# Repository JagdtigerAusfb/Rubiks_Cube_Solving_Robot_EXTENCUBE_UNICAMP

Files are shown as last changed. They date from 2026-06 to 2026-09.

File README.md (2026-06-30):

# RAIDEN

This repository contains everything related to the Rubik's Cube solving robot, **Raiden** and its second version: **Tupã**. This project was developed as an extension project at the State University of Campinas (UNICAMP).

## Introduction

The goal of this project was to develop a simple Rubik's Cube solving robot using accessible, easy-to-use, and relatively inexpensive components.This was achieved by building our first bot: the RAIDEN, named after the Japanese god of thunder, shown in the picture below. After its completion, the second iteration, the TUPÃ, named after Tupi-Guarani mythology, also shown in the picture below, was built using more expensive components, with the goal of minimizing completion times.

The RAIDEN achieved a record time of 1.82 seconds using a 19-move solution, running at a speed of 750 µs.

The TUPÃ achieved a record time of X.XX seconds using a 19-move solution, running at a speed of XXX µs.

See a video of the completed robot in action below: 

[Insert Video Link Here]

## Documentation & Guides

* Read the **[README]** files contained in each directory for details on each of the bot's parts. 
* Read the **[User's Manual]** for a full description of the parts, the complete bill of materials, and relevant technical documentation.
* Read the **[Build Tutorial]** for a step-by-step guide on how to build and configure this project yourself.

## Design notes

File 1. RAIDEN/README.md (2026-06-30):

# RAIDEN

**[WORK IN PROGRESS]**

Repository with all the material for **Raiden**, a Rubik's Cube solving robot developed as an extension project at UNICAMP. The goal is to solve the cube using 6 stepper motors (one per face), color sensors to read the cube's state, and an Arduino Mega as the central controller.

## Repository structure

```
1. RAIDEN/
├── 3D Files/              # 3D models of the robot's mechanical structure (in preparation)
├── PCB/                   # Circuit boards (KiCad projects)
│   ├── PCB 3 Drivers/
│   ├── PCB Drivers + Sensores/
│   └── PCB TUPAN/
└── Software/              # Arduino firmware and PC control applications
    ├── arduino/
    ├── Cube3D/
    └── CubeApp/
```

### `3D Files/`
Folder intended for the mechanical structure's 3D modeling files (chassis, motor mounts, base, etc.). See **[PCB/README.md](3D/README.md)** for details on the files.

### `PCB/`
KiCad projects for the robot's Printed Circuit Board desgins. See **[PCB/README.md](PCB/README.md)** for board details and pinout.

### `Software/`
All the code that runs the robot: the Arduino firmware and Python files. See **[Software/README.md](Software/README.md)** for details.

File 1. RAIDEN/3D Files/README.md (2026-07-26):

# 3D Files
This directory contains all the 3D files of the bot.

## Final Product
The assembled bot measures XX by XX by XX centimeters. Note that behind each side motor there is space for a rectangular piece that prevents the motor from sliding backwards — we highly recommend using it.
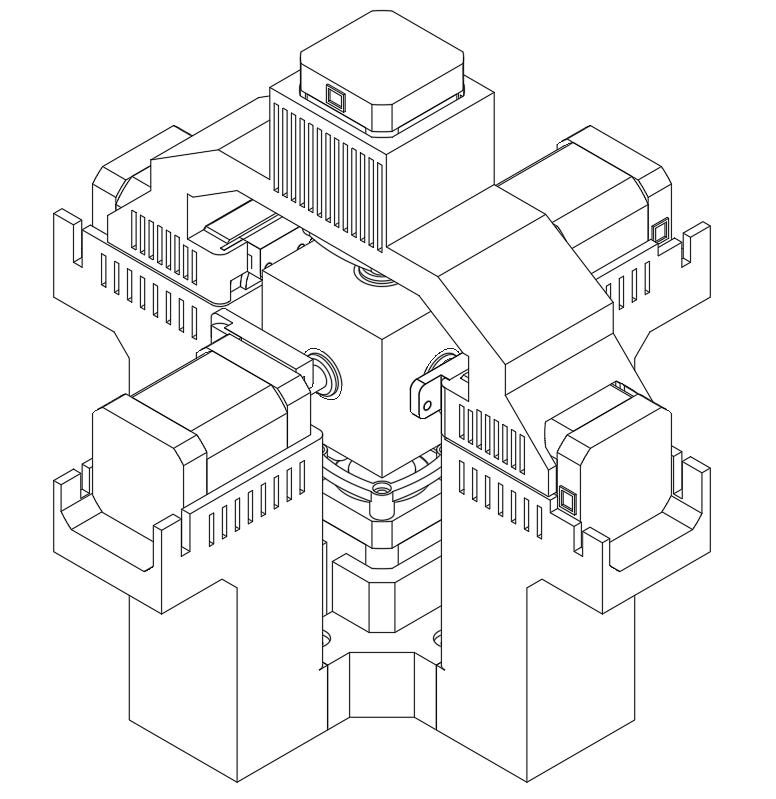
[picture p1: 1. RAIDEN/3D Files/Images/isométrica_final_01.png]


The following are the individual parts:

## The Claw
Our stepper motor has a fully cylindrical shaft, which made it very difficult to secure the claw firmly in place. If your stepper motor has a chamfered shaft — which we highly recommend — you will need to modify the claw design to fit it.
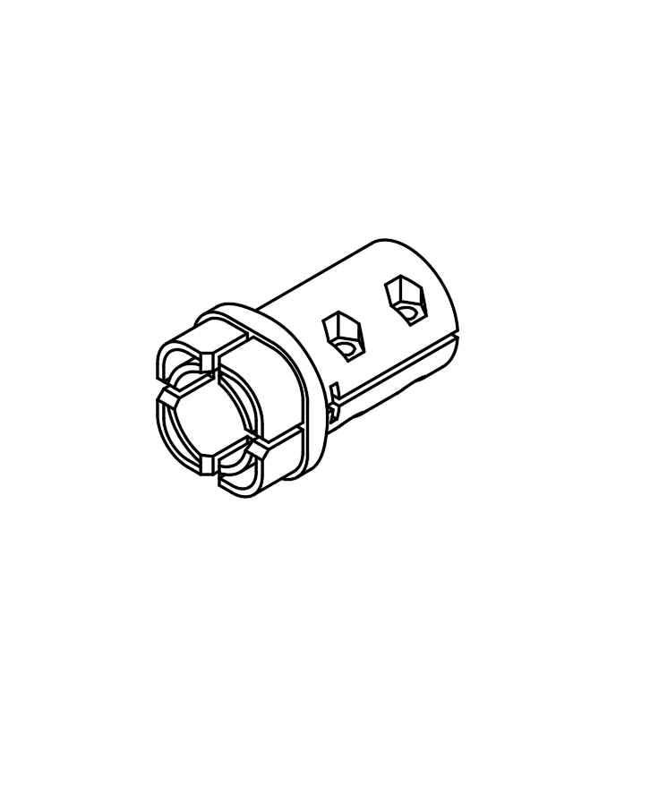
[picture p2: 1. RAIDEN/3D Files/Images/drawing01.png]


## The Tower
Four of these towers support each side motor and are bolted to the main piece using XX bolts.
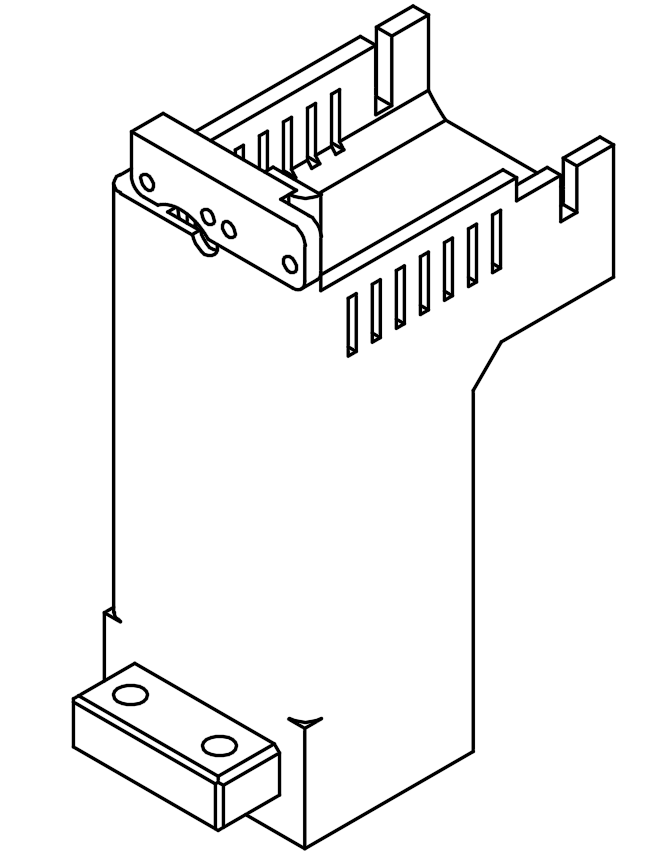
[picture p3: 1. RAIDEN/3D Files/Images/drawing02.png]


## The Base
A motor is placed inside this base facing upward, and the four towers attach to each of its sides.
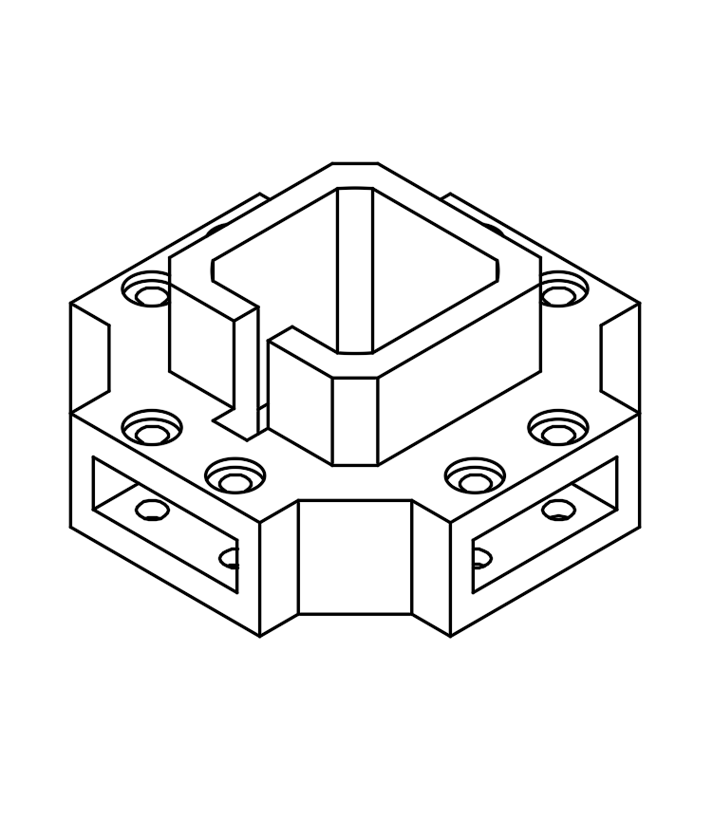
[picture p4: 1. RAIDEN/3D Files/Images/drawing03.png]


## The Top
The top piece sits on top of two opposing motors, with the last motor mounted inside it, facing downward.
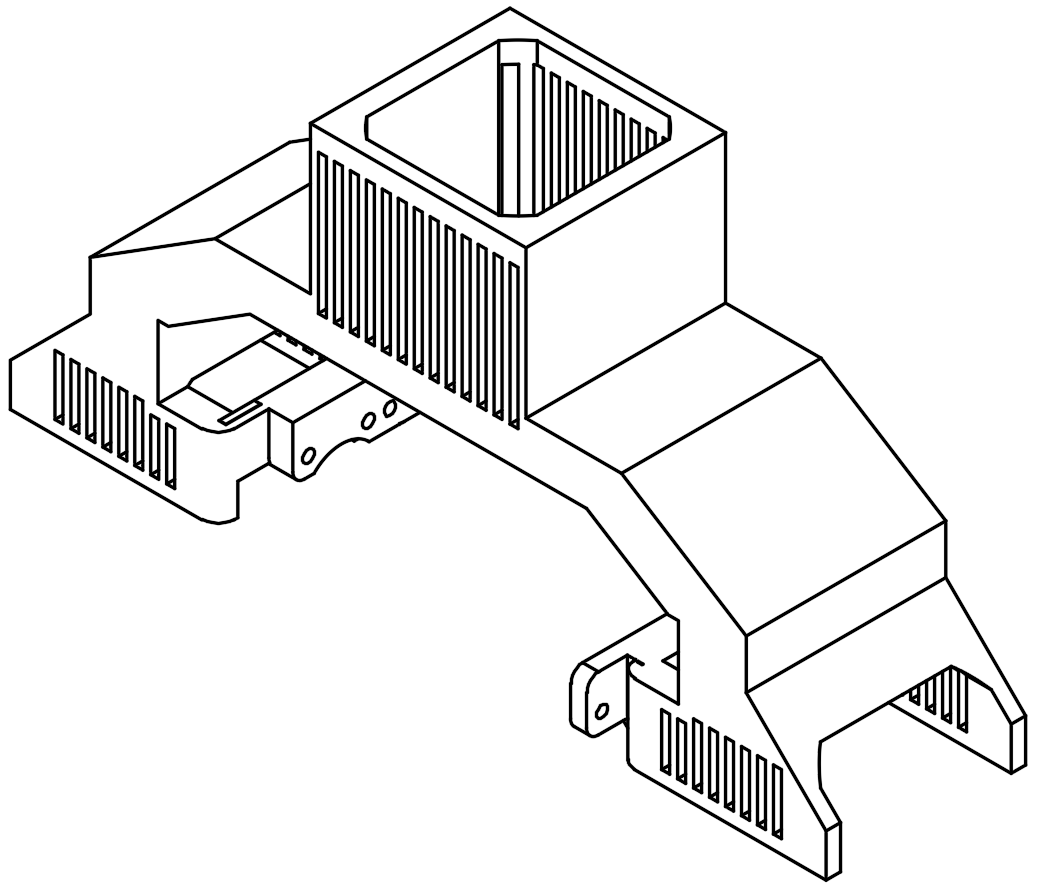
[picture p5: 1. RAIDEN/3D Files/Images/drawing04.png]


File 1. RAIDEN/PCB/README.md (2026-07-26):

# RAIDEN — PCB

KiCad projects for Raiden's electronics.

## Boards

### `PCB Drivers + Sensores/` — Main board
Shield for the **Arduino Mega**, responsible for all the power delivery and sensor reading in the robot:

- **6x A4988 stepper motor drivers** (Pololu modules), one for each face of the cube
- **12x connectors for TCS34725 color sensors**
- **1x CD74HC4067 multiplexer** to manage the 12 I²C sensor inputs
- 2x 12 V DC jack connectors (redundant power supply; using both is recommended to avoid voltage drops and motor stalling)
- Indicator LEDs (per driver and per power rail) and a reset button — both optional
- Decoupling capacitors on the drivers — **strongly recommended**, even though optional

The folder includes the complete KiCad project (schematic, PCB, custom footprints), fabrication files (Gerber, drill, BOM, component positions in `production/`), and the board's 3D model (`.step`).

### `PCB 3 Drivers/`
A simpler board with only **3 A4988 drivers**, made before the definitive board (Drivers + Sensores) to replace breadboards and reduce wiring.

As this board does not have a fixed pin layout, remember to change the respetive pins to the ones you are using in Arduino IDE.

## Reference pinout (Drivers + Sensores board)

**A4988 drivers** (DIR / STEP / ENABLE pins):

| Driver | DIR | STEP | ENABLE |
|---|---|---|---|
| 1 | A0 | A1 | A2 |
| 2 | A3 | A4 | A5 |
| 3 | A6 | A7 | A8 |
| 4 | 53 | 51 | 49 |
| 5 | 43 | 41 | 39 |
| 6 | 29 | 27 | 25 |

Microstepping pins (MS) are left disconnected, and RESET/SLEEP are tied together — this only works because the drivers used have internal pull-up/pull-down resistors.

**TCS34725 sensors** (LED control pin on the Arduino): 13, 12, 11, 10, 9, 8, 14, 15, 16, 17, 18, 19 (sensors 1 through 12, respectively).

**CD74HC4067 multiplexer** (selection): S0=5, S1=4, S2=3, S3=2. Inputs C0–C11 connected to signals SDA_1 through SDA_12.

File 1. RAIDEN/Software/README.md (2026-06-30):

# RAIDEN — Software

This folder contains all the software for our first Rubik's Cube solving robot: the **Raiden**, the Arduino firmware that drives the motors, and two separate Python applications used to control the robot from a PC.

## Repository structure

```
Software/
├── arduino/        # Firmware that runs on the Arduino Mega
├── Cube3D/         # OpenGL 3D viewer + manual/serial control app
└── CubeApp/        # PyQt6 GUI with camera-based cube scanning (main application)
```

### `arduino/arduino.ino`
Firmware for the **Arduino Mega**, controlling the 6 A4988 stepper drivers (one per face: U, R, F, D, L, B). It listens on serial (9600 baud) for a simple text protocol:

- `<START>` — begins a new move sequence
- `<SPEED:n>` — sets the step pulse delay in microseconds
- `<DELAY:n>` — sets the delay between moves in milliseconds
- One line per move, using a single-letter code (`A`–`R`, 3 codes per face: CW, CCW, 180°)
- `<END>` — executes the buffered sequence and replies `DONE <seconds>` when finished

As an optimization, opposite faces (e.g. U/D, F/B, L/R) detected as consecutive moves are driven **simultaneously** (`executarDuplo`) instead of sequentially, reducing total solve time. The `.ino` file must be uploaded manually through the Arduino IDE — it is not flashed automatically by the PC software.

### `Cube3D/`
A OpenGL/Pygame application that renders an interactive 3D Rubik's Cube on screen and can drive the physical robot over serial. This application was made for demonstration purposes and can be used to directly control the motors using a keyboard.

- `main.py` — window/render loop, keyboard controls for manual face rotations
- `cube/rubiks_cube.py` — cube data model and 3D rendering of each cubie
- `cube/solver.py` — wraps the `kociemba` solver and converts its output into the robot's serial move codes
- `robot/controller.py` — serial connection handling (auto-detects COM port) and move dispatch, mirroring the Arduino protocol above
- `ui/hud.py`, `ui/settings.py` — on-screen HUD/overlay and a Tkinter settings window for serial port/speed
- `config.py` — paths, color map, and the Kociemba → robot move-code lookup table
- `data/cube_state.json` — last saved cube state

### `CubeApp/` — main application
A PyQt6 desktop app that scans the physical cube with a webcam, solves it, and sends the solution to the robot. Pages are stacked in a `QStackedWidget` and flow as:

1. **`ui/cover.py`** — home/control panel: choose solver, set robot speed/delay, trigger solve & send
2. **`ui/calibration.py`** — lets the user position a 3×3 ROI (region of interest) grid over the cube face in the camera feed
3. **`ui/color_calib.py`** — captures reference color samples (HSV/Lab/RGB) for each of the 6 face colors, in the order defined by `COLOR_ORDER`
4. **`ui/capture.py`** — scans all 6 faces using the calibrated ROIs/colors and writes the result to `data/cube_state.json`

Supporting modules:

- `vision/camera.py` — OpenCV ↔ Qt frame conversion and ROI grid overlay
- `vision/classifier.py` — extracts mean HSV/Lab/RGB per cell and classifies it against the calibrated reference colors (nearest-neighbor via Euclidean distance)
- `solver/kociemba.py` — standard two-phase Kociemba solve
- `solver/m2op.py` — alternative M2/OP (blind-solving method) solver
- `solver/utils.py` — shared helpers: move counting, move inversion, and conversion to the robot's serial sequence
- `robot/controller.py` — same role as in `Cube3D`, but reads serial parameters (baud rate, timeouts, init delay) from `config.py`
- `config.py` — paths, color↔face mapping (`COLOR_TO_FACE`), Kociemba→robot `MOVE_TABLE`, and UI/serial defaults (e.g. `SERIAL_INIT_DELAY = 3` — required for the Arduino's DTR reset)

## Requirements

- **Arduino IDE** (or equivalent) to upload `arduino/arduino.ino`
- **Python 3.x**
- On Windows, **Microsoft Visual C++ Build Tools 14+** (required by some packages)

Python dependencies (install with pip):

```
pip install PyQt6 opencv-python numpy pyserial kociemba pygame PyOpenGL PyOpenGL-accelerate
```

| Library | Used for |
|---|---|
| `PyQt6` | GUI windows, layouts and widgets (`CubeApp`) |
| `opencv-python` | Camera capture and color-space conversion (BGR/HSV/Lab) |
| `numpy` | Array math and color-distance calculations |
| `pyserial` | Serial communication with the Arduino over USB |
| `kociemba` | Two-phase Rubik's Cube solving algorithm |
| `pygame` | Window/event loop for `Cube3D` |
| `PyOpenGL` / `PyOpenGL-accelerate` | 3D cube rendering in `Cube3D` |

Credit: solving logic built on top of the open-source [muodov/kociemba](https://github.com/muodov/kociemba) Python module.

## Running it

1. Open `arduino/arduino.ino` in the Arduino IDE and upload it to the Arduino Mega.
2. Install the Python dependencies listed above.
3. Run the main application:
   ```
   python CubeApp/main.py
   ```
5. Calibrate the ROI grid and reference colors (first run only), scan the cube, then solve and send the solution to the robot from the cover page.

`Cube3D/main.py` can be run the same way for the 3D-viewer/manual-control tool, but it expects `data/cube_state.json` to already contain a valid cube state (set externally or via the JSON file -- The solved cube state is given by: {"cube_string": **"UUUUUUUUURRRRRRRRRFFFFFFFFFDDDDDDDDDLLLLLLLLLBBBBBBBBB"}** ).

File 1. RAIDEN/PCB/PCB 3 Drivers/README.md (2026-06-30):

3DriversA4988

This board is a simple board to integrate only 3 A4988 drivers. It was made before the definitive board was finished. Use it if you want, or don't, I don't care.

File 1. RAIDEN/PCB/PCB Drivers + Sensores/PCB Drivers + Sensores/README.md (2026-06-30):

## Drivers & Sensors Shield

PCB Drivers + Sensores

This board functions as a custom shield for the **Arduino Mega**. It integrates everything needed to control the mechanics and inputs of the project:
* **6x A4988 Stepper Motor Drivers**
* **12x Color Sensor Connectors**
* **1x Multiplexer** (to handle the sensor inputs)

## Power Supply & Distribution

The system is powered by a 12V power supply with two output ports. **We strongly advise using both ports.** During testing, relying on a single port caused voltage drops, which resulted in some motors stalling. 

To distribute the current load evenly, the board features **two DC Jack connectors**. Each jack supplies 12V to a dedicated group of three motor drivers.

## A4988 Drivers

**Pin configuration:**

| Driver | DIR Pin | STEP Pin | ENABLE Pin |
| :--- | :---: | :---: | :---: |
| **Driver 1** | A0 | A1 | A2 |
| **Driver 2** | A3 | A4 | A5 |
| **Driver 3** | A6 | A7 | A8 |
| **Driver 4** | 53 | 51 | 49 |
| **Driver 5** | 43 | 41 | 39 |
| **Driver 6** | 29 | 27 | 25 |

Note that these are based on what was easiest to route on the board physicaly.

In this project, we only utilize the **DIR**, **STEP**, and **EN** (Enable) pins of the motor drivers. The configuration for the remaining pins is as follows:

* **Microstepping (MS Pins):** These pins are left disconnected.
* **RESET & SLEEP Pins:** These pins are tied together. 

This specific setup is possible because the drivers used in this project include internal **pull-up or pull-down resistors**, which stabilize the signals even when left unconnected. 

> [!CAUTION]
> These pins are not accessible in the current board design. If you decide to use a different or "equivalent" driver, ensure it also features internal pull-up/down resistors. Some simpler or cheaper versions of these drivers lack these resistors; in such cases, the pins **cannot** be left floating (unconnected), or the driver will not function correctly.

## Multiplexer (CD74HC4067) and Sensors (TCS34725)

### Sensors (TCS34725)

**Pin configuration:**

| Sensor | Pino do Arduino (LED Control) |
| :--- | :---: |
| **Sensor 1** | **13** |
| **Sensor 2** | **12** |
| **Sensor 3** | **11** |
| **Sensor 4** | **10** |
| **Sensor 5** | **9** |
| **Sensor 6** | **8** |
| **Sensor 7** | **14** |
| **Sensor 8** | **15** |
| **Sensor 9** | **16** |
| **Sensor 10** | **17** |
| **Sensor 11** | **18** |
| **Sensor 12** | **19** |

In this project, we only utilize the **VIN**, **GND**, **SDA**, **SCL**, and **LED** pins of the TCS34725 color sensors. The configuration for the remaining pins is as follows:

* **Interrupt (INT Pin):** This pin is left disconnected. 
* **3.3V Pin:** This pin is also left disconnected.

> [!NOTE]
> This configuration assumes you are using a standard TCS34725 breakout module (like the ones from Adafruit or similar clones) that includes a built-in voltage regulator and I2C pull-up resistors. If you are using a different, 3.3V-only version of the board, do not connect 5V to the power pins, as it will damage the sensor!

Note that these are based on what was easiest to route on the board physicaly.

## Multiplexer (CD74HC4067)

| Pino do MUX | Pino do Arduino (Mux Control) |
| :--- | :---: |
| **S0 (LSB)** | **5** |
| **S1** | **4** |
| **S2** | **3** |
| **S3 (MSB)** | **2** |

| Sinal SDA (Sensor) | Pino do Header | Entrada do MUX |
| :--- | :---: | :---: |
| **SDA_1** | JP1-1 | **C0** |
| **SDA_2** | JP1-2 | **C1** |
| **SDA_3** | JP1-3 | **C2** |
| **SDA_4** | JP1-4 | **C3** |
| **SDA_5** | JP1-5 | **C4** |
| **SDA_6** | JP1-6 | **C5** |
| **SDA_7** | JP1-7 | **C6** |
| **SDA_8** | JP1-8 | **C7** |
| **SDA_9** | JP1-9 | **C8** |
| **SDA_10** | JP1-10 | **C9** |
| **SDA_11** | JP1-11 | **C10** |
| **SDA_12** | JP1-12 | **C11** |
| *Not Connected* | JP1-13 | **C12** |
| *Not Connected* | JP1-14 | **C13** |
| *Not Connected* | JP1-15 | **C14** |
| *Not Connected* | JP1-16 | **C15** |

## Optional Components

 **Indicator LEDs:** There are LEDs (and their corresponding resistors) to indicate power from the two 12V jacks and the 5V line from the Arduino. Additionally, each A4988 driver has a dedicated LED to show when a step signal is being sent to the motor. You can safely exclude these if you prefer. 
 
 **Reset Button:** The board includes a physical Reset button for the Arduino. This can also be omitted.
 
 **Highly Recommended - Capacitors:** While the board might technically work without them, installing the decoupling capacitors for the motor drivers is **highly recommended**. They are crucial for preventing voltage spikes that can permanently damage the A4988 drivers.

## Comments

 > [!NOTE]
> The Arduino connectors in the PCB project are only female, but in reality they should be male and female connects (they should have the female connector on top and the male pins on the bottom to connect to the Arduino), the 3D model just shows the famele pins. Be carefull not to order the wrong connector!

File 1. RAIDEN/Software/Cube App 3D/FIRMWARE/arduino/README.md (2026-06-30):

# RAIDEN

**[WORK IN PROGRESS]**

Repositório com todo o material de hardware do **Raiden**, um robô solucionador de Cubo Mágico desenvolvido como projeto de extensão na UNICAMP. O objetivo é resolver o cubo usando 6 motores de passo (um por face), sensores de cor para leitura do estado do cubo, e um Arduino Mega como controlador central.

## Estrutura do repositório

```
1. RAIDEN/
├── 3D Files/              # Modelos 3D da estrutura mecânica do robô (em preparação)
└── PCB/                   # Placas de circuito (projetos KiCad)
    ├── PCB 3 Drivers/
    ├── PCB Drivers + Sensores/
    └── PCB TUPAN/
```

### `3D Files/`
Pasta destinada aos arquivos de modelagem 3D da estrutura mecânica (chassi, suportes dos motores, base, etc.). Por enquanto contém apenas o README original do projeto — os modelos ainda não foram adicionados.

### `PCB/PCB Drivers + Sensores/` — **Placa principal**
Shield para o **Arduino Mega**, responsável por toda a parte de potência e leitura de sensores do robô:

- **6x drivers de motor de passo A4988** (módulos Pololu), um para cada face do cubo
- **12x conectores para sensores de cor TCS34725**
- **1x multiplexador CD74HC4067** para gerenciar as 12 entradas I²C dos sensores
- 2x conectores Jack DC de 12 V (alimentação redundante, recomenda-se usar os dois para evitar queda de tensão e travamento de motores)
- LEDs indicadores (de driver e de alimentação) e botão de reset — ambos opcionais
- Capacitores de desacoplamento nos drivers — **fortemente recomendados**, mesmo sendo opcionais

A pasta inclui o projeto completo do KiCad (esquemático, PCB, footprints customizados), arquivos de fabricação (Gerber, drill, BOM, posições de componentes em `production/`) e o modelo 3D da placa (`.step`). O README específico dessa pasta detalha a pinagem completa dos drivers, sensores e multiplexador, além de avisos importantes sobre os conectores do Arduino e sobre versões do TCS34725 que não devem ser ligadas em 5 V.

### `PCB/PCB 3 Drivers/`
Placa mais simples, com apenas **3 drivers A4988**, feita antes da placa definitiva (Drivers + Sensores) estar pronta. É uma alternativa/protótipo intermediário, não obrigatória para o projeto final — segundo o autor, "use se quiser, ou não, eu não me importo".

### `PCB/PCB TUPAN/`
Placa em estágio inicial de desenvolvimento. Contém apenas o arquivo `.kicad_pcb`, ainda vazio (sem esquemático nem componentes posicionados). Aparentemente é a próxima revisão/placa planejada para o projeto, ainda não iniciada de fato.

## Pinagem de referência (placa Drivers + Sensores)

**Drivers A4988** (pinos DIR / STEP / ENABLE):

| Driver | DIR | STEP | ENABLE |
|---|---|---|---|
| 1 | A0 | A1 | A2 |
| 2 | A3 | A4 | A5 |
| 3 | A6 | A7 | A8 |
| 4 | 53 | 51 | 49 |
| 5 | 43 | 41 | 39 |
| 6 | 29 | 27 | 25 |

Pinos de microstepping (MS) ficam desconectados e RESET/SLEEP são amarrados juntos — isso só funciona porque os drivers usados têm resistores de pull-up/pull-down internos.

**Sensores TCS34725** (pino de controle do LED no Arduino): 13, 12, 11, 10, 9, 8, 14, 15, 16, 17, 18, 19 (sensores 1 a 12, respectivamente).

**Multiplexador CD74HC4067** (seleção): S0=5, S1=4, S2=3, S3=2. Entradas C0–C11 ligadas aos sinais SDA_1 a SDA_12.

Detalhes completos, observações de hardware e ressalvas estão nos READMEs de cada subpasta de PCB.

## Status do projeto

- ✅ Placa "Drivers + Sensores" — projeto completo, com arquivos de fabricação prontos
- ✅ Placa "3 Drivers" — protótipo funcional, opcional
- 🚧 Placa "Tupan" — apenas iniciada
- 🚧 Modelos 3D — ainda não adicionados ao repositório
- 🚧 Vídeo de demonstração e manual do usuário/tutorial de montagem — pendentes (ver `3D Files/README.md`)

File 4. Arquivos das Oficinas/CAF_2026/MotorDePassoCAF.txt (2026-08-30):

/**********************************************************************************/
/*********************Oficina - Rôbo Cubo Mágico - Motores*************************/
/***************Pedro Ortolan - Guilherme Ramalho - Paulo Ségio********************/
/******************************2º Semestre 2025************************************/
/************************************1/2*******************************************/
/**********************************************************************************/

/*O objetivo desse código é rodar um motor de passo NEMA17 utilizando um driver A4988*/

/*Usamos a serial do arduino para variar a velocidade do motor, mas isso poderia ser 
feito manualmente alterando o valor do último delay e reescrevendo o programa na placa.
Ou seja, essa parte não é necessária para girar o motor.*/

/*
************Caracteristícas do driver A4988***************************************

(Pinos com / na frente são ativados em nível lógico baixo)

Pinos que operam em baixo por padrão possuem os chamados resistores de pull-down internamente. Esse resistor apenas conecta 
aquele pino a um terra internamente e, assim, o pino permanece em valor baixo por padrão.

Pinos que operam em alto por padrão possuem os chamados resistores de pull-up internamente. Esse resistor apenas conecta 
aquele pino a um +Vcc de 5V internamente e, assim, o pino permanece em valor alto por padrão.

-> Pino de /SLEEP ativado em high por default, pino /RESET floating --> ligar o /SLEEP no /RESET para manter ambos desligados;
-> Pinos de MICROSTEP em baixo por padrão, deixar sem nada resulta em full step;
-> /ENABLE em high por padrão

-> Para acionar o motor, devemos controlar dois pinos do driver A4988: o de STEP e de Direção

-> O pino de STEP faz o motor girar um passo cada vez que seu valor transita de 0 para 1 (sensível a borda de subida)

-> O pino de direção define a direção do motor, com HIGH sendo para um lado, e LOW para o outro. Para saber qual lado
é qual, teste no motor e veja para qual lado ele roda em cada caso.

*/

//Código em si:
/***************************************************************************************************************************/

/*A primeira coisa que fazemos no código é a declaração das variávies usadas*/

/*Essas duas variáveis recebem os valores dos pinos de Direção e STEP usadas fisicamente no arduino.
Note que podemos usar diretamente os valores dos pinos nas funções, mas para alterar todos de uma vez,
caso seja necessário alterar o pino usado, definir uma variável deixa isso mais fácil.*/
int DIR_PIN = 2; 
int STEP_PIN = 3;

//Essas variáveis são usadas na sérial, ignore
int novoValor = 0;
int valorAtual = 1000;

/*Função setup (roda apenas uma vez na inicialização do programa)*/
void setup() {

  /*pinMode define o respectivo pin como entrada (INPUT) ou
  saída (OUTPOT). É importante que isso seja feito para a porta
  operar de fato no modo que queremos.*/
  pinMode(STEP_PIN, OUTPUT);
  pinMode(DIR_PIN, OUTPUT);

  /*O LED_BUILDIN é o led incorporado ao arduino e pode ser controlado
  setando seu pino como output (podemos usar seu nome diretamente no lugar 
  do valor do pino)*/
  pinMode(LED_BUILTIN, OUTPUT);

  /*A função de digitalWrite define um pino de saída como LOW ou HIGH
  No nosso caso, define a direção de rotação do motor alterando o valor
  do pino de direção (troque HIGH/LOW para inverter)*/
  digitalWrite(DIR_PIN, HIGH);     

  /*ignore se não estiver usando a serial*/
  /*Para usar a serial, precisamos primeiro definir a taxa de trasmissão de bits que
  será usada por ambos o transmissor e pelo receptor, tal que estes estejam sincronizados.
  Essa função define então a taxa, conhecida como Baud Rate, para 9600 bits por segundo*/
  Serial.begin(9600);

  Serial.println("Insira um número para definir a velocidade do motor.");
  Serial.println("Por padrão é 1000 milisegundos.");
  Serial.println("Note que o valor só não é atualizado entre os passos, então se um valor muito alto for colocado teremos que esperar esse tempo até ele atualizar. Só reinicie a simulação se isso acontecer.");
  
}

/*A função loop roda, em loop, eternamente enquanto o dispositivo estiver ligado*/
void loop() {

  /*Usando um motor de 1.8º por passo, se queremos que o motor gire 90º graus, fazemos 90/1.8 = 50 passos.
  Assim, fazemos um loop que aciona o pino de STEP 50 vezes*/

  for (int i = 0; i < 50; i++) // gera 50 pulsos de step (1.8 * 50 = 90)
    {
    digitalWrite(STEP_PIN, HIGH);           // Liga o motor ao setar o pin de step como high, cada setamento desse pino faz passar um passo
    digitalWrite(LED_BUILTIN, HIGH);        // Liga o led do arduino para indicar que passou um passo
    delayMicroseconds(1000);                // Espera T ms entre os passos (esse valor depende do torque do motor)
    digitalWrite(STEP_PIN, LOW);            // seta pin como low para mandar o próximo passo ao escrever high de novo no proximo loop
    digitalWrite(LED_BUILTIN, LOW);         // Desliga o led 
    delayMicroseconds(1000);                // Espera mais Tms (na prática espera 2 x Ts entre passos)
    }

    /*Essa parte é da serial, ignore*/
    if (Serial.available() > 0) {
    int novoValor = Serial.parseInt();   // tenta ler inteiro
    if (novoValor != 0) {                // só atualiza se realmente recebeu algo
      valorAtual = novoValor;
      Serial.print("Novo valor recebido: ");
      Serial.println(valorAtual);
    }
  }

/*O valor entre os passos de 90º pode ser aumentado enviando um número
para a serial, default é 1000 e mínimo é 1. Note que o valor só não é atualizado entre
os passos, então se um valor muito alto for colocado teremos que esperar esse tempo
até ele atualizar. */
delay(valorAtual);
}

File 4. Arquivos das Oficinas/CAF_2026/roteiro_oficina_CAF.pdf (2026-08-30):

# CAF 2026

Não se preocupe em entender 100% desse pdf. Chame os monitores sempre que tiver dúvidas.

## Circuitos Elétricos

A figura 1 mostra o circuito elétrico mais simples que pode ser construído. Nele, temos três elementos fundamentais: a fonte de alimentação, marcada em V . Pense nela como a tomada. A corrente elétrica que circula pelo circuito, marcada em I. E finalmente a resistência, marcada em R. Essa resistência pode, por exemplo, uma lâmpada, em poucas palavras, é o objeto que recebe a energia da nossa fonte.

Vale notar que todo circuito elétrico deve ser um loop fechado. Perceba que a corrente elétrica tem que sair da fonte de alimentação pelo + e retornar a ela pelo −.

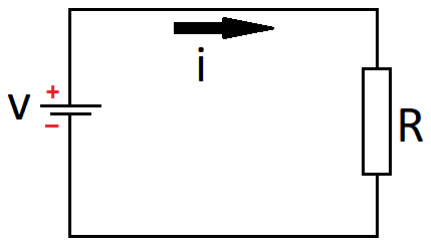
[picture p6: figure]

Figura 1: Circuito Elementar

Vamos descrever então os componentes elétricos que serão usados em nossos circuitos.

### 1 Resistor

O resistor só serve para uma coisa, resistir corrente elétrica. Ele garante que a corrente não vai aumentar a um valor absurdo e destruir o circuito. Ele é portanto bem importante. Note que o valor de resistência do resistor (a medida de o quanto ele resiste a correte) pode ser lido no corpo do resistor através das corres pintadas nele, como mostra a figura 2. Não se preocupe em realmente ler o código, apenas fique atento para colocar o resistor de cor certa no lugar certo durante a montagem. Note que o resistor não tem "lado certo"para montar, pode ser colocado de qualquer orientação.

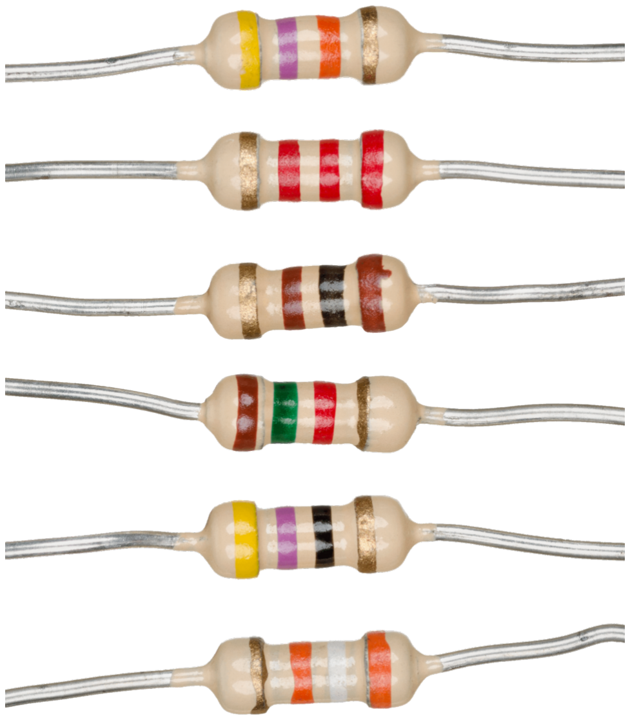
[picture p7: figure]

Figura 2: Resistores de valores diversos

### 2 LDR (light dependent resistor - resistor depende de luz)

O LDR é um resistor cujo valor depende da quantidade de luz absorvida por ele. Quanto mais luz, menor a resistência a corrente elétrica. A figura 3 mostra um LDR. Ele também não possui orientação certa.

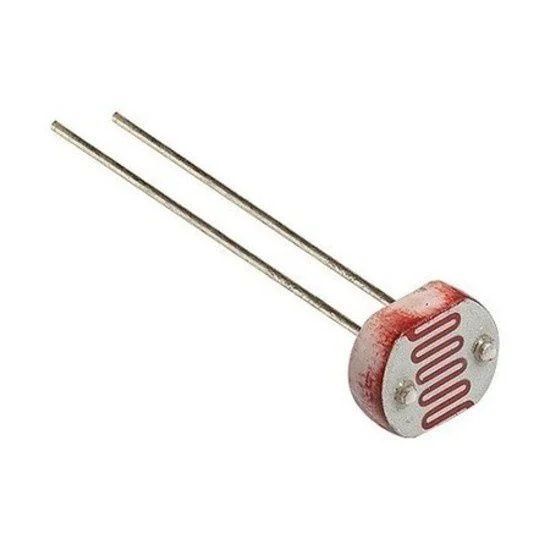
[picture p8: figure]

Figura 3: LDR

### 3 LED RGB

Um LED é como uma lâmpada, quando energia passa por eles, eles brilham. Um LED RGB pode brilhar com três cores: vermelho, verde ou azul, e qualquer combinação dessas três cores. O LED RGB possui 4 "pernas"como visto na figura 4. A perna marcada em vermelho faz o LED brilhar vermelho se energia for aplicada nela. A perna verde e azul possuem comportamento similar. Perceba podemos ligar múltiplas pernas ao mesmo tempo para obter combinações dessas cores. Ligar todas as pernas resulta em branco. Note também a perna marcada (−). Ela serve para fechar o loop do nosso circuito e normalmente é a maior entre as pernas.

Perceba que o LED RGB possui então uma conexão especifica, e, ao contrário dos componentes anteriores, não pode ser conectado de qualquer forma.

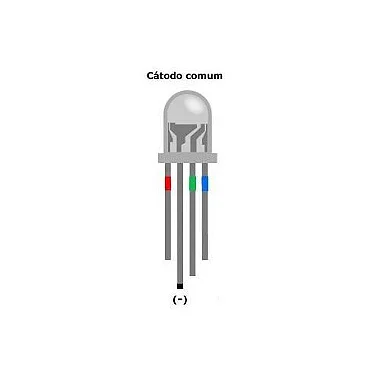
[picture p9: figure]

Figura 4: LED RGB

## O Arduino

O Arduino é que o chamamos de um microcontrolador. Na prática, ele é um minicomputador. Existem diversos modelos de arduinos, o que usaremos é o arduino uno. A figura 5 mostra o layout de um arduino uno. Usaremos ele para comprimir duas funções: primeiro, como fonte de alimentação do nosso circuito, a "tomada". Segundo, como o "cérebro"que executa os códigos que usaremos.

Pela figura 5, primeiro temos em 1 a alimentação do arduino, feita por USB. Essa entrada também serve para salvar nosso código na memoria do arduino, para que ele execute o que queremos.

Em 2, temos o botão de reset, que serve para reiniciar o processador, assim como reiniciar qualquer computador.

Ignore os pinos de 3.

Em 4, temos os pinos de alimentação. Esses pinos servem para que o arduino supra energia para nosso circuito. Assim, como uma tomada supre 110 volts ou 220 volts, a porta 5V supre 5 volts e a porta 3, 3V supre 3,3 volts. As portas de GND (ground) se referem ao terra do nosso circuito. Lembre-se que todo circuito elétrico deve ser um loop fechado, assim, a energia deve sair de um pino 5V e fechar o loop em um pino de GND.

Em 5, temos as entradas e saídas digitais. Essas portas podem ser usadas como entradas ou saídas e são controladas pelo nosso programa. Agindo como saídas (de energia), essas portas podem ser ligadas ou desligadas pelo programa para emitir 5 volts ou emitir nada, respectivamente. Pense em uma tomada que você pode ligar ou desligar. Quando entradas, o arduino vai "ler"essas portas para ver se há energia nelas ou não, e, de acordo com a leitura, o programa realiza ou não o que foi programado.

Em 6, temos as portas de entrada e saída analógicas. Sua diferença para as de 5 está apenas em quando funcionam como entradas. Nessa situação, o arduino não lê apenas se há ou não energia, mas sim quanto de energia há.

Em 7, temos o microprocessador em sí, ou seja, nosso computador.

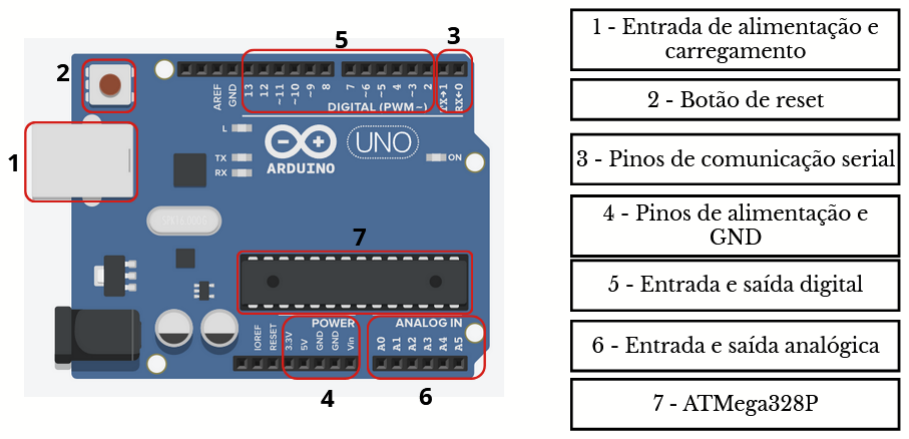
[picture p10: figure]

Figura 5: Layout do Arduino

## A Protoboard

Protoboards são placas de prototipagem de circuitos elétricos amplamente usadas na engenharia elétrica e é onde nos montaremos nossos circuitos. A imagem 6 mostra na direita o esquemático de um circuito genérico e a esquerda sua versão física montada em uma protoboard. Para entender como essa tradução é feita entendendo o layout dos pinos da nossa placa.

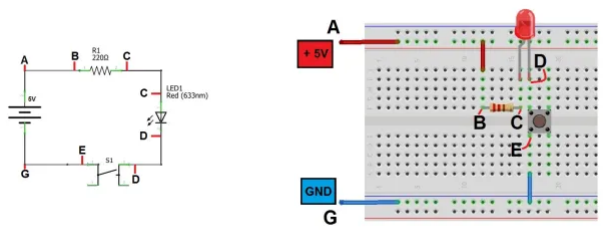
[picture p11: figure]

Figura 6: Esquemático e versão física do circuito

A figura 7 mostra a ligação interna de uma protoboard. As linhas em cima dos pinos indicam que esses pinos estão ligados juntos internamente.

Primeiro, note que as linhas + e − nas bordas da placa estão conectadas todas juntas horizontalmente. Usamos essas trilhas para alimentação do nosso circuito. No nosso caso, essa alimentação vem do nosso Arduíno. Especificamente dos pinos +5V , +3, 3V e GND.

Note agora as trilhas marcadas com a, b, c, d, e e f, g, h, i, j. Essas trilhas são conectadas juntas verticalmente, de acordo com a numeração de 1 a 30, sendo separadas no meio da placa. Na figura 6, veja a conexão entre A e B. Na placa, o A é conectado nas trilhas nas bordas da placa, e então conectada a uma coluna para conectar A em B.

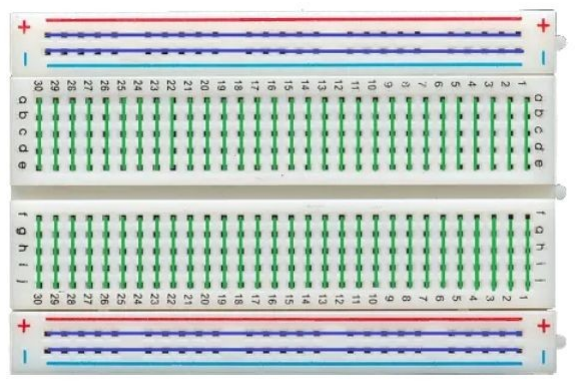
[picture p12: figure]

Figura 7: Layout da Protoboard

## Funcionamento Motor De Passo

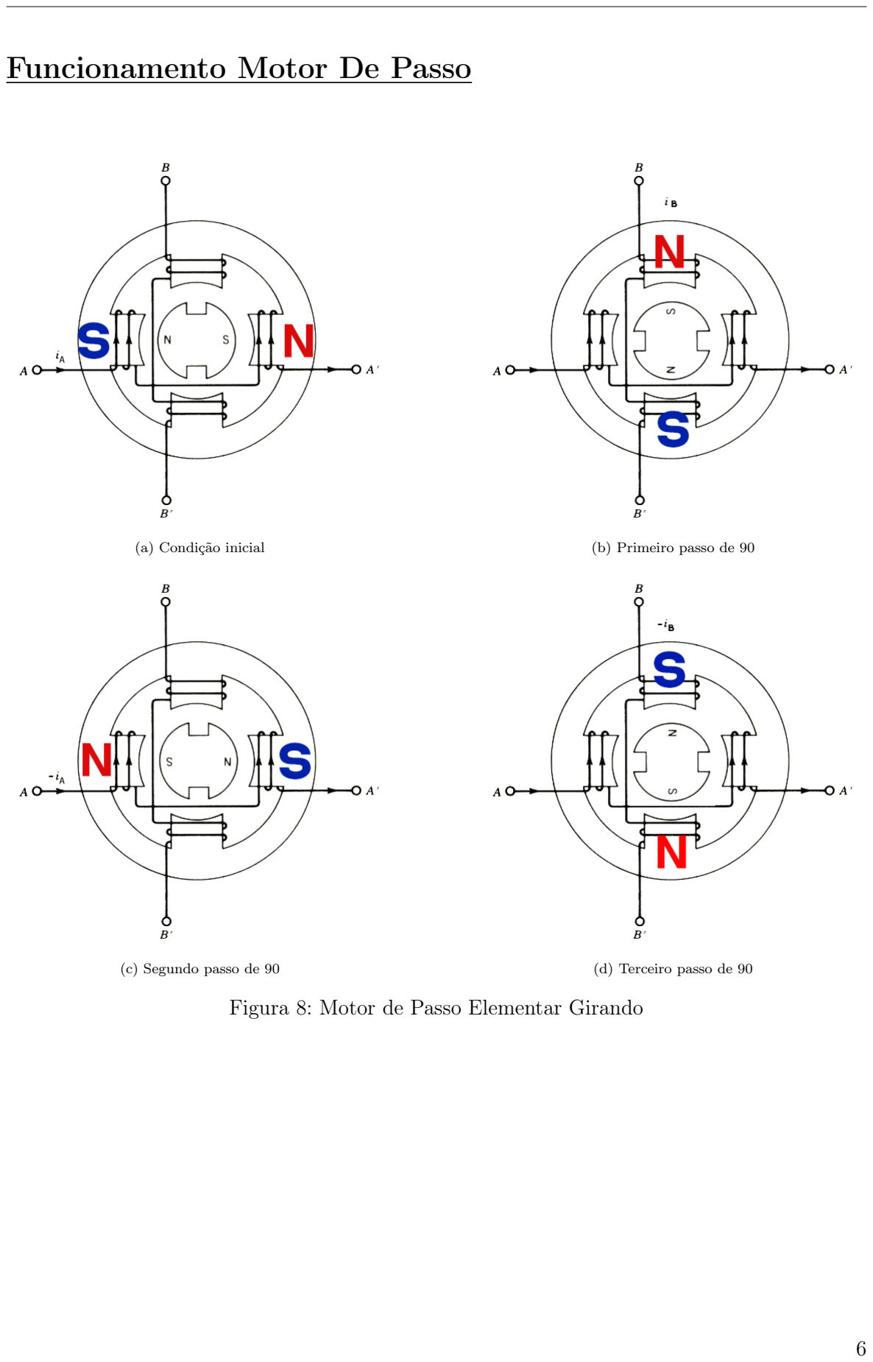
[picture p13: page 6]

(a) Condição inicial | (b) Primeiro passo de 90
(c) Segundo passo de 90 | (d) Terceiro passo de 90

Figura 8: Motor de Passo Elementar Girando

## Partes Práticas

## Carregando um Código no Arduino - Arduino IDE

O arduino IDE é o software que usamos para salvar no arduino o código que programamos. Ao abrir ele, você deve ver algo similar a figura 9.

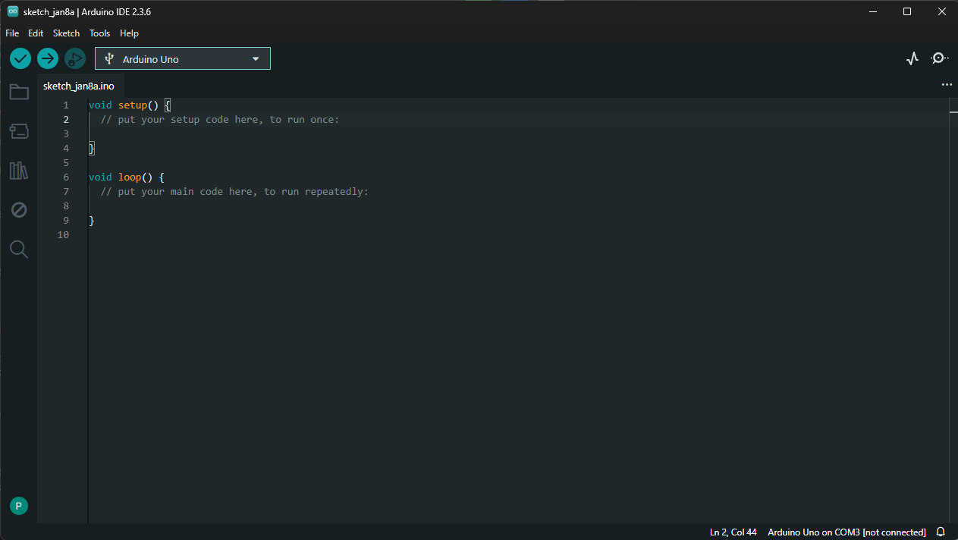
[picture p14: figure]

Figura 9: Arduino IDE

Copie (CTRL+C) e cole (CTRL+V) o respectivo código indicado pelos monitores. Lembre-se de deletar tudo que já vem escrito (void setup e void loop). Use CTRL+A para selecionar tudo e deletar de uma vez. Com o código colado, você pode conectar o arduino ao computador utilizando seu cabo USB. Ao conectar, o Arduino IDE deve detectar automaticamente o arduino, mas não automaticamente selecionar ele. Clique na caixa na parte superior para selecionar o seu arduino. Com o arduino selecionado, como na imagem abaixo, você pode clicar no botão da seta para dar upload. Chame um monitor se tiver dúvida.

Figura 10: Botão de upload e botão de seleção da placa

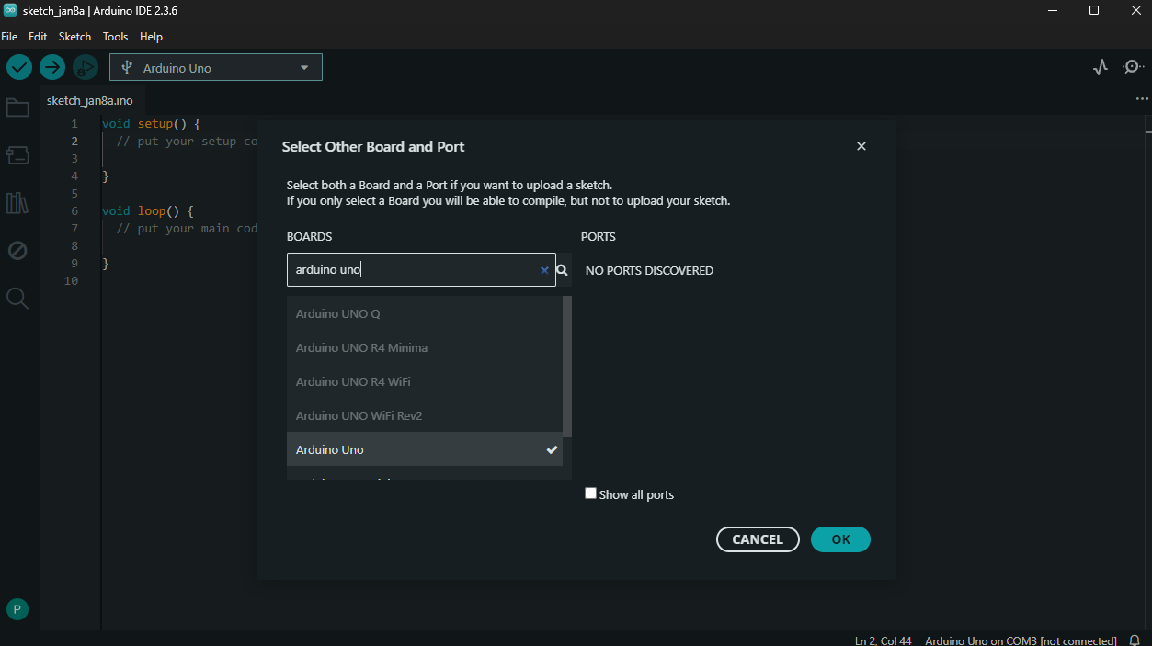
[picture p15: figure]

Figura 11: Selecione a placa Arduino Uno

## Montagem Circuito dos Sensores

Com as orientações dos monitores e referência desse documento, monte o circuito da figura 12. Chame um monitor para verificar quando acabar.

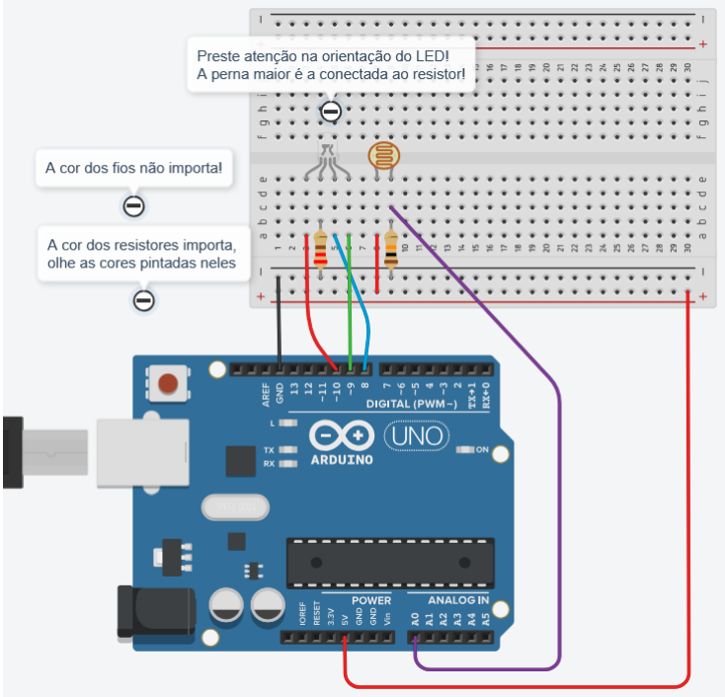
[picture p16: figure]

Figura 12: Circuito dos sensores

## Motores de Passo - Simulador Wokwi

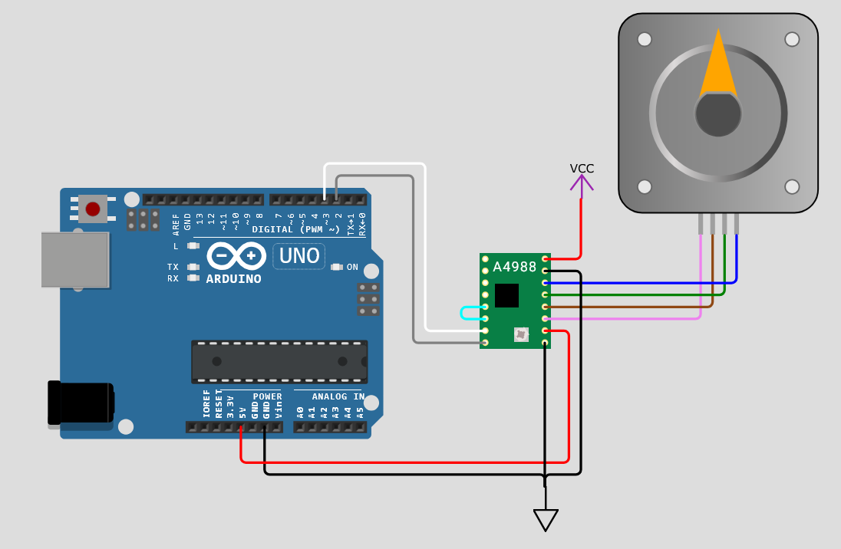
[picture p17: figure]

Figura 13: Simulador Wokwi: Circuito para motor de passo

Use (https://wokwi.com/projects/453257981713926145) para acessar o simulador para a parte dos motores de passo. As orientações estão nos comentários do código.

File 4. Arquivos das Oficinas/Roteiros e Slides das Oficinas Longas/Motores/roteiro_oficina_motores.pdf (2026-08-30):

## Roteiro da Oficina 5: Motores de Passo

## ETAPA 0 - Introdução a Máquina Elétricas

Máquinas elétricas, mais especificamente máquinas elétricas conversoras de energia são máquinas que fazem exatamente isso, convertem energia. Essa conversão é feita através de fenômenos magnéticos. Apesar de nosso foco ser apenas o motor, vale mencionar as outras máquinas.

### 1 Transformador

O transformador não é exatamente uma máquina que converte energia, mas podemos pensar nele como uma. Sua principal função é elevar ou abaixar o nível da tensão, e seu principal parâmetro é a chamada relação de transformação.

Tomemos como exemplo um transformador com uma relação de transformação de 1 para 5 (1:5). Isso significa que, para cada volt na entrada do transformador, em sua saída teremos 5 volts. Assim, se uma fonte de 20V for colocada em suas entrada, teremos 100V na sua saída.

Note que o transformador não possui lados específicos, ou seja, se a fonte de 20V fosse colocada na saída, teríamos na entrada 4V - estaríamos fazendo, ao invés de 1:5, 5:1. Em outras palavras, o transformador não possui uma entrada e saída fixas, podemos usar ambos os lados como entrada e o outro lado fica como nossa saída, com a relação de transformações correspondente.

Mas perceba que estaríamos criando ou destruindo energia do nada se o transformador apenas aumentasse ou abaixasse nossa tensão sem mudar mais nada. Para compensar a variação de tensão, teremos que nossa corrente varia de forma inversamente proporcional. Assim, para uma relação de 1:10, se para um entrada de 10V e 1A, teríamos na saída 100V mas apenas 0, 1A. Note que essa relação mantêm a potência da saída igual a da entrada, como mostra a equação 1.

Pin = V · I =⇒ Pout = 10V ·

I
10
= V · I = Pin | (1)

Por fim, podemos pensar que o transformador apenas converte energia elétrica em energia elétrica. A figura ?? mostra um circuito com um transformador, com seus respectivos valores de tensão e corrente. Vale também notar que o transformador é uma máquina estática, ou seja, não possui partes que se mexem, em contraste às próximas máquinas que veremos.

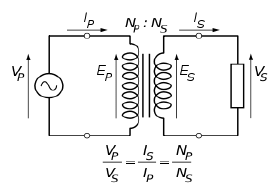
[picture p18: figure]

Figura 1: Transformador

### 2 Motor e Gerador

Se você quiser impressionar alguém com seus conhecimentos de elétrica, explique como o motor e o gerador na verdade são a mesma máquina. De acordo com um professor nosso, ele fez isso com uns executivos importantes. Eles ficaram tão impressionados que deram um emprego para ele em uma empresa enorme e ele se tornou o homem mais rico do mundo. Ai ele acordou.

Como esse fato é importantíssimo, vou coloca-lo dentro de uma caixa de texto bonitinha.

O GERADOR E O MOTOR SÃO A MESMA MÁQUINA!

O motor e o gerador são a mesma máquina fisicamente, o que difere um do outro é o tipo de energia que este vai converter. O motor possui a função de converter energia elétrica em energia mecânica, enquanto o gerador faz o inverso, convertendo energia mecânica em energia elétrica. O que define que função a máquina vai cumprir é o tipo de energia colocada na máquina. O diagrama da figura 2 mostra essa relação.

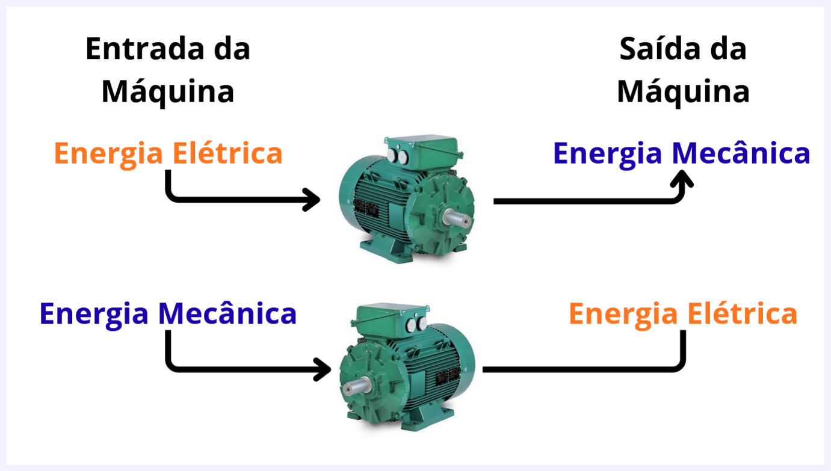
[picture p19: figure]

Figura 2: Motor x Gerador

Existem três tipos principais dessas máquinas: a máquina de corrente contínua (CC), a máquina de Indução e a máquina Síncrona. Ambas as máquinas de indução e síncronas funcionam com corrente alternada, enquanto que a maquina CC funciona com corrente CC. O motor de passo é um tipo especial de máquina CC, como veremos mais a frente.

A figura 3 mostra as máquinas que temos no laboratório de máquinas elétricas na Unicamp. Note que externamente elas são bem parecidas, quase idênticas.

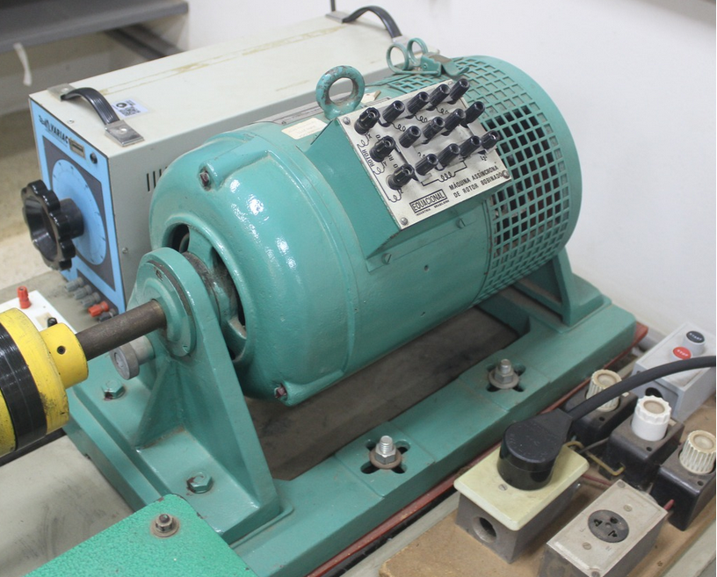
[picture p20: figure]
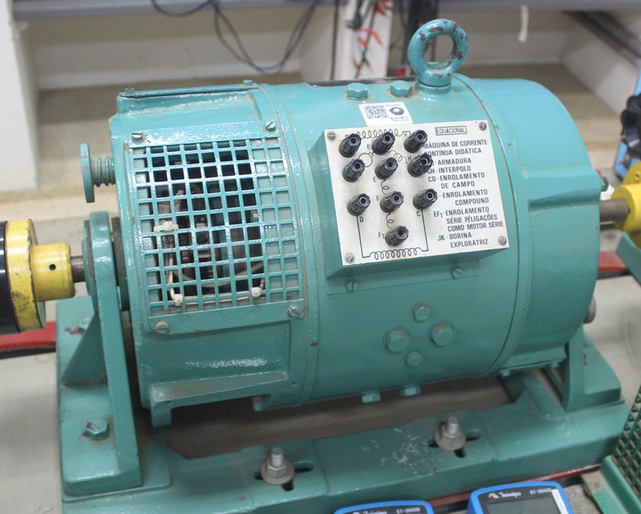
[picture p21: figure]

(a) Máquina CC | (b) Máquina de Indução

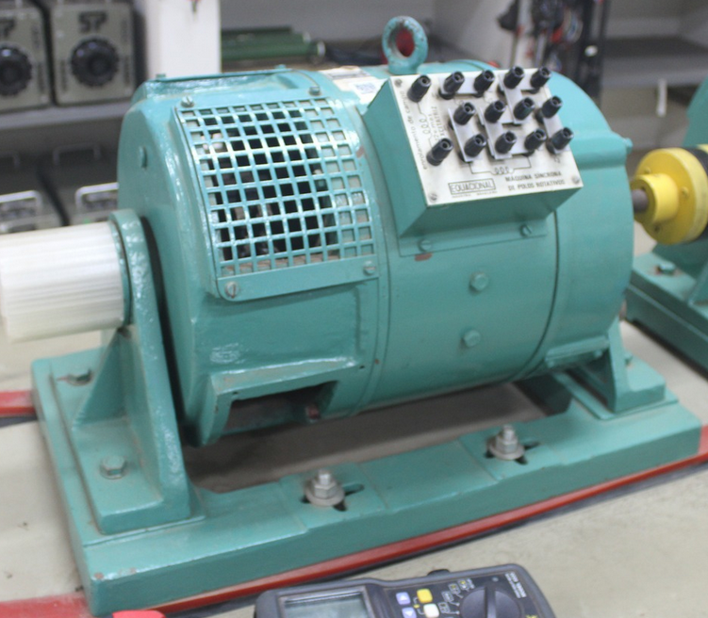
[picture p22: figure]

(c) Máquina Síncrona

Figura 3: Máquina Elétricas

## ETAPA 1 - Introdução aos Motores de Passo

### 3 Função básica

Um motor de passo é um motor. Isso significa que, como todo motor, ele possui a função de converter energia elétrica em energia mecânica. Em outras palavras, quando você ligar ele, ele gira. A principal diferença dele para outros tipos de motores está no jeito que ele gira.

Um motor de passo gira um número específico de graus em resposta a um impulso elétrico. Chamamos esse número de graus de passo do motor, daí o nome. Um motor de passo de 10 graus por exemplo, gira seu eixo, a cada impulso elétrico, 10 graus. Assim, podemos controlar facilmente e precisamente a posição do motor, podendo posiciona-lo em qualquer posição de 10 em 10 graus. Note que isso se da em contraste a motores convencionais, nos quais o controle da posição do motor costuma não ser tão simples. O grande controle dos motores de passo é portanto seu maior diferencial.

Os motores de passo são motores CC, ou seja, funcionam com corrente contínua. Esse fato, junto com seu fácil e preciso controle, tornam o motor de passo muito atraente para projetos de eletrônica que trabalham com Arduíno (como o nosso) e normalmente estão interessados em movimentos específicos e precisos. Uma outra alternativa seriam os chamados servomotores, que também são muito usados pelas mesmas razões, mas possuem um comportamento levemente diferente.

Por fim, veremos que os motores de passo são extremamente diversos em especificações, servindo assim qualquer projeto. Mas antes, vamos entender como esses motores funcionam.

### 4 Funcionamento do Motor de Passo

Existem três tipos de motores de passo: o de relutância variável, o de ímã permanente e o híbrido. O motor que usaremos para descrever o funcionamento será do tipo ímã permanente, mas os outros dois tipos funcionam de maneira bastante similar. Vamos então construir um motor de passo elementar.

A construção básica de qualquer máquina elétrica consiste em duas partes: o estator (a parte que fica parada) e o rotor (a parte que gira), nosso motor de passo não será diferente. Além disso, toda máquina elétrica utiliza de fenômenos magnéticos para obter ou sua rotação (no caso de motores) ou gerar corrente elétrica (no caso de geradores). Nosso motor, novamente, não será diferente.

Nosso rotor irá ser constituído de um ímã permanente que ficará livre para girar, dai o nome motor de passo de ímã permanente. Note que ímãs permanentes são relativamente caros e isso aumenta o custo do nosso motor. Mas como o rotor irá girar? Simples, com a ajuda do estator.

Nosso estator irá consistir em eletroímãs. Lembre-se que eletroímãs nada mais são que bobinas enroladas em volta de um núcleo de material ferromagnético (assim como existem materiais que são bons condutores de corrente elétrica, existem materiais que são melhores condutores de fluxo magnético: os chamados ferromagnéticos). A grande vantagem de eletroímãs sobre ímãs normais é o fato que os eletroímãs só se magnetizam (ou seja, produzem um campo magnético) quando corrente elétrica é aplicada neles. Em outras palavras, eletroímãs são ímãs que podem ser ligados e desligados em função da passagem de corrente elétrica.

Uma outra propriedade importantíssima de eletroímãs é que há duas maneiras de inverter a polaridade do campo magnético gerado por elas. Primeiro, podemos inverter o sentido da corrente que passa pela bobina. Segundo, podemos inverter o sentido no qual a bobina está enrolada. Nosso motor usará de ambas as técnicas em conjunto para manter seu movimento.

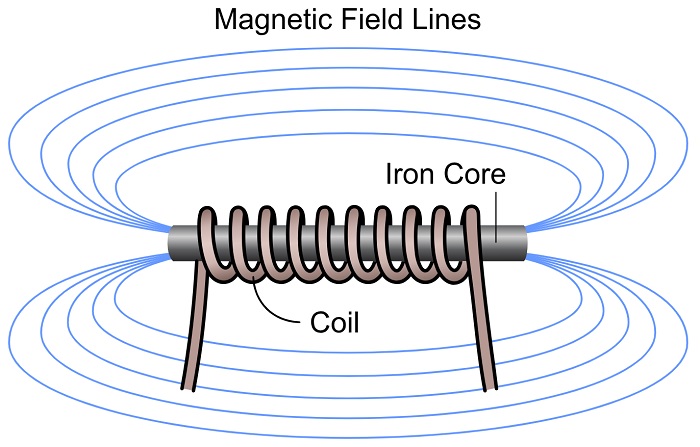
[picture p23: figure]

Figura 4: Bobina enrolada em uma barra ferromagnética, constituindo um eletroímã

Faremos então a seguinte montagem, como mostrado na figura 5a. Nela, temos no centro nosso rotor, com seus polos nortes e sul. Em volta do rotor temos o estator. Note que o estator é construído com 2 bobinas: a A-A’ e a B-B’, ambas enroladas no mesmo núcleo ferromagnético, que por sua vez é construído em formato circular com "dentes"para as bobinas. É essencial notar que as bobinas estão enroladas em sentidos opostos em dentes opostos. Ou seja, a parte A da primeira bobina está enrolada no sentido anti-horário, enquanto que a parte A’ está nos sentido horário. Assim, elas produzem campo magnético de polaridades oposta. Podemos também apenas construir as bobinas no mesmo jeito, e conectar a corrente de forma que ela percorra sentidos opostos, mas isso é mais difícil de visualizar.

Dizemos que um motor desse possui 2 polos, A e B.

Exercício

1. Identifique na figura 5a os seguintes elementos:
(a) O rotor;
(b) O estator;
(c) As duas bobinas.
2. Faça o mesmo para a figura 5b.

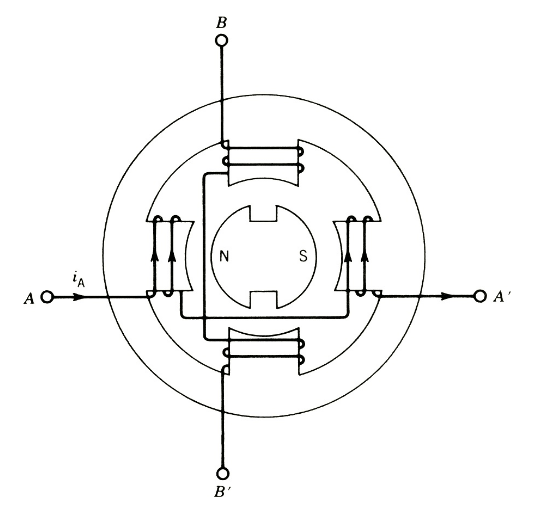
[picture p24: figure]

(a) Motor de Passo Elementar | (b) Esquema do motor de passo
Figura 5: Motor de Passo de Ímã Permanente e Motor de Passo Híbrido

Acompanhe os próximos parágrafos com a figura 6.

Vamos supor que a corrente ia está energizando a bobina AA’. Suponha que a parte da bobina em A gera um polo sul e a bobina em A’ gera um polo norte. Nessa condição, o rotor é atraído e se mantêm na mesma posição que na figura 5a.

Agora, suponha que a bobina AA’ seja desligada, e a bobina BB’ seja ligada. Suponha que a corrente ib gere em B um polo norte e em B’ um polo sul. O que acontece com o rotor nessa condição? O rotor irá se alinhar com o novo campo magnético gerado pela bobina BB’, ou seja, ele vai girar 90° no sentido anti-horário.

Note que agora devemos novamente energizar a bobina AA’ para que a máquina continue rodando, mas, dessa vez, com a polaridade oposta. Para isso, invertemos o sentido da correte que passa pela bobina. Agora, temos que a corrente −ia gera em A um polo norte e em A’ um polo sul, fazendo o motor girar mais 90°.

Fazemos a mesma inversão para a bobina B, e o motor gira mais 90°.

Agora, invertendo novamente a corrente em A, note que voltamos para condição inicial. Assim, concluímos uma rotação de nosso motor que girou em passos de 90°.


(a) Condição inicial | (b) Primeiro passo de 90
(c) Segundo passo de 90 | (d) Terceiro passo de 90

Figura 6: Motor de Passo Elementar Girando

Exercício

Como é possível inverter o sentido de rotação do motor? Como sabemos para que lado ele irá girar sem conhecer a ligação interna das bobinas?

### 5 Circuitos de DRIVE

Note que o acionamento das bobinas deve ser feito de forma ordenada para que se obtenha a rotação correta. Essa lógica é controlada por circuitos digitais, ou seja, circuitos que trabalham com sinais de baixa potência, na ordem de 20mA a 5V ou até 1mA. Assim, esses circuitos não são suficientes para alimentar diretamente nossos motores, que demandam um corrente muito maior, na ordem de 1 − 3A, ou até mais para motores maiores. Portanto, usamos um circuito, chamado de drive, para fazer a ponte entre nosso circuito lógico e nosso circuito de potência. Circuitos DRIVE portanto recebem sinais de baixa potência e tem a função de gerar os sinais em maior potência correspondentes para executar a tarefa desejada, no nosso caso, girar o motor.

Para o nosso motor de ímã permanente ou motores híbridos, devemos usar um driver bipolar, mas saiba que o driver unipolar também existe. É importante que o driver correto seja usado se você pretende girar o motor, o que eu espero que você pretenda.

### 5.1 Construção

A figura 7 mostra o esquema de uma fase do driver bipolar e sua ligação com uma bobina do motor (Phase winding). Note que o circuito não passa de uma ponte H, que tem seus transistores acionados de forma a controlar o sentido da corrente que passa pela bobina. Lembre-se que transistores operam como chaves acionadas eletricamente. Assim, quando desligados, funcionam como uma chave aberta e, quando ligados, como uma chave fechada.


Figura 7: Uma Fase de um Driver Bipolar

Quando os transistores T1 e T2 são ligados e os outros desligados, a corrente flui para uma direção na bobina do motor. Com T3 e T4 ligados e os outros desligados, temos que a corrente flui na direção oposta pela bobina. A figura 8 mostra isso.


(a) Primeira Situação | (b) Segunda Situação

Figura 8: Situações da ponte H do DRIVER

Como nosso motor tem duas fases (A e B), precisamos de dois desses circuitos para controla-lo. O driver que usaremos possui exatamente as duas pontes H que precisaremos. A figura 9 mostra o esquema final.


Figura 9: Esquema da ligação do driver

Resumo

Motores de passo giram uma quantidade de ângulos especifica em função de um pulso elétrico. A cada pulso que um motor de 1.8° recebe, ele gira 1.8°. Esses motores precisam de um circuito de drive para fazer seu acionamento, que faz a ponte entre a parte lógica e a parte de maior potência do circuito.

## ETAPA 2 - Montagem

### 6 Nossos componentes

Para escolher os componentes que usaremos, precisamos saber quais especificações de projeto queremos. As principais especificações de um motor de passo são: primeiro, o passo, segundo, a corrente das bobinas, terceiro, o torque.

Para o projeto, escolhemos o motor NEMA17. O NEMA17 não é um motor específico, mas sim um padrão de construção. Assim, existem inúmeros motores NEMA com diversas especificações, além de outros tipos de motores de passos mais simples. A maioria dos NEMA17 vem com um passo de 1.8° ou 0.9°. Usaremos um de 1.8°. Queremos um motor com um torque relativamente alto, para que se possa girar o cubo sem dificuldade. Assim, escolhemos um motor de 6.5 N.cm. Note que quanto maior o torque, maior o motor. Por consequência da escolha desses dois parâmetros, nosso motor tem corrente de 1.2A. Um motor desse custa por volta de 100 reais.


Figura 10: Vários motores NEMA

O driver escolhido é o A4988. Ele possui alguns confortos que facilitam sua ligação, como os resistores internos. Além disso, costuma ser barato (por volta de 10 reais). É o driver mais comum usado com um motor de nossas especificações.

Na figura 11, temos o nosso driver A4988. Segue a descrição de cada um dos pinos.


Figura 11: A4988

### 6.1 Descrição dos pinos do driver

- Pino DIR - Pino de Direção: Nível alto gira para um lado, nível baixo gira para o outro;
- Pino STEP - Pino de Passo: Cada subida de borda no pino gera um passo no motor;

– Pinos MS1, MS2, MS3 controlam o micro-step (não usados no full-step)

∗ São naturalmente baixos e, se não usados, não precisam ser conectados.

- Pino de SLEEP - Coloca o driver em repouso - ativo em baixo;
- Pino de RESET - Reseta o driver - ativo em baixo;

– Pino de SLEEP é normalmente alto. Pino de RESET é flutuante. Se as funções não são usadas, são conectados juntos, deixando ambos em alto.

- Pino de ENABLE - Ativa o driver - ativo em baixo;

– É naturalmente baixo e não precisa ser conectado.

Um esquema do circuito completo é mostrado na figura 12.


Figura 12: Circuito Completo

Exercício

Monte o circuito (os pinos de microstepping não são usados. Ignore o capacitor. Chame um monitor para conferir).

Exercício

1. Observe os circuitos da figuras 13. Qual deles não funciona? Por que?
2. Nossos motores não vem com conectores prontos, como podemos saber quais dois fios formam uma bobina?
3. Por fim, o A4988 tem um potenciômetro que pode ser usado para limitar a corrente que passa pelas bobinas. Se o limite de corrente estiver muito baixo, a bobina não é totalmente energizada. Sabendo disso, como podemos medir a corrente na bobina?


(a) Montagem 1 | (b) Montagem 2


(c) Montagem 3

Figura 13: Montagens

## ETAPA 3 - Código

Vamos finalmente escrever o código que fará nosso motor girar. De forma anti-climática, o código é bem simples. Sabemos que o motor gira 1.8° por pulso que enviamos a ele. Assim, para atingir uma rotação de 90 graus, precisamos simplesmente enviar 50 pulsos para o pino de STEP do driver.

Exercício

1. Copie o código abaixo. Substitua os valores dos pinos que você usou em sua montagem.
2. Analise o código. Ele funciona? Se não, que modificações devemos fazer para ele funcionar?
3. Faça as modificações necessárias e faça o motor rodar. (Chame um monitor antes de ligar a fonte!)
4. Mude a direção do motor.
1 | int DIR_PIN = 2; | // <-- SUBSTUA PELO SEU
2 | int STEP_PIN = 3; | // <-- SUBSTUA PELO SEU

void setup () {

pinMode ( STEP_PIN , OUTPUT ); pinMode ( DIR_PIN , OUTPUT ) ;

digitalWrite ( DIR_PIN , HIGH );

}

void loop () {

for ( int i = 0; i < 50; i ++) // gera 50 pulsos

{
digitalWrite ( STEP_PIN , HIGH ) ;
digitalWrite ( STEP_PIN , LOW );

}

}

### 7 Explicação dos comandos

1. pinMode(pino, modo): Define se o pino será usado como entrada (INPUT) ou saída (OUTPUT). Exemplo: pinMode(2, OUTPUT); configura o pino 2 como saída.
2. digitalWrite(pino, valor): Liga (HIGH) ou desliga (LOW) o pino configurado como saída. Exemplo: digitalWrite(2, HIGH); emite no pino 2 um sinal alto.
3. delay(Valor): Espera um valor de tempo em milissegundos. Exemplo: delay(1000) espera um segundo.

Considerações Finais

1. Motores CC possuem a característica de perder torque conforme sua velocidade aumenta. Assim, motores de passo também sofrem desse efeito. Aumentar a corrente pode negar isso até certo ponto.
2. O driver A4988 mantêm corrente nas bobinas do motor mesmo quando o motor está parado para manter o eixo preso. Isso leva a um aumento de temperatura do motor (até de 80°) e como estamos usando impressão 3D (material não resistente a altas temperaturas) devemos desligar o driver através do pino de Enable para evitar aquecimento excessivo.
3. Como eu sei se o torque do meu motor é suficiente para minha aplicação? Pergunte a um engenheiro mecânico.
4. Como eu sei se minha impressão 3D é forte o bastante? Pergunte a um engenheiro civil.
5. Caso você não conheça nenhum, superestime tudo.

## Referências

[1] SEN, P. C. Principles of Electric Machines and Power Electronics. 3rd ed. Hoboken, NJ: John Wiley & Sons, 2013.
[2] https://howtomechatronics.com/tutorials/arduino/stepper-motors-and-arduino-theultimate-guide/

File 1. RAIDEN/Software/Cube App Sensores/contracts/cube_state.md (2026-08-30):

# Contrato: Estado do Cubo (6×8 = 48) — entrada do solver

Pacote padronizado do estado do cubo. É o handoff sensoriamento -> solver
e o formato consumido pelo grupo `solver/` para a busca da solução.

## Dimensão

54 adesivos no cubo, 6 centros fixos -> 48 adesivos móveis -> matriz 6×8.

## Cor já classificada no FIRMWARE

O firmware executa RGB -> HSV -> distância mínima (Algoritmo 1) e devolve a
cor JÁ classificada. O pacote carrega 48 chars de cor, não RGB cru.

Alfabeto de cor (Tab. C.2):

|Char|Cor|
|-|-|
|W|Branca|
|G|Verde|
|R|Vermelha|
|O|Laranja|
|Y|Amarela|
|B|Azul|

## Ordem das faces (linhas 0..5)

&#x20;   U(branca)  R  F(verde)  D  L  B      ==  U R F D L B

Convenção física do robô: face branca sempre para cima, face verde sempre
à frente (motor designado como frente).

## Ordem de leitura dentro de cada face

Sentido horário, começando pela peça superior esquerda, 8 posições
(pula o centro).

## Indexação

&#x20;   índice do adesivo = face \* 8 + posição      (0..47)
    face ∈ {0..5} na ordem URFDLB acima
    posição ∈ {0..7} na ordem horária acima

## Centros

Implícitos/fixos por convenção (não são sensoriados). O adapter do
`solver/` reconstrói os 54 facelets inserindo os 6 centros conhecidos e
reordenando cada face para o formato exigido pela biblioteca de solução.

`firmware/src/protocol/cube\_state.h` espelha este schema.

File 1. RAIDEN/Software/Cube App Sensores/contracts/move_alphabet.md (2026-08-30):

# Contrato: Alfabeto de Movimentos (A–R)

Fonte única de verdade da notação de movimentos (Tabela 1 do artigo).
O byte enviado na serial é o caractere ASCII 'A'..'R' — 1 byte por
movimento, para máxima velocidade de comunicação.

## Onde a tradução acontece (toda no HOST)
    solver resolve -> notação de cubo (U, U', U2, ...)
      -> host/solver/base.py traduz para o char 'A'..'R' (to_robot_sequence)
      -> firmware recebe SÓ o char e o mapeia na LUT (índice 0..17)

MOVE_TABLE em host/solver/base.py é o espelho desta tabela no host.
(embedded.py NÃO traduz — apenas valida que os chars estão em A..R.)

O firmware nunca vê a notação de cubo mágico, apenas a letra.
`firmware/src/protocol/protocol.h` espelha esta tabela.

## Tabela canônica

|Notação|Descrição|Ângulo|Char|Índice LUT|
|-|-|-|-|-|
|U|Superior Horário|90°|A|0|
|U'|Superior Anti-horário|-90°|B|1|
|U2|Superior Duplo|180°|C|2|
|D|Inferior Horário|90°|D|3|
|D'|Inferior Anti-horário|-90°|E|4|
|D2|Inferior Duplo|180°|F|5|
|L|Esquerda Horário|90°|G|6|
|L'|Esquerda Anti-horário|-90°|H|7|
|L2|Esquerda Duplo|180°|I|8|
|R|Direita Horário|90°|J|9|
|R'|Direita Anti-horário|-90°|K|10|
|R2|Direita Duplo|180°|L|11|
|F|Frontal Horário|90°|M|12|
|F'|Frontal Anti-horário|-90°|N|13|
|F2|Frontal Duplo|180°|O|14|
|B|Traseira Horário|90°|P|15|
|B'|Traseira Anti-horário|-90°|Q|16|
|B2|Traseira Duplo|180°|R|17|

Índice LUT = (char - 'A'), de 0 a 17.

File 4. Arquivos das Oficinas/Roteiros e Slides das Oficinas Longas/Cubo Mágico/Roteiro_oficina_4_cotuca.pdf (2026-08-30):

## Roteiro da Oficina 4: Algoritmos para Resolução do Cubo Mágico

## Etapa 1 - Leitura do cubo mágico

### 1. Estrutura do Cubo

O cubo mágico é um quebra-cabeça composto por 27 peças e 54 adesivos. Podemos classificar essas peças em três tipos, são elas:

- centros (centers)
- meios (edges)
- quinas (corners)

Na Figura 1 podemos observar melhor a localização de cada uma delas.


Figura 1: Tipos de Peças do Cubo

Observando o cubo, podemos ver que ele tem 6 centros, 12 meios e 8 quinas, além de uma peça interna a qual chamamos de núcleo. Sabendo disso, podemos começar a pensar como é possível através dos sensores, estudados na oficina anterior, realizar um mapeamento de todos os adesivos do cubo.

Exercício

Se temos um sensor que lê uma cor, qual é a solução de engenharia mais inteligente e barata para escanear todo o cubo mágico?

### 2. Sensoriamento

Após descobrir qual será a disposição dos sensores, inicia-se para o processo de sensoriamento. Esse processo irá funcionar como se fosse o olho do robô e irá nos gerar uma matriz das cores de cada um dos adesivos e suas respectivas posições. Primeiramente, é definida uma letra para representar cada uma das cores lidas pelo sensor conforme mostra a Figura 2. E uma ordem de leitura que será realizada pelos nossos sensores, como é visto na Figura 3


Figura 2: Letras associadas a cada cor


Figura 3: Ordem do sensoriamento

O sensoriamento realizado seguindo a ordem da figura acima, irá gerar 6 matrizes, uma para cada face, com 8 letras representando as cores contidas em cada um dos adesivos contidos naquela face.

EX: Na camada de cima (branca) teremos a matriz (string) [B,O,R,W,W,O,Y,G]

Note: Uma boa estratégia para verificar se a coleta das cores ocorreu corretamente, é verificar se cada uma das cores apareceu 8 vezes.

Exercício

Embaralhe o cubo aleatoriamente. Utilizando a notação de cores (W, R, G, Y, O, B) e o protocolo de ordem que definimos, escreva a string completa que representa o estado atual de todas as 48 peças .

### 3. Comunicação Serial

Tendo em mãos a string completa do estado do cubo, o arduíno precisa então enviar a leitura obtida para o computador. Como é possível enviar apenas valores lógicos de 0 (baixo) ou 1 (alto), temos que encontrar um jeito de codificar nossa string em uma sequência enviável. Para isso, temos o padrão ASCII. O padrão relaciona um carácter a um número. Assim, quando o computador lê o número, ele faz a conversão para o respectivo carácter. Por exemplo, temos para a letra W o valor 87. Convertendo 87 para binário, temos 0101 0111. Que é uma sequência enviável e pode ser transferida do arduino para o computador. A figura 4 mostra a codificação do ASCII e a figura 5 mostra as sequências relevantes para a codificação do cubo.


Figura 4: Tabela de representação ASCII


Figura 5: Letras traduzidas seguindo a tabela ASCII

Mas agora temos outro problema, como enviar a sequência? Uma maneira de realizar isso, é a chamada comunicação serial. Como o nome diz, ela envolve enviar serialmente, ou seja, um por um, uma sequência de bits para o computador. Cada bit é recebido individualmente, salvo, e então próximo é recebido. Isso pode ser observado com mais clareza na Figura 6. Nela temos que a sequência 1100110 é enviada bit por bit a cada subida do sinal de clock.


Figura 6: Comunicação serial

Exercício

Converta o início da string de 48 caracteres que representa o estado do cubo para a sua representação binária (em bytes), conforme o protocolo de codificação serial (ASCII/UTF-8). Mostre a sequência de 0s e 1s que o Python leria.

### 4. Resumo da Etapa

A etapa de leitura pode ser bem resumida através da parte do arduíno da Figura 7. Nela podemos ver o a sequência de processos realizados para coletarmos toda a informação necessária para enfim adentrar na parte da solução do cubo mágico, que será proposta na linguagem Python.


Figura 7: Resumo do processo de obtenção das cores e transmissão dos dados para manipulação em Python

## Etapa 2: Métodos de Solução do Cubo Mágico

O cubo mágico (ou cubo de Rubik) foi inventado pelo professor de arquitetura húngaro Ernõ Rubik. Ele o construiu para utiliza-lo como uma ferramenta interessante e diferente de ensino para auxiliar seus alunos a compreenderem relações espaciais e movimentos tridimensionais. A seguir iremos dissertar um pouco sobre alguns dos diversos métodos existentes para se resolver o rubik’s cube.

### 1. Método de Camadas

No primeiro contato com a resolução do cubo mágico, é comum optar pelo método de camadas devido à sua simplicidade e abordagem intuitiva. Na Figura 8, estão ilustrados os principais passos dessa técnica. A estratégia consiste em resolver o cubo camada por camada, iniciando pela inferior e avançando progressivamente até a superior.


Figura 8: Método de camadas

### 2. Método Kociemba

O método de Kociemba, associado ao conceito do “Número de Deus”, é altamente otimizado para minimizar a quantidade de movimentos necessários para resolver o cubo mágico. Trata-se do método mais complexo abordado neste roteiro, e por isso não será explorado em profundidade.

Seu algoritmo inicia com uma série de movimentos que têm como objetivo transformar o estado inicial do cubo em uma configuração intermediária simplificada. A partir dessa configuração, a resolução é concluída utilizando um conjunto restrito de movimentos.

Esse método é capaz de gerar soluções com, no máximo, 20 movimentos, valor que representa o Número de Deus. Apesar de oferecer extrema eficiência na resolução, o algoritmo de Kociemba é tecnicamente sofisticado e de difícil compreensão, o que torna sua implementação e estudo mais desafiadores

### 3. Método Vendado M2/OP

Este é o método usado para resolver “vendado”, e é o método que vamos usar no robô. A grande vantagem é que não precisamos atualizar o estado do cubo durante a solução: lê-se o cubo uma vez e pronto.

O nome vem das duas partes: M2 resolve os meios, e OP resolve as quinas. A ideia geral é simples: definimos um buffer e um target. Fazemos um setup para levar a peça alvo até o target, aplicamos o algoritmo (M2 ou OP), e desfazemos o setup. Repetindo isso, vamos colocando cada peça no seu lugar.

Essa lógica de troca de peças será melhor explicado em comutadores.

### 4. Notação oficial dos Cubos Mágicos

Para facilitar a comunicação e compreensão dos cubistas, foi desenvolvida uma notação muito intuitiva dos movimentos possíveis em um cubo mágico. Vamos listar um a um os movimentos possiveis:

F (frente), R (direita), L (esquerda), B (trás), U (cima), D (baixo) e M (meio vertical).

Sem apóstrofo é horário. Com apóstrofo (ex: R’) é anti-horário. Com “2” (ex: U2) é o mesmo movimento duas vezes. A Figura 9 ilustra esses movimentos.


Figura 9: Possíveis movimentos no cubo

Exercício

Com o cubo mágico resolvido tente executar a seguinte sequencia de movimentos: R U R’ F’ R U R’ U’ R’ F R2 U’ R’ U’

### 5. Lógica de comutadores

Comutadores são a base do método vendado. Eles permitem trocar peças específicas sem bagunçar o resto do cubo. No M2/OP usamos semi-comutadores o tempo todo.

Matematicamente, um comutador é escrito como [A B A’ B’], onde A e B são sequências de movimentos, e A’ e B’ são seus inversos.

Exemplo:

A = U

′

B = R

′D

′R

A

′ = U

B

′ = R

′DR

Logo, o comutador completo é: [U’ R’ D’ R U R’ D R].

Exercício

Embaralhe o cubo com a seguinte sequência:
(F2 D’ L2 D’ L2 D2 F2 U’ R2 U2 L’ U R2 U’ L U’) Tente achar um comutador que resolva esse caso. Dica: Use o exemplo anterior.

Resolvemos o cubo com uma sequência de comutadores, como pode ser visto na Figura 10.


Figura 10: Lógica de comutadores

### 6. História

Com toda essa informação sobre o cubo, podemos começar a trabalhar com a história para resolver o cubo. A história, no método vendado, é nada mais nada menos do que uma sequência de letras que nos permite formar palavras e gerar uma história para facilitar uma memorização da sequência de movimentos que deverá ser seguida. Para isso mapeamos todos os meios e quinas do cubo com diferentes letras, para indicar qual peça deverá ser comutada na sequência. Na Figura 11 temos uma organização padrão entre os cubistas e um exemplo.


Figura 11: Mapeamento do cubo em letras

Utilizaremos a história em nosso algoritmo desenvolvido em Python para guiar a resolução do cubo nele, seguindo exatamente a mesma lógica seguida pelos cubistas do método vendado. Dessa forma, o código irá ir comutando sequencialmente as peças até chegar em uma sequência de movimentos que irá resolver o cubo.

## Etapa 3: Comunicação com os motores

Após a obtenção dos movimentos necessários para solução do cubo, temos a missão de transferir a mensagem para os motores. Essa etapa funcionará como um cérebro se comunicando com os braços de uma pessoa para realizar uma ação.

Assim como na comunicação dos sensores, iremos utilizar a tabela ASCII vista na 4. Esse processo final pode ser identificado na Figura 12.


Figura 12: Transmissão da solução em Python para os motores

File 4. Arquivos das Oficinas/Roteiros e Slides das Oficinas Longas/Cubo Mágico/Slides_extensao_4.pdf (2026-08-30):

# Projeto de Extensão

Aula 4: O Cérebro do Robô - Do Caos à Solução

# Cronograma

Todas as aulas serão das 13:30h às 17:30h Aula 1: Apresentação e Introdução a Sensores

27/09 (sábado) e 01/10 (quarta)

Aula 2: Programação na linguagem C/C++ 11/10 (sábado) e 22/10 (quarta)

Aula 3: Montagem de um sensor de baixo custo 25/10 (sábado) e 29/10 (quarta)

Aula 4: Algoritmos,
comutadores e lógica do código 08/11 (sábado) e 19/11 (quarta)

Aula 5: Motores e drivers
29/11 (sábado)

Aula 6: Visita a Feec
06/12 (sábado) e 03/12 (quarta)

# Resumo da Aula


Introdução ao Cubo Mágico;
Engenharia dos Sensores
Protocolo de Input (Olhos → Cérebro);
Métodos de Solução do Cubo Mágico;
Lógica de Comutadores
Teste do código do algoritmo em Python ;
Protocolo de Output (Cérebro → Braços)

# Rubik’

# s Cube (Magic Cube)


Professor de arquitetura húngaro, criou o cubo mágico em 1974.

# Ernõ Rubik

# Arquitetura do cubo


CORE
Ao todo temos 6 faces com 9 adesivos cada, totalizando 54 adesivos Temos 6 centros, 8 pontas e 12 meios

# Engenharia do Sensor


Na Aula 3, construímos o sensor de cor (os "olhos"). Se temos um sensor que lê uma cor, qual é a solução de engenharia mais inteligente e barata para escanear todo o cubo mágico?

# Exercício

# Solução

# Solução


# Solução


# O Protocolo de Input (Olhos → Cérebro)


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

### WRGYOB

## Up: [B,W,R,Y,W,G,R,R]


1 2 3
4
7 6 5

8

11 12 13
14
9 16 15

10

17 18 19
20
23 22 21

24

25 26 27
28
31 30 29

32

45 46 47
48
43 42 41

44

39 40 33
34
37 36 35

38

## Right: [G,B,Y,Y,G,R,Y,W ] Front: [W,W,O,O,G,W,O,G ] Down: [B,R,O,B,Y,G,G,Y ]

## Left: [O,G,B,O,W,R,R,O] Back: [B,B,Y,B,W,Y,R,O]

# Exercício

Embaralhe o cubo aleatoriamente.
Utilizando a notação de cores (W, R, G, Y, O, B) e o protocolo de ordem que definimos, escreva a string completa que representa o estado atual de todas as 48 peças .

# Comunicação Serial


# ASCII/UTF-8 Comunicação por Bytes

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
# Exercício

Converta o início da string de 48 caracteres que representa o estado do cubo para a sua representação binária (em bytes), conforme o protocolo de codificação serial (ASCII/UTF-8). Mostre a sequência de 0s e 1s que o Python leria.

# Resumo

Arduíno; Python; Calcula a Solução; Baud Rate Start Bit Stop Bit Clock; Serial

# Métodos de Solução do Cubo Mágico

Camadas | CFOP | Roux
ZZ | Petrus
3-Style | Heise | OP/OP
M2/OP | ZBLL
Keyhole | DR | Orozco

# Eka

# Método Básico de Camadas


# Método Vendado M2/OP


# Método Kociemba "Número de Deus"


{U, D, R2, L2, F2, B}

Domino’s Reduction

Fase 1 (Max. 12 movimentos): Levar o cubo para um subconjunto de estados mais simples (o "Domino's Reduction")

Fase 2 (Max. 18 movimentos): Resolver o cubo a partir desse estado simplificado.

O máximo de movimentos garantidos por este método para resolver qualquer estado é 30 movimentos.

Herbert Kociemba, matemático alemão, desenvolveu seu método nos anos 1990.

O método de Kociemba permitiu uma generalização: precisaram resolver apenas um subconjunto específico e representativo de todos os embaralhamentos.

Em 2010, usando o poder de processamento da Google (milhares de horas de CPU), eles testaram por exaustão todos os casos necessários.

Conclusão Final: O número máximo de movimentos mínimos necessários para resolver qualquer estado do Cubo Mágico é 20.

O Cubo Mágico tem aproximadamente 43 quintilhões de embaralhamentos o que torna impossível testar todas as soluçõs.

O nosso robô irá utilizar o princípio dos Comutadores (método vendado) para resolver o Cubo Mágico. Porque?

# Qual método nosso robô irá usar?

# Notação Oficial dos movimentos do Cubo Mágico


# Exercício

Com o cubo mágico resolvido tente executar a seguinte sequencia de movimentos:

R U R’ F’ R U R’ U’ R’ F R2 U’ R’ U’

# Lógica de Comutadores

# Ideia Matemática

## [A B A’ B’]

Com A e B uma sequencia de movimentos, onde A’ é o inverso de A e B’ é o inverso de B

# Exemplo

Estado Inicial

Sala 1; Sala 2

Objetivo:

Comutar as cadeiras Vermelho, Verde, Branco sem mudar as cadeiras Azul e Amarelo

# Exemplo

A: rotaciona as cadeiras da sala 1 no sentido horário

# Exemplo

B: troca a cadeira da sala 2 com a cadeira do canto da sala 1

# Exemplo

A’: rotaciona as cadeiras da sala 1 no sentido anti-horário

# Exemplo

B’: destroca a cadeira da sala 2 com a cadeira do canto da sala 1

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
# o Inicial Estado Final

# Comutadores na prática

A: U’
B: R' D' R
A’: U
B’: R' D R
Comutador: [U’ R’ D’ R U R’ D R]

# Exercício (Desafio)

Embaralhe o cubo com a seguinte sequencia de movimentos:

Tente achar um comutador que resolva esse caso

F2 D’ L2 D’ L2 D2 F2 U’ R2 U2 L’ U R2 U’ L U’


Estado inicial | 1º Comutador

2º Comutador

Sequência de solução: Vermelho; Azul; Amarelo; Verde

Buffer | Buffer

Buffer

# Como conseguir essa sequência?


[T, E, H, Q, B, L, J, B, G, S, G, O, V]

História dos Meios:

[W, P, X, G, B, F, I]

História das Pontas:

# Código em Python

Podemos testar se a nossa solução realmente funciona atraves do site:

# Vamos testar nosso código?


# Protocolo de Saída (Cérebro → Braços)


# ASCII/UTF-8 Comunicação por Bytes

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
# Resumo

Arduíno; Python; Calcula a Solução; Baud Rate Start Bit Stop Bit Clock; Serial

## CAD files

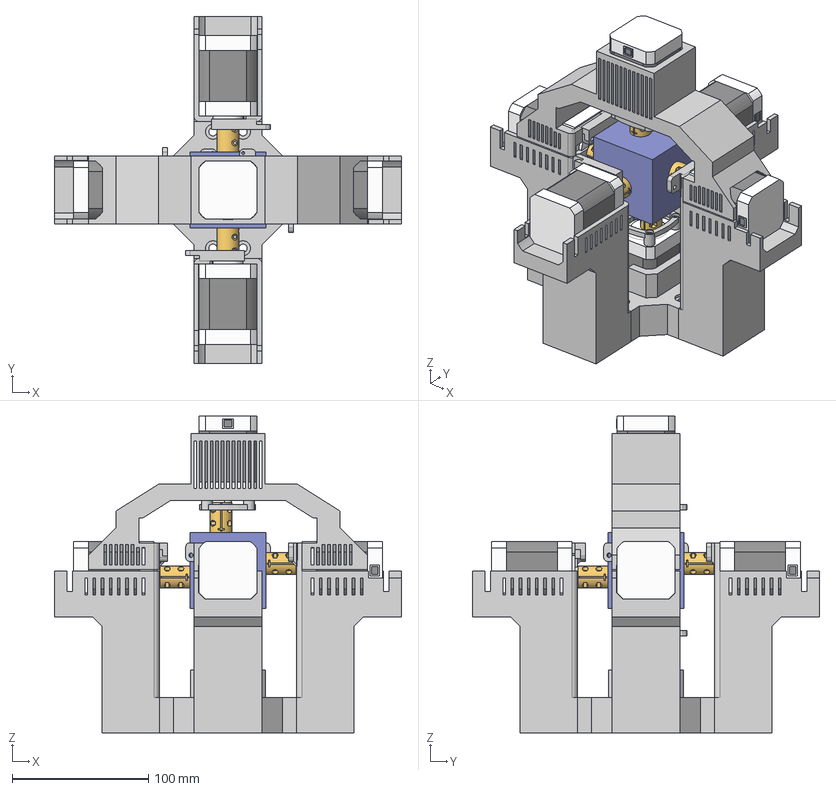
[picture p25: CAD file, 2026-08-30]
1. RAIDEN/3D Files/Esquema_Final.step
254.4 x 254.4 x 232.2 mm

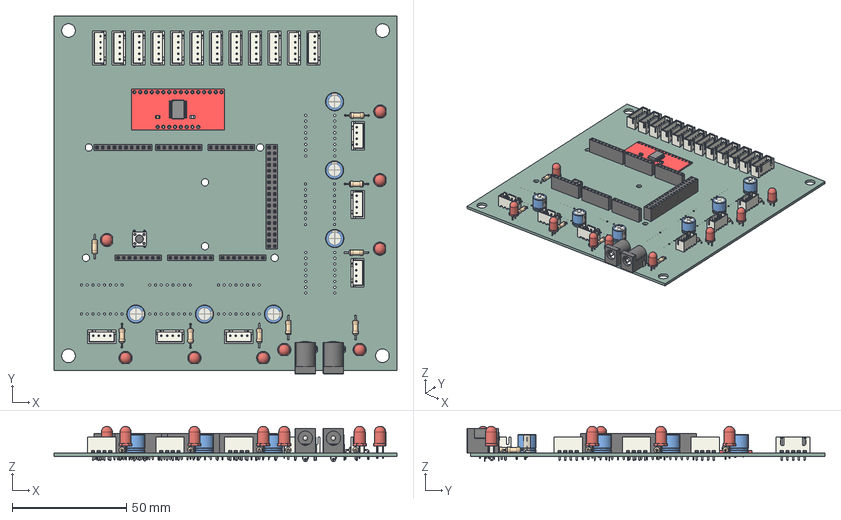
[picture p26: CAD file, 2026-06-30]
1. RAIDEN/PCB/PCB Drivers + Sensores/PCB Drivers + Sensores/PCB Drivers + Sensores.step
150.0 x 156.6 x 15.5 mm
PinSocket_2x18_P2.54mm_Vertical
PinSocket_1x08_P2.54mm_Vertical x 5
PinSocket_1x10_P2.54mm_Vertical
JST_XH_B5B-XH-A_1x05_P2.50mm_Vertical x 12
R_Axial_DIN0207_L6.3mm_D2.5mm_P10.16mm_Horizontal x 9
JST_XH_B4B-XH-A_1x04_P2.50mm_Vertical x 6
CP_Radial_D8.0mm_P3.50mm x 6
BOB-09056
BarrelJack_Horizontal x 2
LED_D5.0mm x 9
SW_PUSH_6mm
PCB Drivers + Sensores_PCB

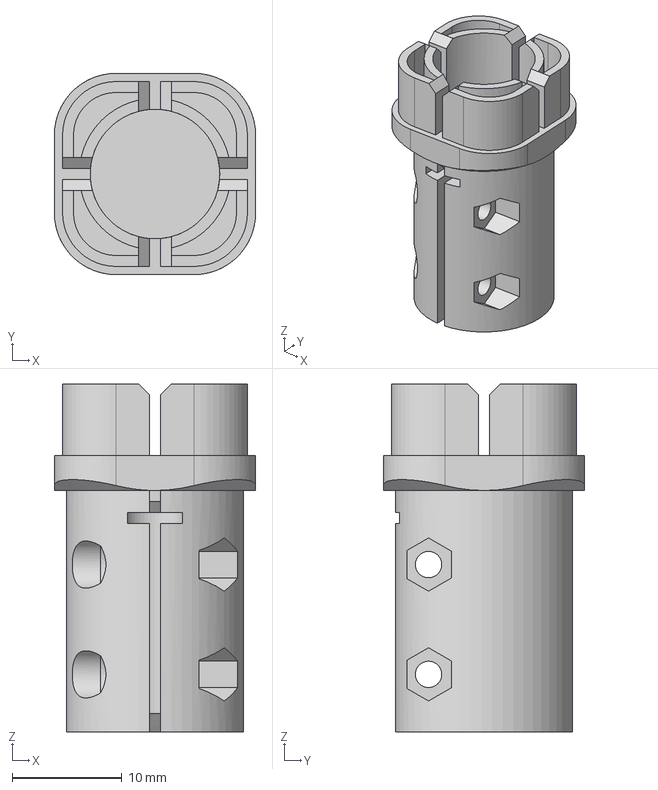
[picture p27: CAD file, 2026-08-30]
1. RAIDEN/3D Files/Cap_garra_v3.step
18.3 x 18.3 x 31.7 mm

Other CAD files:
1. RAIDEN/3D Files/Cap_garra_v3.f3d
1. RAIDEN/3D Files/Cap_garra_v3.stl
1. RAIDEN/3D Files/Gabarito_Final.f3d

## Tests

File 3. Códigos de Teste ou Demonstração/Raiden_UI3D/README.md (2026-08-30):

# Raiden — Robô Solucionador de Cubo Mágico

Projeto de extensão (FEEC/UNICAMP) que integra sensoriamento, cálculo da
solução e movimentação num robô solucionador de cubo mágico.

## Organização
- `software/`  — todo o código (host em Python + firmware em C++).
- `hardware/`  — datasheets e material de eletrônica (motores, sensores).
- `structure/` — modelos 3D (CAD) da estrutura do robô.
- `classroom/` — material das oficinas de extensão.
- `dependencies/` — bibliotecas, executáveis e repositórios externos.

## software/
Duas linguagens, duas fronteiras claras, ligadas por 3 contratos versionados:
- `contracts/` — fonte única de verdade (alfabeto de movimentos, protocolo
  serial, schema do estado do cubo).
- `host/`      — Python: orquestra, configura, seleciona e **calcula a solução**.
- `firmware/`  — C++: um único binário do Arduino que **processa** (sensores
  e motores).

## Interface gráfica (host)

O host tem duas peles sobre o MESMO sistema (mesma classe `Raiden`, mesmos
flows de `sensor/`, `solver/` e `execution/`):

```
cd software/host
python raiden.py                 # GUI 3D (padrão)
python raiden.py --mode demo     # GUI sem hardware (serial simulada)
python raiden.py --port COM5     # força a porta
python raiden.py --terminal      # menu de terminal (o de sempre)
```

A GUI mostra o cubo 3D sendo **sensoriado** (os 48 adesivos acendem face a
face, na ordem de contrato) e depois sendo **resolvido** (replay dos giros
enquanto o robô executa), com contador de movimentos, cronômetro e mapa dos
12 sensores. A aba lateral repete os MESMOS números do menu de terminal.

O cronômetro (TEMPO) mede o ciclo do cubo: começa no `r0*` (sensoriamento)
e para quando a worker terminou E o cubo 3D acabou de mostrar o resultado —
o que durar mais. Conectar, escanear, calibrar ou mudar velocidade não
entram na conta. A linha menor (`motores`) é o `d_<seg>*` puro do firmware,
para separar mecânica de leitura/cálculo.

| Tecla | Ação |
|-|-|
|1|Preparar (scan + calibração)|
|2|Resolver + Executar (sense › solve › exec)|
|3 4 5 6|Scan · Calibrar · Sensoriar · Resolver|
|7|Executar sequência (chars A–R; vem preenchida com a última solução)|
|8|Alterna o método do solver|
|9 (ou S)|Painel de configuração: modo, porta, método, velocidade, pausa|
|R L U D F B|Gira a face no cubo virtual e envia o movimento ao robô|
|Shift + giro|Anti-horário · **Ctrl + giro**: 180°|
|C|Reposiciona o cubo virtual (resolvido) — só visual|
|0 ou ESC|Sair|

No painel de configuração: `↑↓` troca de campo, `←→` alterna as opções,
dígitos/letras editam. **Método, velocidade e pausa são aplicados sozinhos**
ao sair do campo ou fechar o painel — `ENTER` só antecipa. Modo e porta
reabrem o link, então exigem `ENTER` explícito e voltam ao valor real no `ESC`.

Velocidade (`v_<us>*`) é o `delayMicroseconds` de cada nível do pulso STEP:
o período de um passo é 2×esse valor. Pausa (`g_<ms>*`) é o `delay` após
cada movimento (ou após cada par de faces opostas acionado junto). Ao
conectar, a GUI envia os dois valores do painel para a placa, que reseta ao
abrir a porta e voltaria aos próprios defaults.

### Dependências do host
`pip install -r software/host/requirements.txt`
(pyserial, kociemba para o solver, e pygame + PyOpenGL para a GUI 3D).

### Nota de contrato (2026)
`host/solver/base.py` estava mapeando os movimentos na ordem URFDLB
(`R`→`D`, `F`→`G`, `D`→`J`, `L`→`M`), divergindo de
`contracts/move_alphabet.md` e da LUT de `firmware/src/motion/motion.cpp`,
que usam a ordem U,D,L,R,F,B. Na prática o host pedia "R" e o robô girava
"D". `MOVE_TABLE` foi alinhada ao contrato (fonte única) — `U` e `B` já
estavam certos; `R`↔`D` e `F`↔`L` foram desfeitos.

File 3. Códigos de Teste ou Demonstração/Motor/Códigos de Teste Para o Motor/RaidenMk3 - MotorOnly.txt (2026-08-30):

#ifndef MOTOR_H
#define MOTOR_H

// ================================
//        DEFINIÇÃO DOS PINOS
// ================================

// Pinos de Direção e Passo
#define DIR_PIN_1 31
#define STEP_PIN_1 30
#define DIR_PIN_2 35
#define STEP_PIN_2 34
#define DIR_PIN_3 A12
#define STEP_PIN_3 A13
#define DIR_PIN_4 A6
#define STEP_PIN_4 A7
#define DIR_PIN_5 A0
#define STEP_PIN_5 A1
#define DIR_PIN_6 43
#define STEP_PIN_6 42

// Pinos de Enable Individuais
#define ENABLE_PIN_1 14
#define ENABLE_PIN_2 16
#define ENABLE_PIN_3 49
#define ENABLE_PIN_4 48
#define ENABLE_PIN_5 A3
#define ENABLE_PIN_6 19

// ================================
//       VARIÁVEIS GLOBAIS
// ================================

// Sequência de movimentos (String única)
/*String sequencia = 
"GPHALEMCQIKBNFRDJHOAREJGNCPDLIMBQFKHOGRALDNCPEKIMBQFJHOAPELGMCRDKHNBQFJIOGPAKENCRDLIMBOFJHQAPD"
"LGNCREKIMBQFJHOARELGNCPDKIMBQFJHOARDLGNCPEKIMBQFJHOGPALDNCREKIMBQFJHOAPELGMCRDKINBQFJHOGRALENC"
"PDKIMBQFJHOARDLGNCPEKIMBQFJHOAPELGNCRDKIMBQFJHOGPALENCRDKIMBQFJHOARELGNCPDKIMBQHJFOGRALDNCPEKI"
"MGPHALEMCQIKBNFRDJHOAREJGNCPDLIMBQFKHOGRALDNCPEKIMBQFJHOAPELGMCRDKHNBQFJIOGPAKENCRDLIMBOFJHQAP"
"DLGNCREKIMBQFJHOARELGNCPDKIMBQHJFOGPALENCRDKIMBQFJHOARDLGNCPEKIMBQFJHOGPALDNCREKIMBQFJHOAPELGM"
"CRDKINBQFJHOGRALENCPDKIMBQFJHOARDLGNCPEKIMBQFJHOAPELGNCRDKIMBQFJHOGPALENCRDKIMBQFJHOARELGNCPDK"
"IMBQHJFOGRALDNCPEKIMGPHALEMCQIKBNFRDJHOAREJGNCPDLIMBQFKHOGRALDNCPEKIMBQFJHOAPELGMCRDKHNBQFJIOG"
"PAKENCRDLIMBOFJHQAPDLGNCREKIMBQFJHOARELGNCPDKIMBQHJFOGPALENCRDKIMBQFJHOARDLGNCPEKIMBQFJHOGPALD"
"NCREKIMBQFJHOAPELGMCRDKINBQFJHOGRALENCPDKIMBQFJHOARDLGNCPEKIMBQFJHOAPELGNCRDKIMBQFJHOGPALENCRD"
"KIMBQFJHOARELGNCPDKIMBQHJFOGRALDNCPEKIMGPHALEMCQIKBNFRDJHOAREJGNCPDLIMBQFKHOGRALDNCPEKIMBQFJHO"
"APELGMCRDKHNBQFJIOGPAKENCRDLIMBOFJHQAPDLGNCREKIMBQFJHOARELGNCPDKIMBQHJFOGPALENCRDKIMBQFJHOARDL"
"GNCPEKIMBQFJHOGPALDNCREKIMBQFJHOAPELGMCRDKINBQFJHOGRALENCPDKIMBQFJHOARDLGNCPEKIMBQFJHOAPELGNCR"
"DKIMBQFJHOGPALENCRDKIMBQFJHOARELGNCPDKIMBQHJFOGRALDNCPEKIM"
;
*/

String sequencia = "LIADJOPAMBIRKOCIFCI";

int indice = 0;
bool start = false;
unsigned long tempoInicio = 0;
unsigned long tempoTotalPausado = 0;

// Configuração de velocidade
const int DELAY_STEP = 850; // Microsegundos entre passos

// ================================
//     HELPER: CONFIGURA MOTOR
// ================================
// Esta função preenche as variáveis por referência para evitar repetição de código
bool configurarMotor(char motor, int &dirPin, int &stepPin, int &enablePin, int &dir, int &passos) {
    
    // --- MOTOR 1 (A, B, C) - UP ---
    if (motor == 'A')      { dirPin = DIR_PIN_1; stepPin = STEP_PIN_1; enablePin = ENABLE_PIN_1; dir = LOW;  passos = 50; }
    else if (motor == 'B') { dirPin = DIR_PIN_1; stepPin = STEP_PIN_1; enablePin = ENABLE_PIN_1; dir = HIGH; passos = 50; }
    else if (motor == 'C') { dirPin = DIR_PIN_1; stepPin = STEP_PIN_1; enablePin = ENABLE_PIN_1; dir = LOW;  passos = 100; }
    
    // --- MOTOR 2 (D, E, F) - RIGHT ---
    else if (motor == 'D') { dirPin = DIR_PIN_2; stepPin = STEP_PIN_2; enablePin = ENABLE_PIN_2; dir = LOW;  passos = 50; }
    else if (motor == 'E') { dirPin = DIR_PIN_2; stepPin = STEP_PIN_2; enablePin = ENABLE_PIN_2; dir = HIGH; passos = 50; }
    else if (motor == 'F') { dirPin = DIR_PIN_2; stepPin = STEP_PIN_2; enablePin = ENABLE_PIN_2; dir = LOW;  passos = 100; }
    
    // --- MOTOR 3 (G, H, I) - FRONT ---
    else if (motor == 'G') { dirPin = DIR_PIN_3; stepPin = STEP_PIN_3; enablePin = ENABLE_PIN_3; dir = LOW;  passos = 50; }
    else if (motor == 'H') { dirPin = DIR_PIN_3; stepPin = STEP_PIN_3; enablePin = ENABLE_PIN_3; dir = HIGH; passos = 50; }
    else if (motor == 'I') { dirPin = DIR_PIN_3; stepPin = STEP_PIN_3; enablePin = ENABLE_PIN_3; dir = LOW;  passos = 100; }
    
    // --- MOTOR 4 (J, K, L) - DOWN ---
    else if (motor == 'J') { dirPin = DIR_PIN_4; stepPin = STEP_PIN_4; enablePin = ENABLE_PIN_4; dir = LOW;  passos = 50; }
    else if (motor == 'K') { dirPin = DIR_PIN_4; stepPin = STEP_PIN_4; enablePin = ENABLE_PIN_4; dir = HIGH; passos = 50; }
    else if (motor == 'L') { dirPin = DIR_PIN_4; stepPin = STEP_PIN_4; enablePin = ENABLE_PIN_4; dir = LOW;  passos = 100; }
    
    // --- MOTOR 5 (M, N, O) - LEFT ---
    else if (motor == 'M') { dirPin = DIR_PIN_5; stepPin = STEP_PIN_5; enablePin = ENABLE_PIN_5; dir = LOW;  passos = 50; }
    else if (motor == 'N') { dirPin = DIR_PIN_5; stepPin = STEP_PIN_5; enablePin = ENABLE_PIN_5; dir = HIGH; passos = 50; }
    else if (motor == 'O') { dirPin = DIR_PIN_5; stepPin = STEP_PIN_5; enablePin = ENABLE_PIN_5; dir = LOW;  passos = 100; }
    
    // --- MOTOR 6 (P, Q, R) - BACK ---
    else if (motor == 'P') { dirPin = DIR_PIN_6; stepPin = STEP_PIN_6; enablePin = ENABLE_PIN_6; dir = LOW;  passos = 50; }
    else if (motor == 'Q') { dirPin = DIR_PIN_6; stepPin = STEP_PIN_6; enablePin = ENABLE_PIN_6; dir = HIGH; passos = 50; }
    else if (motor == 'R') { dirPin = DIR_PIN_6; stepPin = STEP_PIN_6; enablePin = ENABLE_PIN_6; dir = LOW;  passos = 100; }
    
    else { return false; } // Comando inválido

    return true;
}

// ================================
//      VERIFICAR OPOSTOS
// ================================
bool saoOpostos(char face1, char face2) {
    // Define os grupos de faces
    bool f1_is_U = (face1 == 'A' || face1 == 'B' || face1 == 'C');
    bool f1_is_D = (face1 == 'J' || face1 == 'K' || face1 == 'L');
    
    bool f1_is_F = (face1 == 'G' || face1 == 'H' || face1 == 'I');
    bool f1_is_B = (face1 == 'P' || face1 == 'Q' || face1 == 'R');
    
    bool f1_is_R = (face1 == 'D' || face1 == 'E' || face1 == 'F');
    bool f1_is_L = (face1 == 'M' || face1 == 'N' || face1 == 'O');
    
    bool f2_is_U = (face2 == 'A' || face2 == 'B' || face2 == 'C');
    bool f2_is_D = (face2 == 'J' || face2 == 'K' || face2 == 'L');
    
    bool f2_is_F = (face2 == 'G' || face2 == 'H' || face2 == 'I');
    bool f2_is_B = (face2 == 'P' || face2 == 'Q' || face2 == 'R');
    
    bool f2_is_R = (face2 == 'D' || face2 == 'E' || face2 == 'F');
    bool f2_is_L = (face2 == 'M' || face2 == 'N' || face2 == 'O');

    // Checa os pares opostos
    if ((f1_is_U && f2_is_D) || (f1_is_D && f2_is_U)) { return true; }
    if ((f1_is_F && f2_is_B) || (f1_is_B && f2_is_F)) { return true; } 
    if ((f1_is_R && f2_is_L) || (f1_is_L && f2_is_R)) { return true; }
    
    return false;
}

// ================================
//      EXECUÇÃO SINGLE
// ================================
void RaidenExecutarSimples(char motor){
    int dirPin, stepPin, enablePin, dir, passos;
    
    if (configurarMotor(motor, dirPin, stepPin, enablePin, dir, passos)) {
        digitalWrite(enablePin, LOW); // Ativa driver
        digitalWrite(dirPin, dir);

        for (int i = 0; i < passos; i++) {
            digitalWrite(stepPin, HIGH);
            digitalWrite(LED_BUILTIN, HIGH);
            delayMicroseconds(DELAY_STEP);
            digitalWrite(stepPin, LOW);
            digitalWrite(LED_BUILTIN, LOW);
            delayMicroseconds(DELAY_STEP);
        }
        digitalWrite(enablePin, HIGH); // Desativa driver
    }
}

// ================================
//      EXECUÇÃO DUPLA (OTIMIZADA)
// ================================
void RaidenExecutarDuplo(char motor1, char motor2) {
    int dirPin1, stepPin1, enablePin1, dir1, passos1;
    int dirPin2, stepPin2, enablePin2, dir2, passos2;

    bool m1Ok = configurarMotor(motor1, dirPin1, stepPin1, enablePin1, dir1, passos1);
    bool m2Ok = configurarMotor(motor2, dirPin2, stepPin2, enablePin2, dir2, passos2);

    if (m1Ok && m2Ok) {
        // Ativa ambos os drivers
        digitalWrite(enablePin1, LOW);
        digitalWrite(enablePin2, LOW);

        // Define direções
        digitalWrite(dirPin1, dir1);
        digitalWrite(dirPin2, dir2);

        int maxPassos = max(passos1, passos2);

        for (int i = 0; i < maxPassos; i++) {
            // Pulsa motor 1 se necessário
            if (i < passos1) digitalWrite(stepPin1, HIGH);
            // Pulsa motor 2 se necessário
            if (i < passos2) digitalWrite(stepPin2, HIGH);
            
            digitalWrite(LED_BUILTIN, HIGH);
            delayMicroseconds(DELAY_STEP);

            // Desliga pulso motor 1
            if (i < passos1) digitalWrite(stepPin1, LOW);
            // Desliga pulso motor 2
            if (i < passos2) digitalWrite(stepPin2, LOW);

            digitalWrite(LED_BUILTIN, LOW);
            delayMicroseconds(DELAY_STEP);
        }

        // Desativa ambos os drivers
        digitalWrite(enablePin1, HIGH);
        digitalWrite(enablePin2, HIGH);
    }
}

// ================================
//             SETUP
// ================================
void setup(){
    Serial.begin(9600);

    // Configura os Pinos de Enable
    pinMode(ENABLE_PIN_1, OUTPUT); digitalWrite(ENABLE_PIN_1, HIGH);
    pinMode(ENABLE_PIN_2, OUTPUT); digitalWrite(ENABLE_PIN_2, HIGH);
    pinMode(ENABLE_PIN_3, OUTPUT); digitalWrite(ENABLE_PIN_3, HIGH);
    pinMode(ENABLE_PIN_4, OUTPUT); digitalWrite(ENABLE_PIN_4, HIGH);
    pinMode(ENABLE_PIN_5, OUTPUT); digitalWrite(ENABLE_PIN_5, HIGH);
    pinMode(ENABLE_PIN_6, OUTPUT); digitalWrite(ENABLE_PIN_6, HIGH);

    // Configura Pinos de Passo e Direção
    pinMode(DIR_PIN_1, OUTPUT); pinMode(STEP_PIN_1, OUTPUT);
    pinMode(DIR_PIN_2, OUTPUT); pinMode(STEP_PIN_2, OUTPUT);
    pinMode(DIR_PIN_3, OUTPUT); pinMode(STEP_PIN_3, OUTPUT);
    pinMode(DIR_PIN_4, OUTPUT); pinMode(STEP_PIN_4, OUTPUT);
    pinMode(DIR_PIN_5, OUTPUT); pinMode(STEP_PIN_5, OUTPUT);
    pinMode(DIR_PIN_6, OUTPUT); pinMode(STEP_PIN_6, OUTPUT);

    pinMode(LED_BUILTIN, OUTPUT);

    Serial.println(">>> SISTEMA OTIMIZADO (DUAL MOVE) PRONTO <<<");
    Serial.println("Envie qualquer coisa para INICIAR.");
}

// ================================
//             LOOP
// ================================
void loop() {

    // 1. ESTADO DE ESPERA (START)
    if (!start) {
        if (Serial.available() > 0) {
            while(Serial.available() > 0) Serial.read(); // Limpa buffer
            
            Serial.println("--- INICIANDO SEQUENCIA ---");
            Serial.println("(Envie 'P' a qualquer momento para PAUSAR)");
            
            start = true;
            tempoInicio = millis();
            tempoTotalPausado = 0;
            indice = 0;
            delay(500);
        } else {
            return;
        }
    }

    // 2. VERIFICAÇÃO DE PAUSA
    if (Serial.available() > 0) {
        char comando = Serial.read();
        if (comando == 'P' || comando == 'p') {
            Serial.println("\n!!! SISTEMA PAUSADO !!!");
            Serial.println("Envie qualquer caractere para CONTINUAR...");
            unsigned long inicioPausa = millis();
            while (Serial.available() == 0) { delay(100); }
            while(Serial.available() > 0) Serial.read();
            tempoTotalPausado += (millis() - inicioPausa);
            Serial.println("... RETOMANDO EXECUCAO ...\n");
        }
    }

    // 3. EXECUÇÃO DA SEQUÊNCIA
    if (indice < sequencia.length()) {
        
        // Calcula tempo
        unsigned long tempoAtualMs = millis() - tempoInicio - tempoTotalPausado;
        float segundos = tempoAtualMs / 1000.0;

        char movAtual = sequencia[indice];
        char movProximo = ' '; // Vazio por padrão
        
        bool executouDuplo = false;

        // Verifica se existe um próximo movimento e se é otimizável
        if (indice < sequencia.length() - 1) {
            movProximo = sequencia[indice + 1];
            
            // LÓGICA DE OTIMIZAÇÃO: Verifica se são opostos
            if (saoOpostos(movAtual, movProximo)) {
                
                // MANTÉM O NÚMERO DOS MOVIMENTOS
                Serial.print("[Tempo: "); Serial.print(segundos); Serial.print("s] ");
                Serial.print("Mov "); Serial.print(indice + 1); Serial.print(" & "); Serial.print(indice + 2);
                Serial.print(" ("); Serial.print(movAtual); Serial.print(" & "); Serial.print(movProximo); Serial.println(")");
                
                RaidenExecutarDuplo(movAtual, movProximo);
                indice += 2; // Pula 2 índices
                executouDuplo = true;
            }
        }

        // Se não foi possível fazer o movimento duplo, faz o simples
        if (!executouDuplo) {
            // MANTÉM O NÚMERO DO MOVIMENTO
            Serial.print("[Tempo: "); Serial.print(segundos); Serial.print("s] ");
            Serial.print("Mov "); Serial.print(indice + 1);
            Serial.print(" ("); Serial.print(movAtual); Serial.println(")");
            
            RaidenExecutarSimples(movAtual);
            indice++; // Pula 1 índice
        }

        delay(0); 
    }

    // 4. FINALIZAÇÃO
    else {
        unsigned long tempoFinalReal = millis() - tempoInicio - tempoTotalPausado;
        Serial.println("\n===== SEQUENCIA CONCLUIDA =====");
        Serial.print("Tempo Total: ");
        Serial.print(tempoFinalReal / 1000.0);
        Serial.println(" segundos.");
        
        start = false;
        Serial.println("Envie 'R' para rodar novamente.");

        while (true) {
            if (Serial.available() > 0) {
                char c = Serial.read();
                if (c == 'R' || c == 'r') {
                    while(Serial.available() > 0) Serial.read();
                    Serial.println("Reiniciando...");
                    start = true;
                    tempoInicio = millis();
                    tempoTotalPausado = 0;
                    indice = 0;
                    break;
                }
            }
        }
    }
}
#endif

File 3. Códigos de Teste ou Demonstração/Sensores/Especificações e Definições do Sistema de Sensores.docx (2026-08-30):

Especificações e Definições do Sistema de Sensores

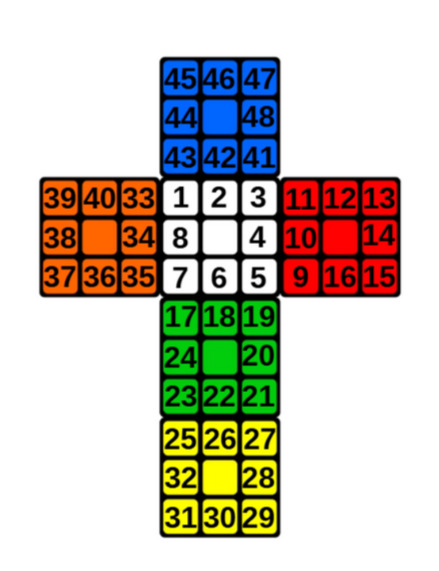
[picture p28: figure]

A figura padrão acima define a ordem de cores e células e este é uma referência que manteremos para todas as estruturas de dados do sistema.

Face | Valor
Up | 0
Right | 1
Front | 2
Down | 3
Left | 4
Back | 5

Up : face = 0

Right : face = 1

Front : face = 2

Down : face = 3

Left : face = 4

Back : face = 5

O sistema consiste de 12 sensores, 2 por face, posicionados nos menores números de cada face, para facilitar o desenvolvimento nomearemos os sensores com duas letras seguindo a regra:

- Primeira letra = primeira letra do nome da face em inglês (Up, Right, Front, Down, Left, Back).
- Segunda letra = primeira letra da posição do sensor em inglês, canto (edge, posição=0) ou centro (center, posição=1).

Exemplo. o sensor Ue pertence a face superior e é o do canto, logo inicialmente sensoria a célula 1 (veja figura padrão).

Como o sensoriamento será realizado um sensor por vez implementarmos multiplexação, logo precisamos associar cada sensor a um número, chamaremos esse valor de NS (Número do Sensor) como relaciona a tabela abaixo (a conexão do mux deve garantir isso):

Quina | NS | Centro | NS
Ue | 0 | Uc | 1
Re | 2 | Rc | 3
Fe | 4 | Fc | 5
De | 6 | Dc | 7
Le | 8 | Lc | 9
Be | 10 | Bc | 11

Ue: 0 | Uc: 1

Re: 2 | Rc: 3

Fe: 4 | Fc: 5

De: 6 | Dc: 7

Le: 8 | Lc: 9

Be: 10 | Bc: 11

NS = 2*face + posição; face=[0,5]; posição=[0,1]

Obs. sensoriamento de uma face segue a ordem sensor da quina primeiro, então centro.

O sensor escolhido para implementar o sistema de sensoriamento foi o módulo TCS34725.

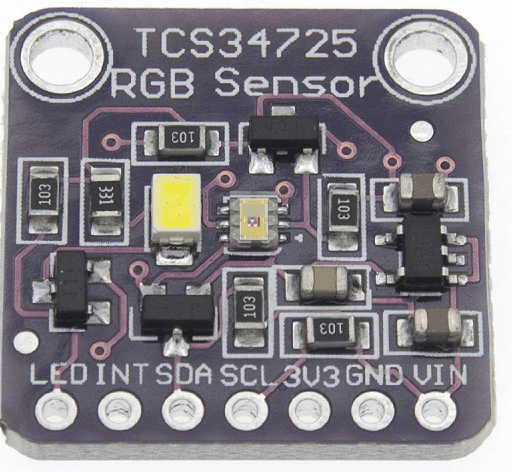
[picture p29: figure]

O TCS34725 é um sensor RGB com comunicação I2C e para operá-lo utilizaremos 5 de seus pinos com relação de cor dos cabos seguindo tabela e imagem abaixo:

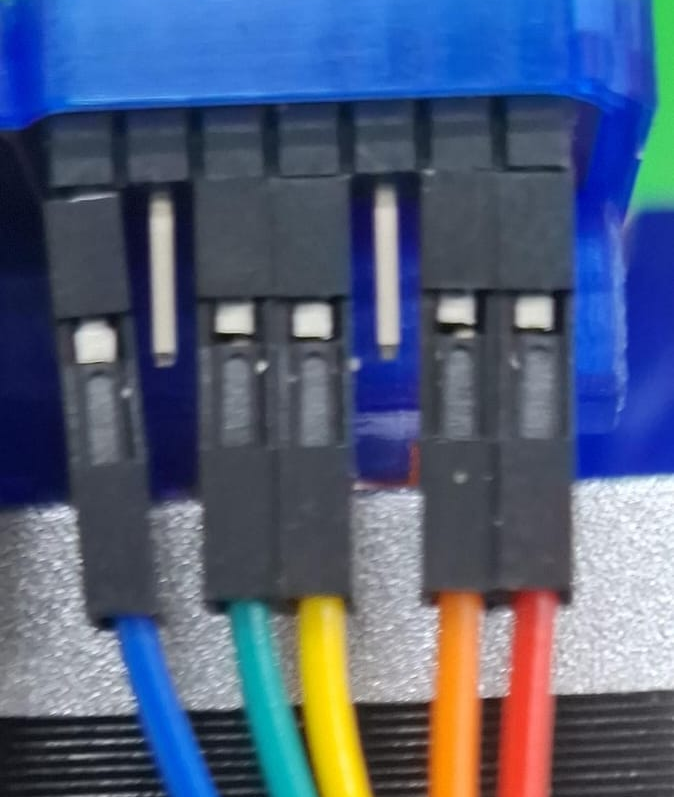
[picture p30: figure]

Pinout | Cor do jumper
LED (Retentivo) | Azul
SDA | Verde
SCL | Amarelo
GND | Laranja
VIN (5V) | Vermelho

Os pinos VIN, GND e SCL de todos os sensores são conectados a um barramento compartilhado. Já os pinos SDA e LED de cada sensor são conectados ao multiplexador (sendo o LED opcional), visto que esses sinais são o que determina a seleção de qual sensor está sendo operado.

O multiplexador escolhido para implementar a multiplexação do sinal SDA dos sensores foi o módulo 74HC4067.

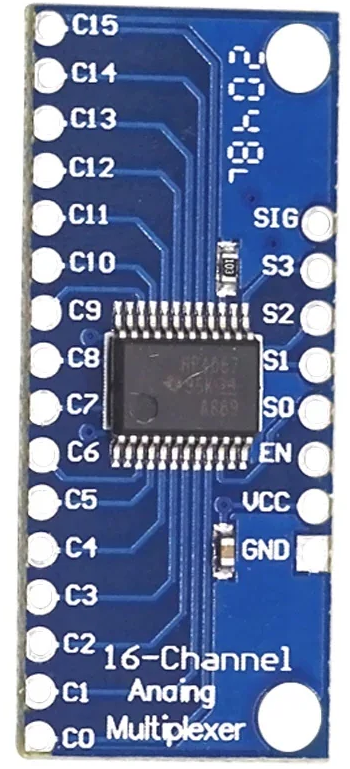
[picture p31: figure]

Sendo o 74HC4067 um multiplexador de 1x12, usaremos:

- Pinos de entrada SIG (SDA de entrada), S[3..0] (endereçamento), EN (pino de habilitação), VCC e GND (Alimentação 5V).
- Pinos de saída C[11..0] para SDA de cada sensor seguindo o número associado ao sensor.

Observação: O sinal LED não é um sinal de alimentação e sim de acionamento e o estado do LED é retentivo.

Estrutura Lógica do Sistema de Sensores

O objetivo final do sistema de sensores é obter uma matriz 6x8 de embaralhamento com valores de cores seguindo os índices indicados na figura acima.

O Sistema de sensoriamento é dividido em dois blocos: Calibração e Leitura Embaralhamento, e para implementá-los é necessário certas funções:

- Controle dos motores. Motor(‘string’)=atuação do motor (já tem).
- Sensoriamento de cor de um sensor em específico, com conversão RGB para HSV. Sensoria(número do sensor)=valor HSV medido (tem parcialmente, falta mux).
- Armazenamento matriz de calibração, recebe um valor HSV e armazena na posição certa. ArmazenarCal(ValorHSV, número do sensor, número da calibração atual)=armazena na matriz de calibração (desenvolvimento inicial).
- Classificação de Cores, utiliza da matriz de calibração e compara valor lido com os HSV referências do respectivo sensor. Classific(número do sensor, valor medido, matriz calibração) = armazena string cor na matriz de embaralhamento (tem apenas classificação de uma cor com referência aleatória, falta mux e incorpora matriz calibração).

Comando motores:

Face | Horário | Inverso | Duplo
Up | A | B | C
Right | D | E | F
Front | G | H | I
Down | J | K | L
Left | M | N | O
Back | P | Q | R

1| ' | 2 - Face

A B C - U

D E F - R

G H I - F

J K L - D

M N O - L

P Q R - B

Exemplo. Motor(‘A’) move o motor superior no sentido horário.

Lógica Bloco Calibração

O objetivo da Calibração é obter uma matriz 12x6 com valores de HSV de cada sensor para cada uma das 6 cores. A organização dos valores dessa matriz é a seguinte:

- Linhas associadas a cada sensor seguindo a ordem definida anteriormente.
- Colunas segue sequência de cores da figura referência (W,R,G,Y,O,B).

Comparativamente, a maior parte da complexidade do Sistema dos Sensores é destinado ao Bloco de Calibração.

Para facilitar o entendimento da lógica deste bloco vamos considerar que no referencial de cada par de sensores as cores são divididas em 2 tipos.

As cores do tipo 1 são as 4 cores que já estão no plano do sensoriamento do sensor, logo para apresentá-las basta movimento simples de rotação.

Já as cores do tipo 2 são as 2 cores que estão na face acima e abaixo no referencial do sensor, para apresentar cada cor do tipo 2 é necessário 2 movimentos.

Exemplo. Para os sensores Ue e Uc as cores do tipo 1 são W, R, Y, O e do tipo 2 B, G.

Par de Sensores | Cores Tipo 1 | Cores Tipo 2 | Ordem
Ue e Uc | W, R, Y, O | B, G | 0, 1, 3, 4, 5, 2
Re e Rc | R, B, O, G | W, Y | 1, 5, 4, 2, 0, 3
Fe e Fc | G, R, B, O | W, Y | 2, 1, 5, 4, 0, 3
De e Dc | Y, R, W, O | G, B | 3, 1, 0, 4, 2, 5
Le e Lc | O, G, R, B | Y, W | 4, 2, 1, 5, 3, 0
Be e Bc | B, O, G, R | Y, W | 5, 4, 2, 1, 3, 0

Obs. As cores estão organizadas por ordem de calibração. Considerando que as combinações destacadas permitem calibração simultânea, pois compartilham plano de movimento no caso de Sensores Alinhados para tipo 1 e Sensores Opostos para tipo 2.

A sequência da Calibração é a seguinte:

- Calibração Cores Tipo 1 das Faces 0 e 3 (Up e Down, +16/72);
- Calibração Cores Tipo 1 Faces dos Sensores Alinhados (1,2,4,5. +32/72);
- Calibração Cores Tipo 2 Faces dos Sensores Opostos 0 e 3 (Up e Down, +8/72);
- Calibração Cores Tipo 2 Faces dos Sensores Opostos 1 e 4 (Right e Left, +8/72);
- Calibração Cores Tipo 2 Faces dos Sensores Opostos 2 e 5 (Front e Back, +8/72);

Uma consequência da Sequência de Calibração definida acima é que precisamos definir a sequência de sensoriamento por face, logo definimos Vetor Sequência Faces.

Vetor Sequencia Faces Calibração =

{0,3,0,3,0,3,0,3,2,1,5,4,2,1,5,4,2,1,5,4,2,1,5,4,0,3,0,3,2,5,2,5,1,4,1,4}

// Tipo 1: 4x UD, 4x FRBL;

// Tipo 2: 2x UD, 2x FB, 2x RL

Outra consequência é que precisamos operar os motores em momentos específicos, logo definimos o:

Vetor Indicador Movimento =

{0,0,1,0,1,0,1,0,1,0,0,0,1,0,0,0,1,0,0,0,1,0,0,0,1,0,1,0,1,0,1,0,1,0,1,0,1}

// 0 é sem movimento, 1 faz string de movimento

// Tipo 1 UD: (0,0,1,0,1,0,1,0)

// Tipo 1 FRBL: 4x(1,0,0,0)

// Tipo 2 UD: (1,0,1,0)

// Tipo 2 FB: (1,0,1,0)

// Tipo 2 RL: (1,0,1,0)

// Volta para montado: 1

// Total de 14 strings de movimento são necessárias

Vetor Sequência de Movimentos = {PG, PG, PG, PG, A, A, A, A E BK, JA F BK, JA F HP, GQ F HP, GQE Q EM, DN R EM,

DN Q}

// Tipo 1 UD: 3x PG

// Tipo 1 FRBL: PG + 3x A

// Tipo 2 UD: A E BK(mostra Azul pro Up e Verde pro Down) + JA F BK (mostra Verde pro Up e Azul pro Down)

// Tipo 2 FB: JA F HP (Mostra Branco pro Front e Amarelo pro Back) + GQ F HP (Mostra Amarelo pro Front e Branco pro Back)

// Tipo 2 RL: GQE Q EM (Mostra Branco pro Right e Amarelo pro Left) + DN R EM (Mostra Amarelo pro Right e Amarelo pro Left).

// Retorna pro original. DN Q

Como o sensoriamento da calibração descrita acima não segue a ordem padrão, precisamos de uma matriz auxiliar para saber como armazenar de forma correta os valores na matriz calibração. Chamamos essa matriz de Matriz Ordem.

Considerando a sequência de calibração, sabemos que a calibração de cada sensor segue a ordem temporal mostrada na tabela anterior.

Logo durante a calibração sempre que for obtido um valor de HSV deve ser referido a matriz de ordem abaixo para saber a posição na matriz de calibração que o valor deve ser armazenado.

int Matriz_ordem_cal[6][6] = {

// matriz de ordem para orientar a matriz de calibração de acordo com o padrão

{0, 1, 3, 4, 5, 2}

{1, 5, 4, 2, 0, 3}

{2, 1, 5, 4, 0, 3}

{3, 1, 0, 4, 2, 5}

{4, 2, 1, 5, 3, 0}

{5, 4, 2, 1, 3, 0}

};

Cada linha da matriz ordem representa uma face do cubo, já a coluna o progresso da calibração dos sensores daquela face e o valor é a posição de armazenamento do valor obtido na matriz Calibração.

Para utilizar a Matriz Ordem precisamos de um vetor variável de 6 valores para indicar a progressão da calibração de cada face (quantas cores já foram calibradas para aquele par de sensores), chamamos este de Vetor Progressão inicializado em {0,0,0,0,0,0}.

Obs. Fim da Calibração, Vetor Progressão = {6,6,6,6,6,6}.

Além disso os vetores de sequência de Face, Movimentos e Indicador de Movimento só podem ser utilizados se soubermos qual a calibração atual (variável de progressão/etapas), usaremos a variável Estado para se referir a etapa atual, inicializada em 0 e incrementada a cada nova calibração de um sensor, tendo máximo de 72 quando encerra o sistema de calibração.

Exemplo. Se o valor de Vetor Indicador de Movimento para posição (Estado/2 - 1) for 1, então um movimento deve ser executado.

Fluxograma da Calibração

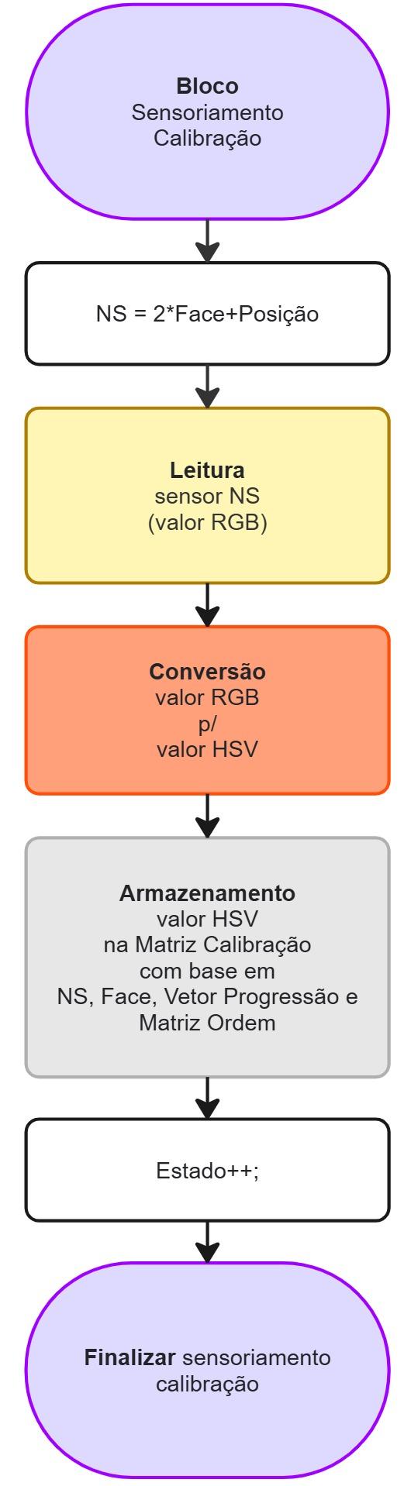
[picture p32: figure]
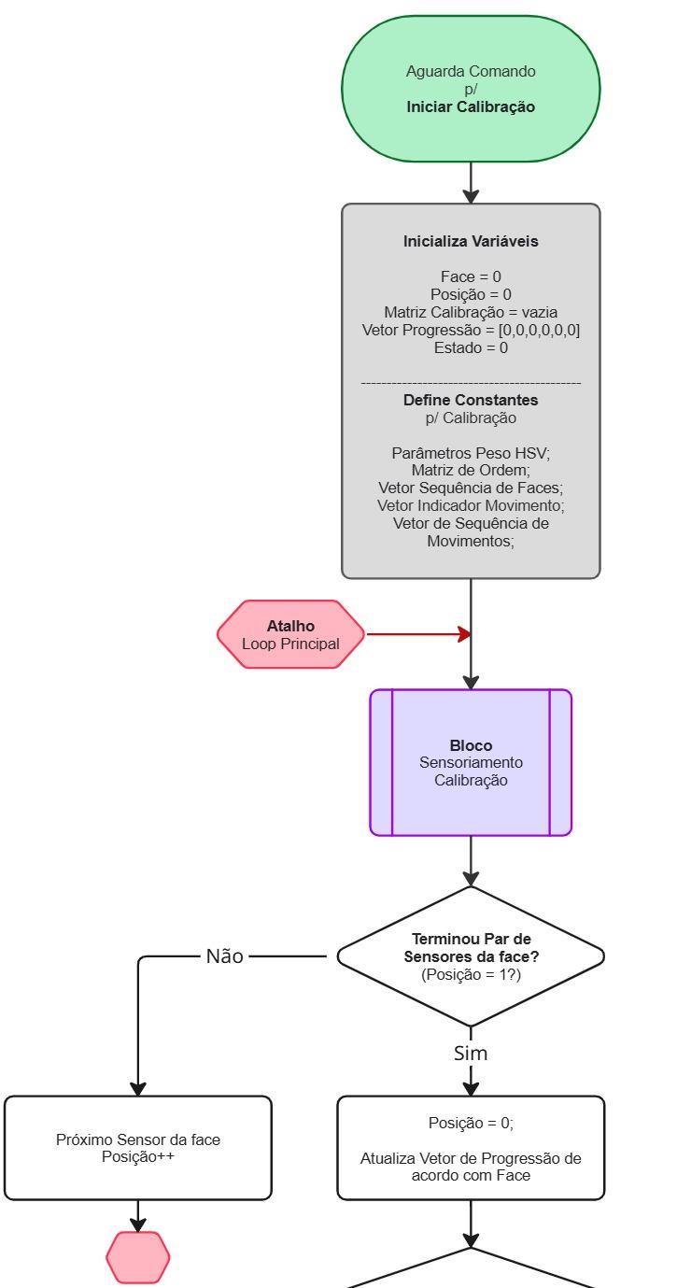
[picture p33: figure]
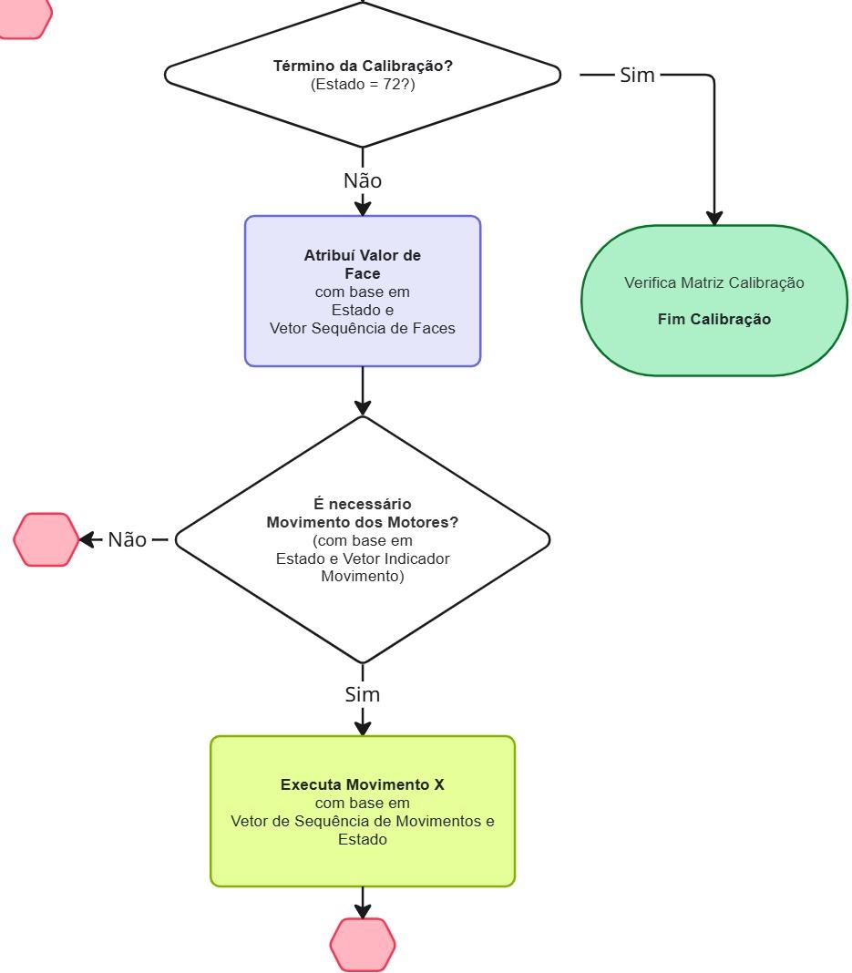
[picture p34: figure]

Transcrição Fluxograma da Calibração

—-------------------------------------------------------------------------------------------------------------

Realiza Calibração Cores Tipo 1 das Faces Up e Down

Repete 4 vezes:

Calibra(Ue,Uc,De,Dc:mux-0,1,6,7) // +16/72

Motores(Back e Front: ‘PG’)

—-------------------------------------------------------------------------------------------------------------

Realiza Calibração Cores Tipo 1 das Faces de Sensores Alinhadas

Front, Right, Back, Left

Calibra(Fe,Fc,Re,Rc,Be,Bc,Le,Lc:mux-4,5,2,3,10,11,8,9) // +8/72

Repete 3 vezes:

Motores(Up:’A’)

Calibra(Fe,Fc,Re,Rc,Be,Bc,Le,Lc:mux-4,5,2,3,10,11,8,9) // +24/72

—-------------------------------------------------------------------------------------------------------------

Realiza Calibração Cores Tipo 2 das Faces Up e Down

Motores(‘AEBK’) // mostra Azul pro Up e Verde pro Down)

Calibra(Ue,Uc,De,Dc:mux-0,1,6,7) // +4/72

Motores(‘JAFBK’) // mostra Verde pro Up e Azul pro Down)

Calibra(Ue,Uc,De,Dc:mux-0,1,6,7) // +4/72

—-------------------------------------------------------------------------------------------------------------

Realiza Calibração Cores Tipo 2 das Faces Front e Back

Motores(‘JAFHP’) // mostra Branco pro Front e Amarelo pro Back

Calibra(Fe,Fc,Be,Bc:mux-4,5,10,11) // +4/72

Motores(‘GQFHP’) // mostra Amarelo pro Front e Branco pro Back

Calibra(Fe,Fc,Be,Bc:mux-4,5,10,11) // +4/72

—-------------------------------------------------------------------------------------------------------------

Realiza Calibração Cores Tipo 2 das Faces Right e Left

Motores(‘GQEQEM’) // mostra Branco pro Right e Amarelo pro Left

Calibra(Re,Rc,Be,Bc,Le,Lc:mux-2,3,8,9) // +4/72

Motores(‘DNREM’) // mostra Amarelo pro Right e Amarelo pro Left

Calibra(Re,Rc,Be,Bc,Le,Lc:mux-2,3,8,9) // +4/72

—-------------------------------------------------------------------------------------------------------------

Motores(‘DNQ’) // retorna cubo para estado original

—-------------------------------------------------------------------------------------------------------------

// Matriz de calibração 12x6 obtida.

Lógica Leitura Embaralhamento

O objetivo da Leitura Embaralhamento é obter uma matriz 6x8 com valores sendo caracteres que indicam cores da configuração do cubo embaralhado. A ordem segue o padrão estabelecido pela figura referência.

Vamos aproveitar de conceitos e definições feitas na lógica de calibração, logo definimos que para leitura de calibração:

- Vetor Progressão termina em {8,8,8,8,8,8};
- Estado encerra leitura quando igual a 48;
- 12 Sequências de Movimentos são necessários.
- Podemos fazer a leitura de faces opostas sem mover.

Logo definimos os vetores de operação abaixo.

Vetor Sequência Faces Embaralhamento =

{0,3,0,3,0,3,0,3,2,5,2,5,,2,5,2,5,1,4,1,4,1,4,1,4}

// 4x UD, 4x FB, 4x RL

Vetor Sequência Movimentos =

{BK,BK,BK,BK,HQ,HQ,HQ,HQ,EN,EN,EN,EN}

Vetor Índices Movimento =

{0,0,1,0,1,0,1,0,1,0,1,0,1,0,1,0,1,0,1,0,1,0,1,0,1,0}

Fluxograma Leitura Embaralhamento

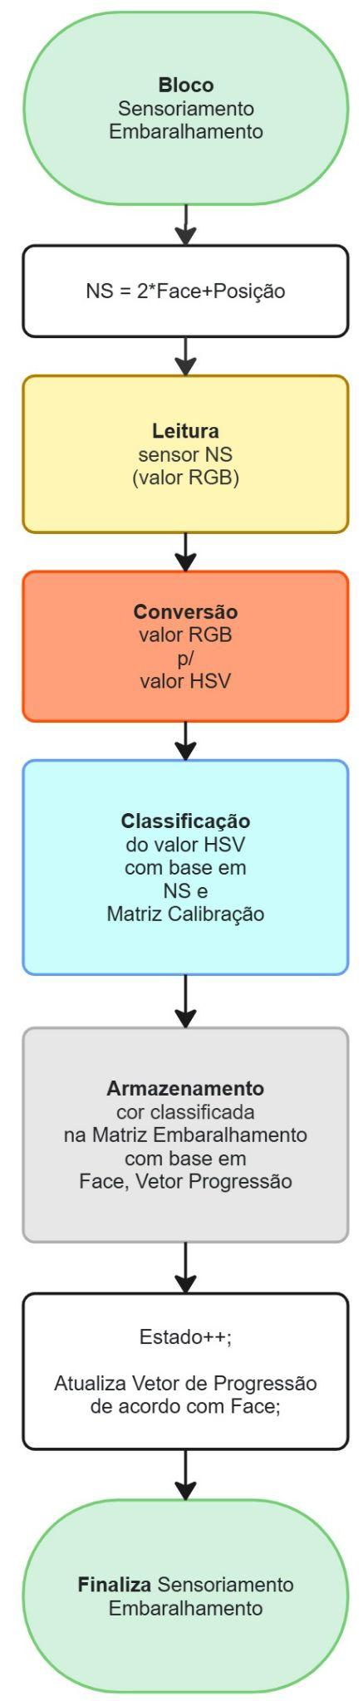
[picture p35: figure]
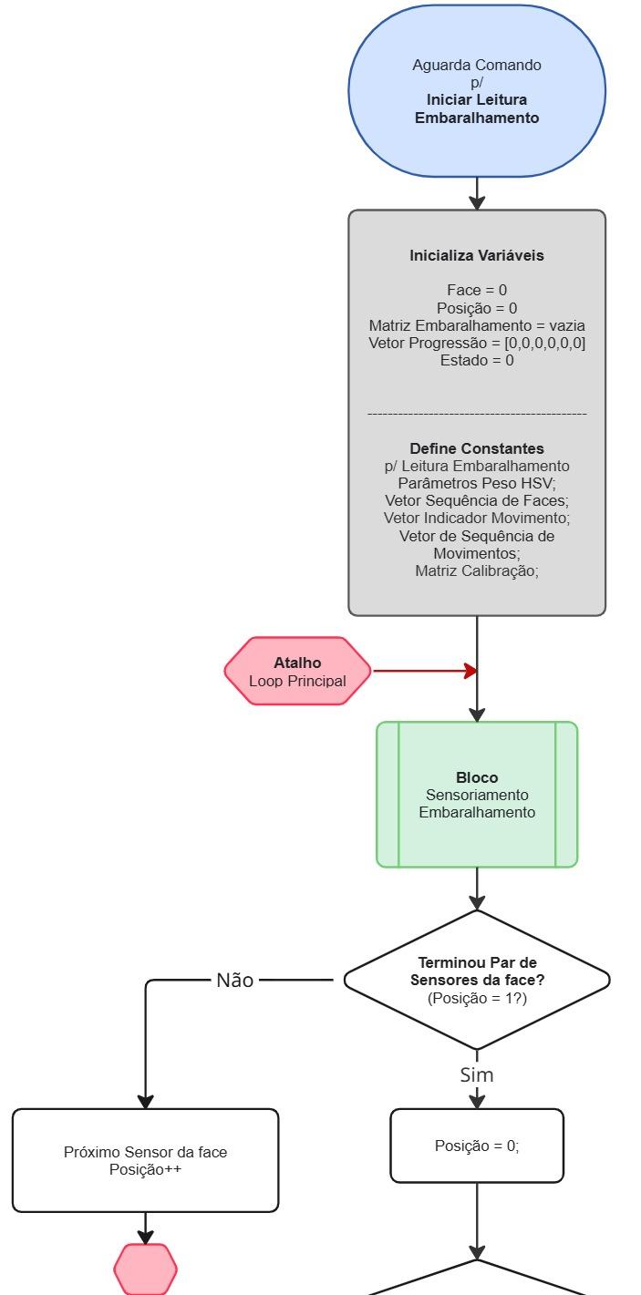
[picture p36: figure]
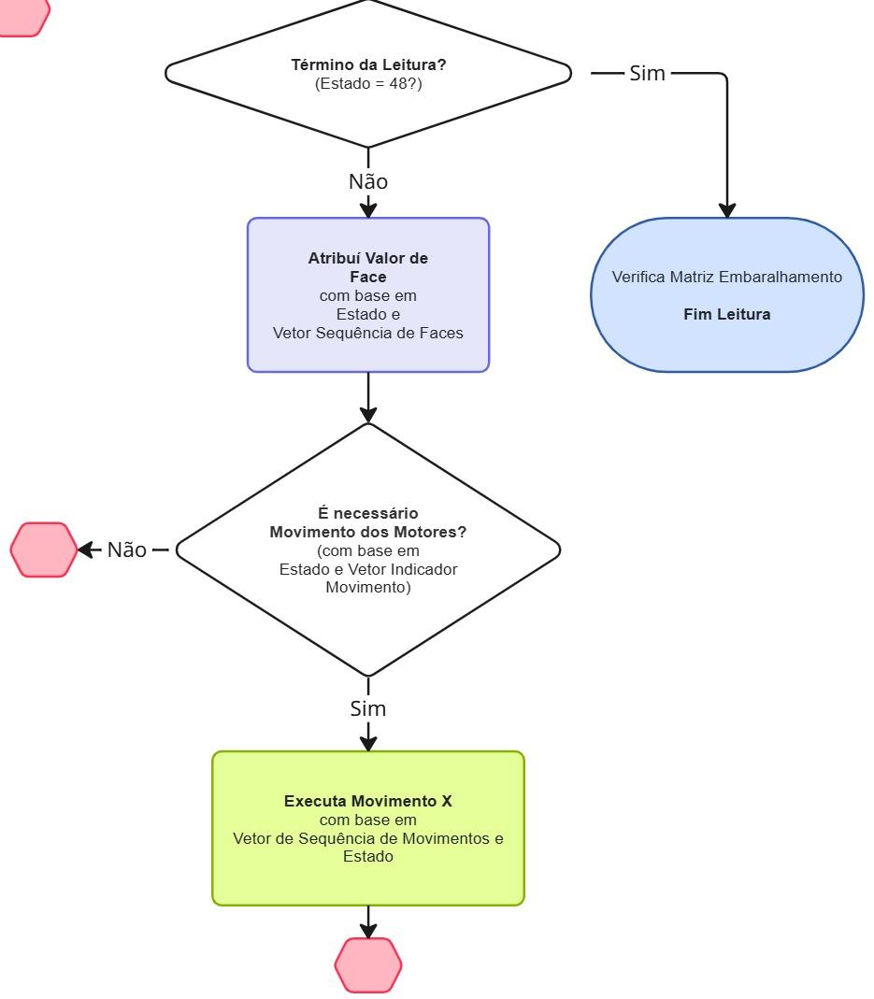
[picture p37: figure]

Transcrição Fluxograma Leitura Embaralhamento

—-------------------------------------------------------------------------------------------------------------

Realiza Leitura das Faces Up e Down

Repete 4 vezes:

Leitura(Ue,Uc,De,Dc:mux-0,1,6,7) // +16/48

Motores(Up e Down: ‘BK’)

—-------------------------------------------------------------------------------------------------------------

Realiza Leitura das Faces Front e Back

Repete 4 vezes:

Leitura(Fe,Fc,Be,Bc:mux-4,5,10,11) // +16/48

Motores(Front e Back: ‘HQ’)

—-------------------------------------------------------------------------------------------------------------

Realiza Leitura das Faces Right e Left

Repete 4 vezes:

Leitura(Re,Rc,Be,Bc,Le,Lc:mux-2,3,8,9) // +16/48

Motores(Right e Left: ‘EN’)

—-------------------------------------------------------------------------------------------------------------

Matriz de embaralhamento 6x8 obtida.

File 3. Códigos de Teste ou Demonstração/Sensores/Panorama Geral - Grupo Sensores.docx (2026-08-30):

1. Situação Atual do Sistema de Sensores

Atualmente existem duas abordagens para o sensoriamento das cores do cubo:

1.1 Método usando espectro RGB

- Baseado na ideia inicial de leitura do espectro RGB.
- Status:
  - Já testado fora da estrutura.
  - DESCARTADO (DECLINED).

1.2 Método usando espectro HSV

- Baseado no espaço de cores HSV (Hue, Saturation, Value).
- Status:
  - Em andamento (ON GOING).
  - Já testado fora da estrutura.

Observações sobre o método HSV:

- É mais promissor que o RGB.
- É mais sensível à luminosidade, pois a iluminação influencia um dos parâmetros.
- Apesar disso, apresenta maior estabilidade nas combinações de cores principais, como:
  - Branco × Amarelo
  - Vermelho × Laranja
  - Verde × Azul

Expectativa dentro da estrutura:

- As sombras internas não devem causar problemas.
- Na teoria:
  - Quanto maior a penumbra, melhor.
- Isso torna o sistema menos dependente da reflexão dos espectros RGB.

Referência para o modelo de cores:

- HSV (Hue, Saturation, Value)

2. Objetivo do Desenvolvimento

Desenvolver um programa generalizado capaz de operar com 12 sensores de cor e determinar automaticamente as cores do cubo.

3. Tarefas Técnicas Necessárias

3.1 Integração dos sensores na estrutura

É necessário:

- Acoplar fisicamente os sensores na estrutura do sistema.

3.2 Utilizar programas base existentes

Existem dois programas base que já foram testados.

Os alunos devem:

1. Estudar os programas
2. Testá-los novamente
3. Analisar limitações

3.3 Expandir o código para 12 sensores

O programa atual deve ser generalizado.

Isso envolve:

- Modularizar funções para:
  - cálculo de parâmetros
  - determinação de cores
  - coleta de dados dos sensores

Depois disso:

- Criar um fluxo que percorra os 12 sensores
- Montar um vetor com as cores preditas

4. Testes Necessários

Os programas devem ser testados considerando:

4.1 Limitações do sistema

Verificar:

- Distância ideal entre sensor e superfície
- Condições de iluminação

4.2 Teste que ainda não foi realizado

Realizar um experimento com:

- Baixa luminosidade externa
- Apenas a iluminação do LED do sensor

Objetivo:

- Verificar desempenho do sensor sem interferência de luz ambiente.

5. Arquitetura de Comunicação dos Sensores

Os sensores utilizam:

- Protocolo I2C

Problema existente:

- Todos os sensores possuem o mesmo endereço I2C.

Isso impede que vários sensores sejam conectados diretamente no mesmo barramento.

6. Solução para o Problema de Endereço I2C

A solução proposta é:

Multiplexação do sinal SDA

Utilizar um multiplexador (MUX) para controlar qual sensor está ativo.

Características:

- O MUX possui 4 entradas de controle
- Cada configuração habilita um sensor por vez

7. Funcionamento do Sistema com Multiplexador

O sistema deverá seguir o seguinte fluxo:

Etapa 1

Selecionar um sensor no multiplexador.

Etapa 2

Ativar o sensor selecionado.

Etapa 3

Realizar a leitura da cor.

Etapa 4

Executar o algoritmo de predição da cor.

Etapa 5

Registrar o resultado.

Etapa 6

Armazenar a cor detectada em um vetor de estado do cubo.

Etapa 7

Repetir o processo para os 12 sensores.

8. Concepção Atual do Sistema de Sensoriamento

O sistema final deverá conter:

- 12 sensores de cor
- Comunicação via I2C
- Multiplexação de sensores
- Algoritmo de classificação de cores (HSV)
- Vetor representando o estado das cores do cubo

9. Documentação Solicitada

Também é solicitado que seja feita uma documentação simples do projeto.

Essa documentação deve conter:

9.1 Descrição da proposta

Explicação da solução geral adotada.

9.2 Arquitetura de software

Descrever:

- Organização do código
- Estrutura das funções
- Fluxo de leitura dos sensores
- Algoritmo de detecção de cores

9.3 Arquitetura de hardware

Descrever:

- Conexões dos sensores
- Uso do multiplexador
- Comunicação I2C
- Integração com o Arduino Mega

9.4 Objetivo da documentação

Facilitar futuramente:

- O desenvolvimento de uma PCB dedicada para os sensores

✅ Resumo final do objetivo do projeto

Desenvolver um sistema capaz de:

1. Ler 12 sensores de cor
2. Utilizar multiplexação para contornar conflito de endereço I2C
3. Classificar cores usando HSV
4. Armazenar os resultados em um vetor representando o estado do cubo
5. Documentar a arquitetura hardware + software para possível criação de PCB.

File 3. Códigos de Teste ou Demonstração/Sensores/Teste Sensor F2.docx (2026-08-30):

Teste HSV Sensor Front Central (fc)

Notação dos sensores, existe 12 sensores no robô, sendo 2 por face, podemos identificar os sensores por duas letras. A primeira letra é associada a face (F=Front=Verde, R=Right=Vermelho, B=Back=Azul, L=Left=Laranja, U=Up=Branco, D=Down=Amarelo). A segunda letra é associada a posição na face (C=Central, Q=Quina).

| Verde | Vermelho | Azul | Laranja | Branco | Amarelo
Situação 1 (Sem Parte Superior) | 132.39 | 0.00 | 200.53 | 8.52 | 138.35 | 75.67
Situação 2 Com Luz Externa | 117.99 | 2.34 | 200.59 | 5.19 | 96.59 | 52.93
Situação 3 (Com Caixa) | 117.53 | 1.55 | 195.75 | 4.43 | 81.99 | 46.72

Todas as medições foram feitas para condição da fileira superior de mesma cor, para face front de centro verde.

Descrição das situações:

- Situação 1, luz do laboratório acesa, sem o suporte do motor superior.
- Situação 2, luz do laboratório acesa, com o suporte do motor superior
- Situação 3, caixa bloqueando luz externa, com o suporte do motor superior.

Conclusões dos Testes:

- Para esse esse sensor observamos que a luz externa afetou bastante a classificação do Verde e do Branco nas Situações 1 e 2, já que notamos valores HSV muito próximos. Uma justificativa plausível é que a luz do laboratório sendo Branca interferiu com a medida do sensor aumentando os valores. Na situação 3 a classificação melhorou e o melhor ganho foi para o Branco (o que mais mudou) fortalecendo a hipótese anterior.
- Observamos anomalia para cor vermelha quando comparamos a situação 1 com a 2, para todas as outras cores houve ou diminuição ou permanência do valor da situação 1 na 2. Uma justificativa é que a luz do laboratório refletiu no suporte superior laranja e afetou a medida na situação 2. Essa observação não é crítica, pois o Vermelho continua diferenciável o suficiente do Laranja (sua cor mais próxima).

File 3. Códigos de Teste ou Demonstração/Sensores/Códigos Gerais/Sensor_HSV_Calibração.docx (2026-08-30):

/*

Código de Calibração de uma unidade de sensor

Este programa implementa a calibração do parâmetro de classificação de uma cor para um sensor.

O procedimento de calibração consiste em sensoriar uma face com cor conhecida e executando este código

obter HUE_Médio para determinada cor que servirá de parametro de classificação nos sensoriamentos futuros.

Cada um dos 12 sensores deve ter 6 valores de HUE_Médio, um para cada cor.

Logo o programa de calibração completa (a ser implementado) deve obter uma matriz 12x6 com 96 valores.

*/

#include <Wire.h>

#include "TCS34725.h"

TCS34725 tcs;

#define LED_PIN 7

#define AMOSTRAS 20

// ======================= RGB -> HSV

void rgbToHsv(float r, float g, float b, float &h, float &s, float &v) {

float maxc = max(r, max(g, b));

float minc = min(r, min(g, b));

float delta = maxc - minc;

v = maxc;

if (maxc == 0) { s = 0; h = 0; return; }

s = delta / maxc;

if (delta == 0) h = 0;

else if (maxc == r) h = 60.0 * fmod(((g - b) / delta), 6);

else if (maxc == g) h = 60.0 * (((b - r) / delta) + 2);

else h = 60.0 * (((r - g) / delta) + 4);

if (h < 0) h += 360.0;

}

void setup() {

Serial.begin(115200);

Wire.begin();

pinMode(LED_PIN, OUTPUT);

digitalWrite(LED_PIN, HIGH);

if (!tcs.attach(Wire)) {

Serial.println("Sensor nao encontrado!");

while (1);

}

tcs.integrationTime(33);

tcs.gain(TCS34725::Gain::X01);

Serial.println("=== CALIBRACAO DE COR ===");

Serial.println("Coloque APENAS UMA COR na frente do sensor");

delay(4000);

}

void loop() {

float somaHue = 0;

int validas = 0;

for (int i = 0; i < AMOSTRAS; i++) {

while (!tcs.available());

auto c = tcs.color();

float r = c.r, g = c.g, b = c.b;

float soma = r + g + b;

if (soma < 5) continue;

r /= soma;

g /= soma;

b /= soma;

float h, s, v;

rgbToHsv(r, g, b, h, s, v);

somaHue += h;

validas++;

delay(50);

}

if (validas > 0) {

float hueMedio = somaHue / validas;

Serial.print("HUE MEDIO = ");

Serial.println(hueMedio, 2);

} else {

Serial.println("Leitura invalida");

}

while (1); // Para aqui até você reiniciar

}

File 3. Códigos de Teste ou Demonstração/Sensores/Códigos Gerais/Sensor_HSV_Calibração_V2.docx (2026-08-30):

/*

Código de Calibração de uma unidade de sensor

Este programa implementa a calibração do parâmetro de classificação de uma cor para um sensor.

O procedimento de calibração consiste em sensoriar uma face com cor conhecida e executando este código

obter HUE_Médio para determinada cor que servirá de parametro de classificação nos sensoriamentos futuros.

Cada um dos 12 sensores deve ter 6 valores de HUE_Médio, um para cada cor.

Logo o programa de calibração completa (a ser implementado) deve obter uma matriz 12x6 com 96 valores.

*/

#include <Wire.h>

#include "TCS34725.h"

#include <string.h>

TCS34725 tcs;

#define LED_0 2

#define LED_1 3

#define LED_2 4

#define LED_3 5

#define LED_4 6

#define LED_5 7

#define LED_6 8

#define LED_7 9

#define LED_8 10

#define LED_9 11

#define LED_10 12

#define LED_11 13

#define EN_MUX 23

#define MUX_0 22

#define MUX_1 18

#define MUX_2 17

#define MUX_3 15

#define AMOSTRAS 20

struct RGBsum {

float red;

float green;

float blue;

float sum;

};

struct HSV {

float hue;

float sat;

float val;

};

void setup() {

Serial.begin(115200);

Wire.begin();

tcs.integrationTime(33);

tcs.gain(TCS34725::Gain::X01);

pinMode(LED_0, OUTPUT);

pinMode(LED_1, OUTPUT);

pinMode(LED_2, OUTPUT);

pinMode(LED_3, OUTPUT);

pinMode(LED_4, OUTPUT);

pinMode(LED_5, OUTPUT);
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

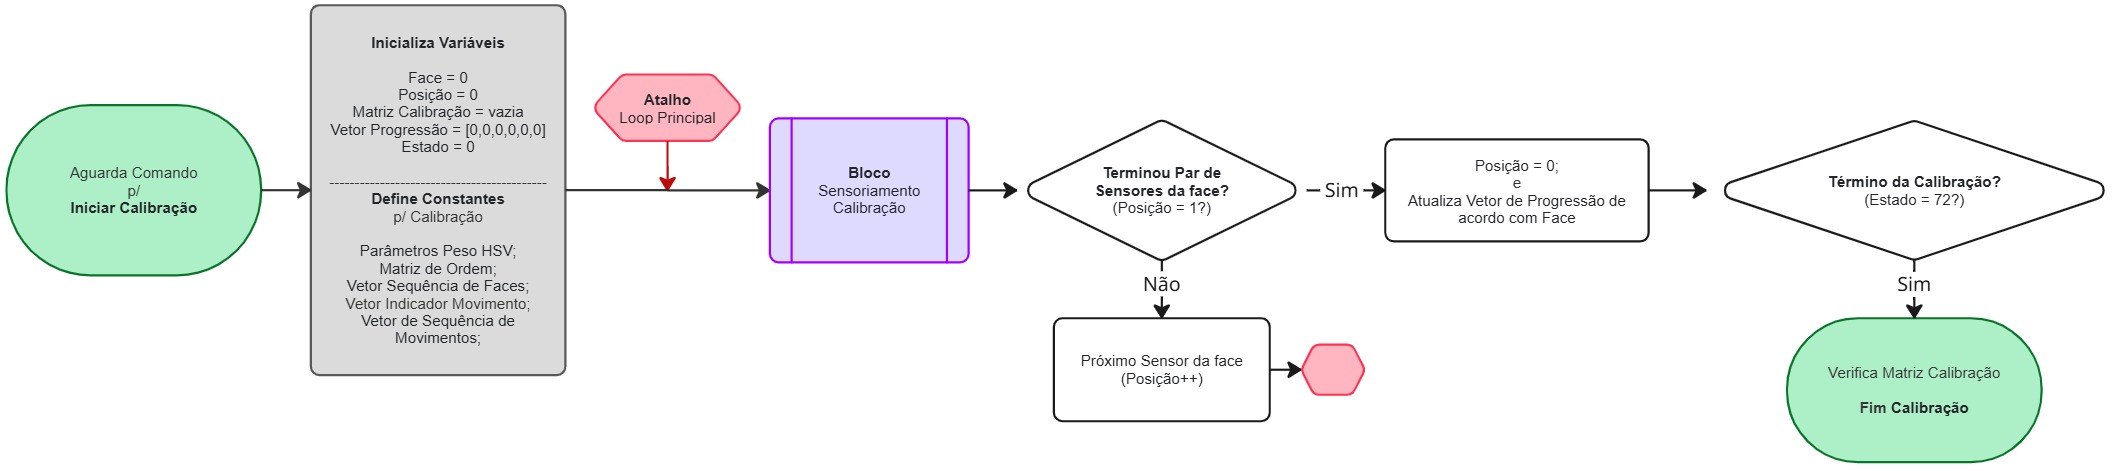
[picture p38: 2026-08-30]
3. Códigos de Teste ou Demonstração/Sensores/Fluxogramas/Fluxograma Calibração - Raiden/Fluxograma na Horizontal/Fluxograma Calibração - Parte1.jpg

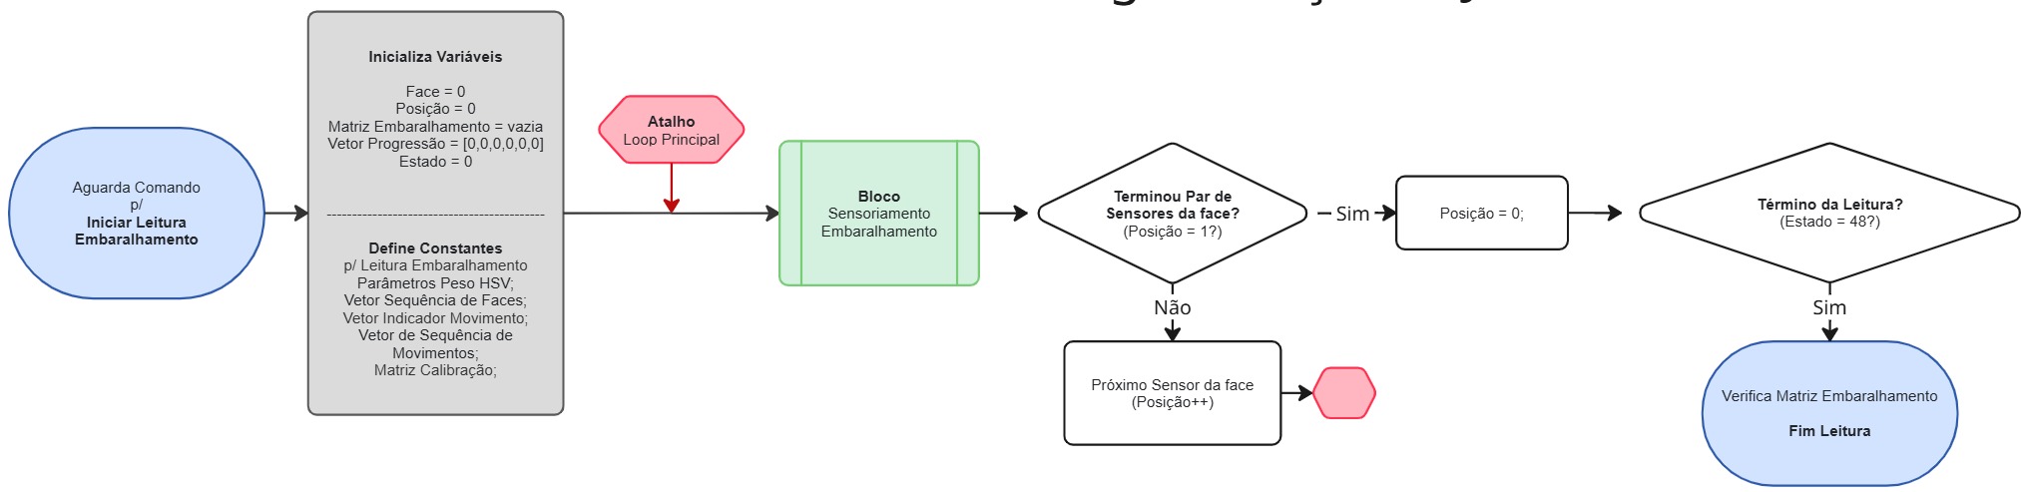
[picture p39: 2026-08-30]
3. Códigos de Teste ou Demonstração/Sensores/Fluxogramas/Fluxograma Leitura Embaralhamento - Raiden/Fluxograma na Horizontal/Fluxograma Leitura Embaralhamento - Parte1.jpg

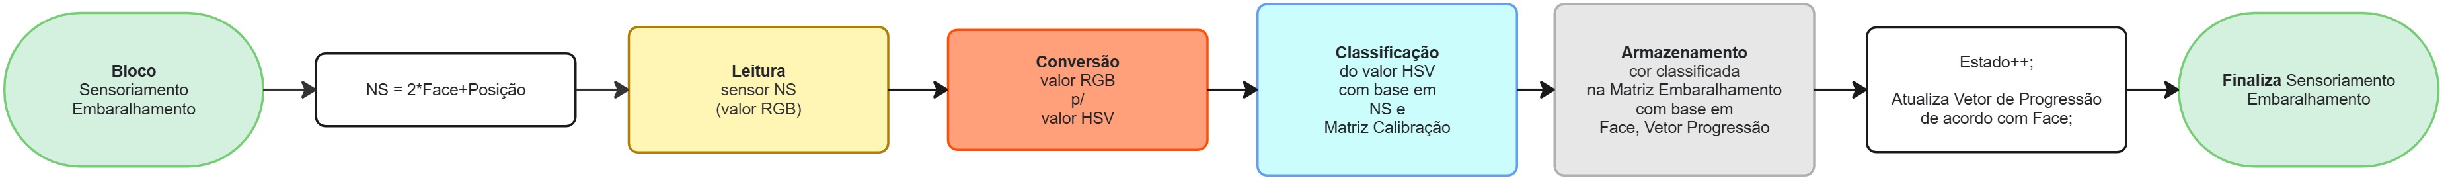
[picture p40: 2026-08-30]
3. Códigos de Teste ou Demonstração/Sensores/Fluxogramas/Fluxograma Leitura Embaralhamento - Raiden/Fluxograma na Horizontal/Fluxograma Sistema dos Sensores - Bloco Sensoriamento Embaralhamento.jpg

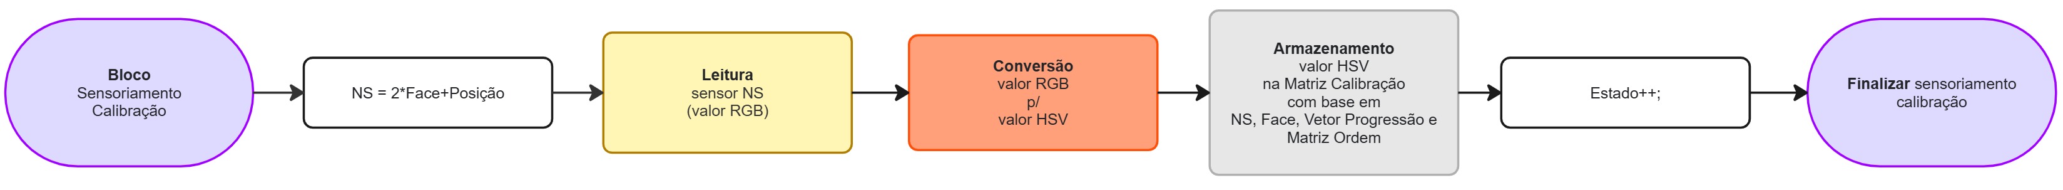
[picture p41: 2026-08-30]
3. Códigos de Teste ou Demonstração/Sensores/Fluxogramas/Fluxograma Calibração - Raiden/Fluxograma na Horizontal/Fluxograma Sistema dos Sensores - Bloco Sensoriamento Calibração.jpg

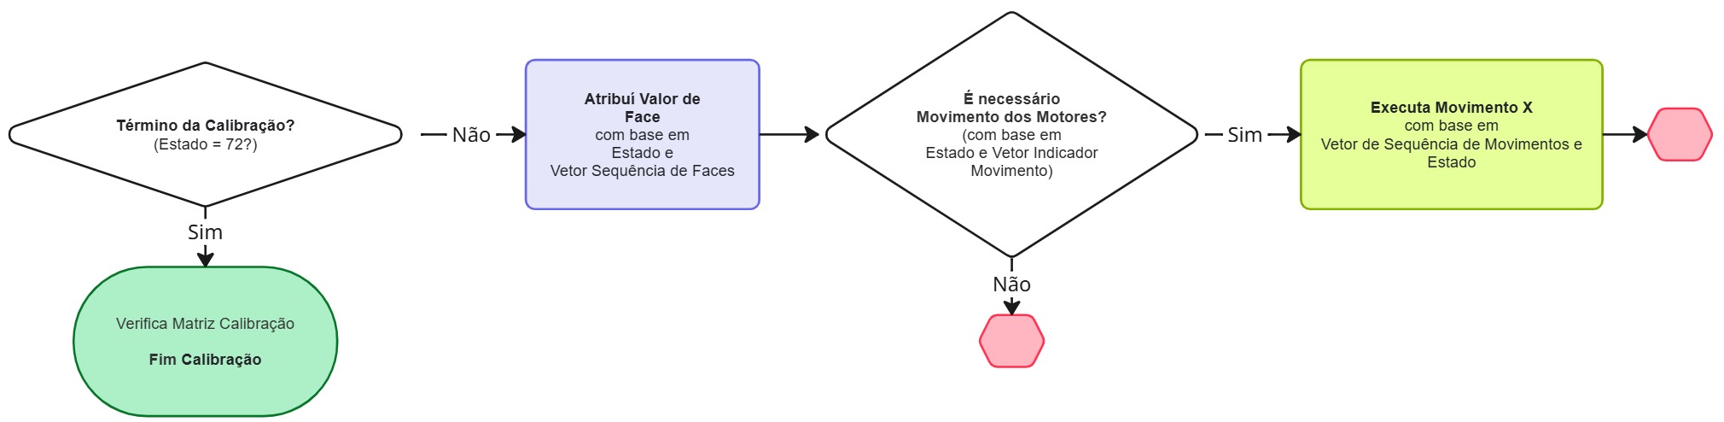
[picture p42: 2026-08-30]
3. Códigos de Teste ou Demonstração/Sensores/Fluxogramas/Fluxograma Calibração - Raiden/Fluxograma na Horizontal/Fluxograma Calibração - Parte2.jpg

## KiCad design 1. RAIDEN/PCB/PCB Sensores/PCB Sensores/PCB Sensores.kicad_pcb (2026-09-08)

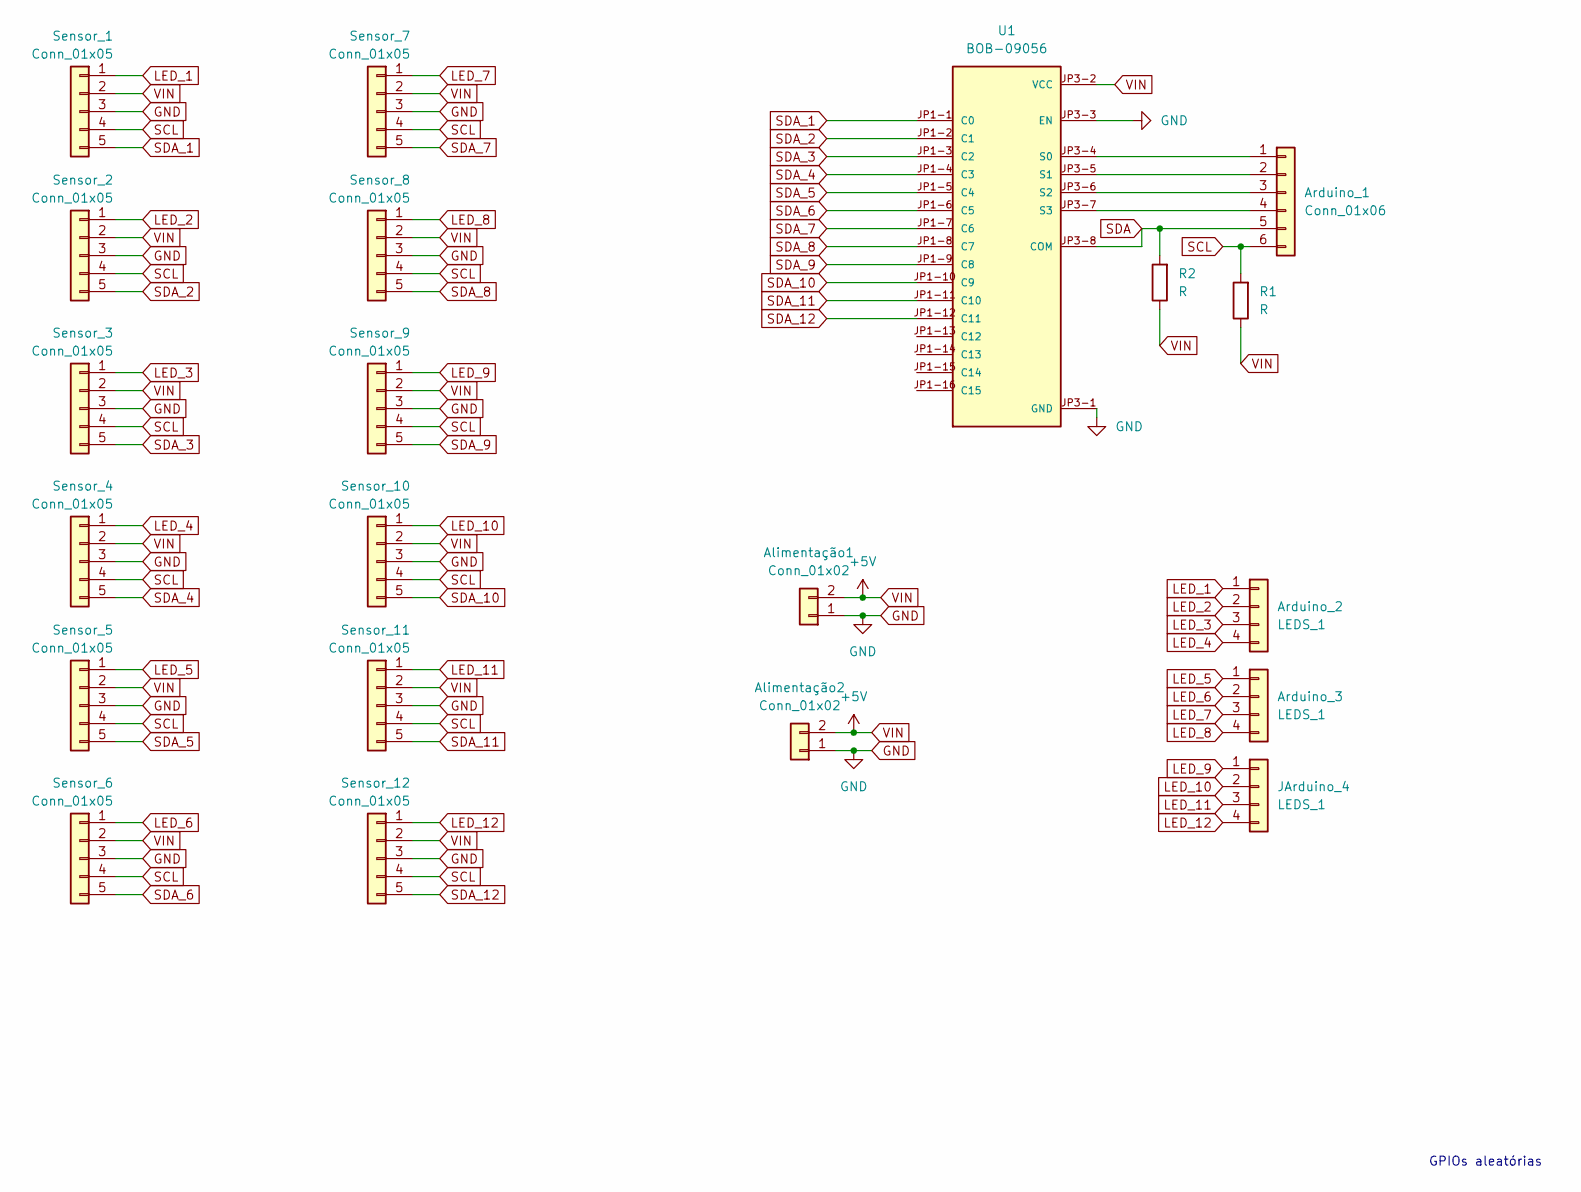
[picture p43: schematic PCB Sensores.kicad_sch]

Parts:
Alimentação1, Alimentação2: Conn_01x02; PinSocket_1x02_P2.54mm_Vertical
Arduino_1: Conn_01x06; PinHeader_1x06_P2.54mm_Vertical
Arduino_2, Arduino_3: LEDS_1; PinSocket_1x04_P2.54mm_Vertical
JArduino_4: LEDS_1; PinSocket_1x04_P2.54mm_Vertical
R1, R2: R; R_Axial_DIN0207_L6.3mm_D2.5mm_P7.62mm_Horizontal
Sensor_1, Sensor_2, Sensor_3, Sensor_4, Sensor_5, Sensor_6, Sensor_7, Sensor_8, Sensor_9, Sensor_10, Sensor_11, Sensor_12: Conn_01x05; PinSocket_1x05_P2.54mm_Vertical
U1: BOB-09056; MODULE_BOB-09056; PARTREV v11

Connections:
GND: Alimentação1.1, Alimentação2.1, Sensor_1.3, Sensor_2.3, Sensor_3.3, Sensor_4.3, Sensor_5.3, Sensor_6.3, Sensor_7.3, Sensor_8.3, Sensor_9.3, Sensor_10.3, Sensor_11.3, Sensor_12.3, U1.JP3-1 (GND), U1.JP3-3 (EN)
LED_1: Arduino_2.1, Sensor_1.1
LED_2: Arduino_2.2, Sensor_2.1
LED_3: Arduino_2.3, Sensor_3.1
LED_4: Arduino_2.4, Sensor_4.1
LED_5: Arduino_3.1, Sensor_5.1
LED_6: Arduino_3.2, Sensor_6.1
LED_7: Arduino_3.3, Sensor_7.1
LED_8: Arduino_3.4, Sensor_8.1
LED_9: JArduino_4.1, Sensor_9.1
LED_10: JArduino_4.2, Sensor_10.1
LED_11: JArduino_4.3, Sensor_11.1
LED_12: JArduino_4.4, Sensor_12.1
unnamed: Arduino_1.1, U1.JP3-4 (S0)
unnamed: Arduino_1.2, U1.JP3-5 (S1)
unnamed: Arduino_1.3, U1.JP3-6 (S2)
unnamed: Arduino_1.4, U1.JP3-7 (S3)
SCL: Arduino_1.6, R1.2, Sensor_1.4, Sensor_2.4, Sensor_3.4, Sensor_4.4, Sensor_5.4, Sensor_6.4, Sensor_7.4, Sensor_8.4, Sensor_9.4, Sensor_10.4, Sensor_11.4, Sensor_12.4
SDA: Arduino_1.5, R2.2, U1.JP3-8 (COM)
SDA_1: Sensor_1.5, U1.JP1-1 (C0)
SDA_2: Sensor_2.5, U1.JP1-2 (C1)
SDA_3: Sensor_3.5, U1.JP1-3 (C2)
SDA_4: Sensor_4.5, U1.JP1-4 (C3)
SDA_5: Sensor_5.5, U1.JP1-5 (C4)
SDA_6: Sensor_6.5, U1.JP1-6 (C5)
SDA_7: Sensor_7.5, U1.JP1-7 (C6)
SDA_8: Sensor_8.5, U1.JP1-8 (C7)
SDA_9: Sensor_9.5, U1.JP1-9 (C8)
SDA_10: Sensor_10.5, U1.JP1-10 (C9)
SDA_11: Sensor_11.5, U1.JP1-11 (C10)
SDA_12: Sensor_12.5, U1.JP1-12 (C11)
VIN: Alimentação1.2, Alimentação2.2, R1.1, R2.1, Sensor_1.2, Sensor_2.2, Sensor_3.2, Sensor_4.2, Sensor_5.2, Sensor_6.2, Sensor_7.2, Sensor_8.2, Sensor_9.2, Sensor_10.2, Sensor_11.2, Sensor_12.2, U1.JP3-2 (VCC)

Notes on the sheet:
GPIOs aleatórias

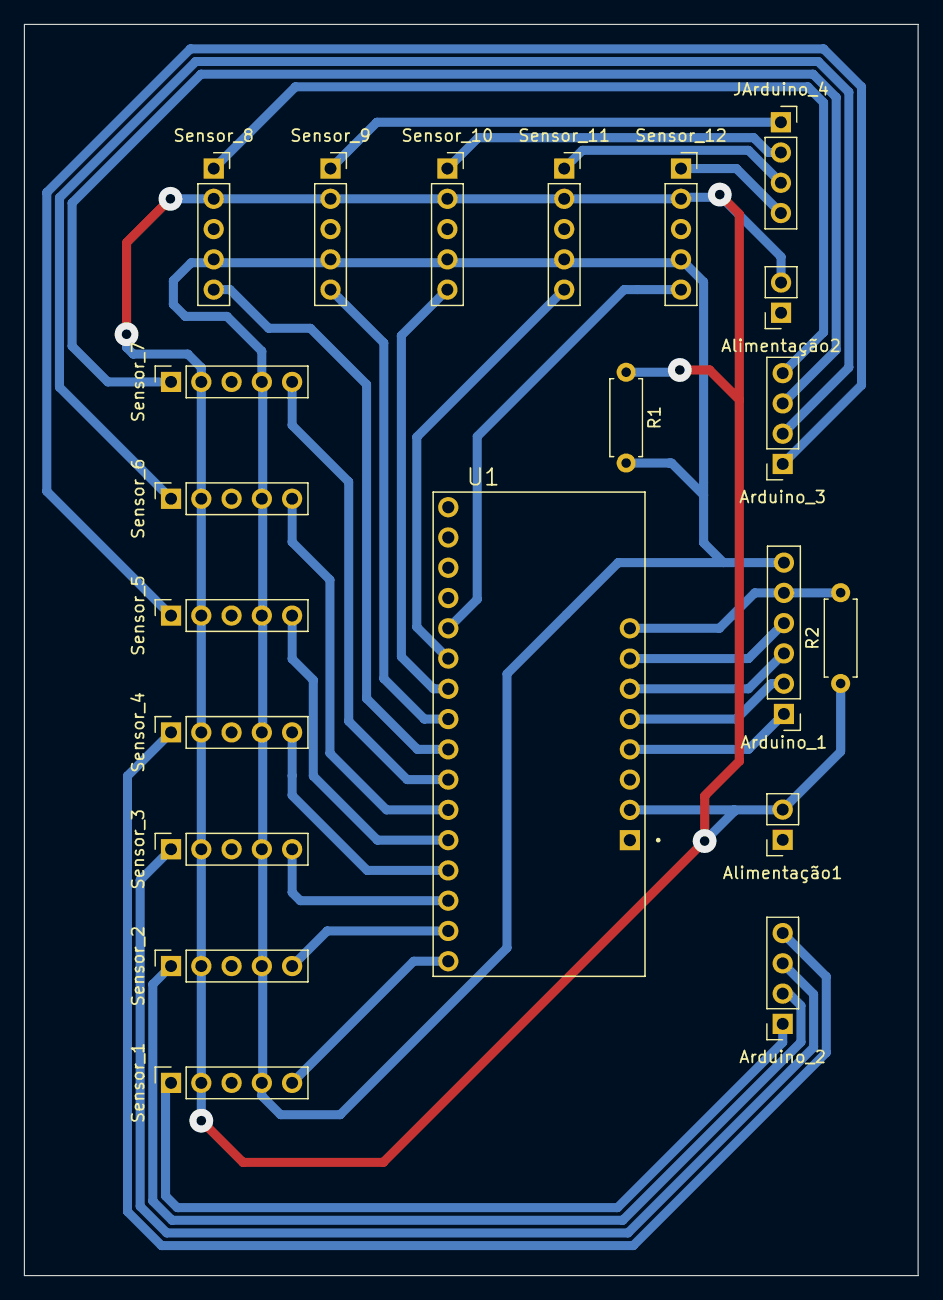
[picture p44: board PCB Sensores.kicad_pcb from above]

Board: 2 copper layers, 75.0 x 105.0 mm, 21 parts (0 on the bottom side), 32 nets.

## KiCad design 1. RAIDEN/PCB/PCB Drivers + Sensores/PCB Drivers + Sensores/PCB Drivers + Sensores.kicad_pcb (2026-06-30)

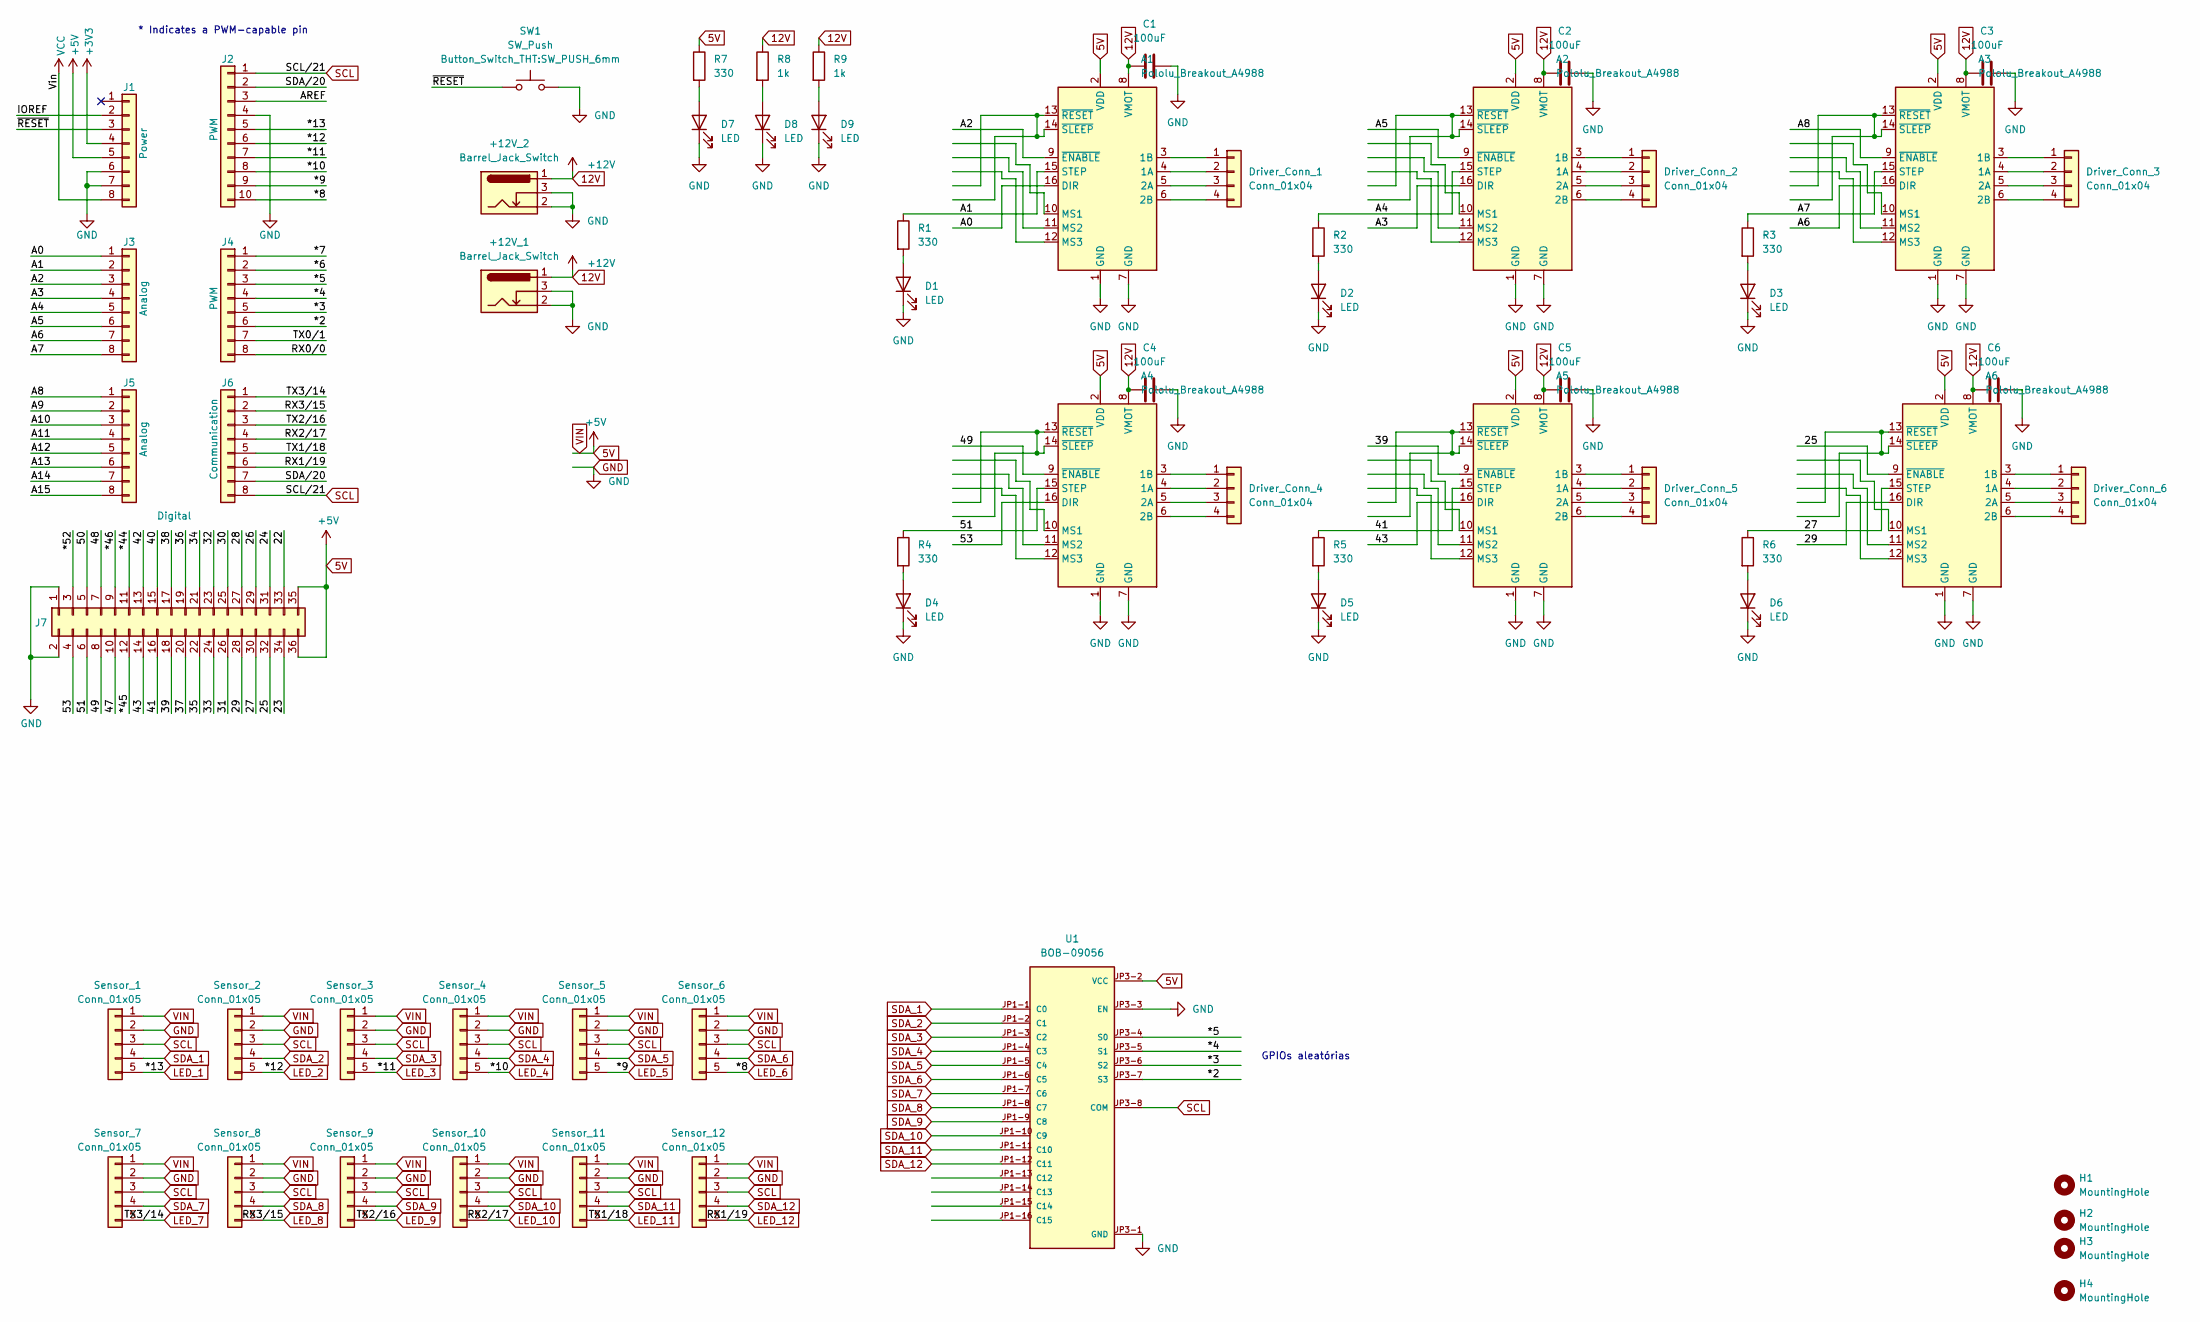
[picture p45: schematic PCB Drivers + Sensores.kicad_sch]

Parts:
+12V_1, +12V_2: Barrel_Jack_Switch; BarrelJack_Horizontal
A1, A2, A3, A4, A5, A6: Pololu_Breakout_A4988; Pololu_Breakout-16_15.2x20.3mm
C1, C2, C3, C4, C5, C6: 100uF; CP_Radial_D8.0mm_P3.50mm
D1, D2, D3, D4, D5, D6, D7, D8, D9: LED; LED_D5.0mm
Driver_Conn_1, Driver_Conn_2, Driver_Conn_3, Driver_Conn_4, Driver_Conn_5, Driver_Conn_6: Conn_01x04; JST_XH_B4B-XH-A_1x04_P2.50mm_Vertical
H1, H2, H3, H4: MountingHole; MountingHole_6mm
J1: Power; PinSocket_1x08_P2.54mm_Vertical
J2: PWM; PinSocket_1x10_P2.54mm_Vertical
J3, J5: Analog; PinSocket_1x08_P2.54mm_Vertical
J4: PWM; PinSocket_1x08_P2.54mm_Vertical
J6: Communication; PinSocket_1x08_P2.54mm_Vertical
J7: Digital; PinSocket_2x18_P2.54mm_Vertical
R1, R2, R3, R4, R5, R6, R7: 330; R_Axial_DIN0207_L6.3mm_D2.5mm_P10.16mm_Horizontal
R8, R9: 1k; R_Axial_DIN0207_L6.3mm_D2.5mm_P10.16mm_Horizontal
SW1: SW_Push; SW_PUSH_6mm
Sensor_1, Sensor_2, Sensor_3, Sensor_4, Sensor_5, Sensor_6, Sensor_7, Sensor_8, Sensor_9, Sensor_10, Sensor_11, Sensor_12: Conn_01x05; JST_XH_B5B-XH-A_1x05_P2.50mm_Vertical
U1: BOB-09056; MODULE_BOB-09056; PARTREV v11

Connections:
5V: A1.2 (VDD), A2.2 (VDD), A3.2 (VDD), A4.2 (VDD), A5.2 (VDD), A6.2 (VDD), J1.5, J7.35, J7.36, R7.1, Sensor_1.1, Sensor_2.1, Sensor_3.1, Sensor_4.1, Sensor_5.1, Sensor_6.1, Sensor_7.1, Sensor_8.1, Sensor_9.1, Sensor_10.1, Sensor_11.1, Sensor_12.1, U1.JP3-2 (VCC)
12V: +12V_1.1, +12V_2.1, A1.8 (VMOT), A2.8 (VMOT), A3.8 (VMOT), A4.8 (VMOT), A5.8 (VMOT), A6.8 (VMOT), C1.1, C2.1, C3.1, C4.1, C5.1, C6.1, R8.1, R9.1
+3V3: J1.4
/22: J7.33
/23: J7.34
/24: J7.31
/25: A6.9 (~ENABLE), J7.32
/26: J7.29
/27: A6.15 (STEP), J7.30, R6.1
/28: J7.27
/29: A6.16 (DIR), J7.28
/30: J7.25
/31: J7.26
/32: J7.23
/33: J7.24
/34: J7.21
/35: J7.22
/36: J7.19
/37: J7.20
/38: J7.17
/39: A5.9 (~ENABLE), J7.18
/40: J7.15
/41: A5.15 (STEP), J7.16, R5.1
/42: J7.13
/43: A5.16 (DIR), J7.14
/47: J7.10
/48: J7.7
/49: A4.9 (~ENABLE), J7.8
/50: J7.5
/51: A4.15 (STEP), J7.6, R4.1
/53: A4.16 (DIR), J7.4
/*2: J4.6, U1.JP3-7 (S3)
/*3: J4.5, U1.JP3-6 (S2)
/*4: J4.4, U1.JP3-5 (S1)
/*5: J4.3, U1.JP3-4 (S0)
/*6: J4.2
/*7: J4.1
/*44: J7.11
/*45: J7.12
/*46: J7.9
/*52: J7.3
/A0: A1.16 (DIR), J3.1
/A1: A1.15 (STEP), J3.2, R1.1
/A2: A1.9 (~ENABLE), J3.3
/A3: A2.16 (DIR), J3.4
/A4: A2.15 (STEP), J3.5, R2.1
/A5: A2.9 (~ENABLE), J3.6
/A6: A3.16 (DIR), J3.7
/A7: A3.15 (STEP), J3.8, R3.1
/A8: A3.9 (~ENABLE), J5.1
/A9: J5.2
/A10: J5.3
/A11: J5.4
/A12: J5.5
/A13: J5.6
/A14: J5.7
/A15: J5.8
/AREF: J2.3
/IOREF: J1.2
/RX0/0: J4.8
/SDA/20: J2.2, J6.7
/TX0/1: J4.7
/~RESET: J1.3, SW1.1
GND: +12V_1.2, +12V_1.3, +12V_2.2, +12V_2.3, A1.1 (GND), A1.7 (GND), A2.1 (GND), A2.7 (GND), A3.1 (GND), A3.7 (GND), A4.1 (GND), A4.7 (GND), A5.1 (GND), A5.7 (GND), A6.1 (GND), A6.7 (GND), C1.2, C2.2, C3.2, C4.2, C5.2, C6.2, D1.1 (K), D2.1 (K), D3.1 (K), D4.1 (K), D5.1 (K), D6.1 (K), D7.1 (K), D8.1 (K), D9.1 (K), J1.6, J1.7, J2.4, J7.1, J7.2, SW1.2, Sensor_1.2, Sensor_2.2, Sensor_3.2, Sensor_4.2, Sensor_5.2, Sensor_6.2, Sensor_7.2, Sensor_8.2, Sensor_9.2, Sensor_10.2, Sensor_11.2, Sensor_12.2, U1.JP3-1 (GND), U1.JP3-3 (EN)
LED_1: J2.5, Sensor_1.5
LED_2: J2.6, Sensor_2.5
LED_3: J2.7, Sensor_3.5
LED_4: J2.8, Sensor_4.5
LED_5: J2.9, Sensor_5.5
LED_6: J2.10, Sensor_6.5
LED_7: J6.1, Sensor_7.5
LED_8: J6.2, Sensor_8.5
LED_9: J6.3, Sensor_9.5
LED_10: J6.4, Sensor_10.5
LED_11: J6.5, Sensor_11.5
LED_12: J6.6, Sensor_12.5
unnamed: A1.4 (1A), Driver_Conn_1.2
unnamed: A1.3 (1B), Driver_Conn_1.1
unnamed: A1.5 (2A), Driver_Conn_1.3
unnamed: A1.6 (2B), Driver_Conn_1.4
unnamed: A1.13 (~RESET), A1.14 (~SLEEP)
unnamed: A2.4 (1A), Driver_Conn_2.2
unnamed: A2.3 (1B), Driver_Conn_2.1
unnamed: A2.5 (2A), Driver_Conn_2.3
unnamed: A2.6 (2B), Driver_Conn_2.4
unnamed: A2.13 (~RESET), A2.14 (~SLEEP)
unnamed: A3.4 (1A), Driver_Conn_3.2
unnamed: A3.3 (1B), Driver_Conn_3.1
unnamed: A3.5 (2A), Driver_Conn_3.3
unnamed: A3.6 (2B), Driver_Conn_3.4
unnamed: A3.13 (~RESET), A3.14 (~SLEEP)
unnamed: A4.4 (1A), Driver_Conn_4.2
unnamed: A4.3 (1B), Driver_Conn_4.1
unnamed: A4.5 (2A), Driver_Conn_4.3
unnamed: A4.6 (2B), Driver_Conn_4.4
unnamed: A4.13 (~RESET), A4.14 (~SLEEP)
unnamed: A5.4 (1A), Driver_Conn_5.2
unnamed: A5.3 (1B), Driver_Conn_5.1
unnamed: A5.5 (2A), Driver_Conn_5.3
unnamed: A5.6 (2B), Driver_Conn_5.4
unnamed: A5.13 (~RESET), A5.14 (~SLEEP)
unnamed: A6.4 (1A), Driver_Conn_6.2
unnamed: A6.3 (1B), Driver_Conn_6.1
unnamed: A6.5 (2A), Driver_Conn_6.3
unnamed: A6.6 (2B), Driver_Conn_6.4
unnamed: A6.13 (~RESET), A6.14 (~SLEEP)
unnamed: D1.2 (A), R1.2
unnamed: D2.2 (A), R2.2
unnamed: D3.2 (A), R3.2
unnamed: D4.2 (A), R4.2
unnamed: D5.2 (A), R5.2
unnamed: D6.2 (A), R6.2
unnamed: D7.2 (A), R7.2
unnamed: D8.2 (A), R8.2
unnamed: D9.2 (A), R9.2
SCL: J2.1, J6.8, Sensor_1.3, Sensor_2.3, Sensor_3.3, Sensor_4.3, Sensor_5.3, Sensor_6.3, Sensor_7.3, Sensor_8.3, Sensor_9.3, Sensor_10.3, Sensor_11.3, Sensor_12.3, U1.JP3-8 (COM)
SDA_1: Sensor_1.4, U1.JP1-1 (C0)
SDA_2: Sensor_2.4, U1.JP1-2 (C1)
SDA_3: Sensor_3.4, U1.JP1-3 (C2)
SDA_4: Sensor_4.4, U1.JP1-4 (C3)
SDA_5: Sensor_5.4, U1.JP1-5 (C4)
SDA_6: Sensor_6.4, U1.JP1-6 (C5)
SDA_7: Sensor_7.4, U1.JP1-7 (C6)
SDA_8: Sensor_8.4, U1.JP1-8 (C7)
SDA_9: Sensor_9.4, U1.JP1-9 (C8)
SDA_10: Sensor_10.4, U1.JP1-10 (C9)
SDA_11: Sensor_11.4, U1.JP1-11 (C10)
SDA_12: Sensor_12.4, U1.JP1-12 (C11)
VCC: J1.8

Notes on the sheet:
GPIOs aleatórias
* Indicates a PWM-capable pin

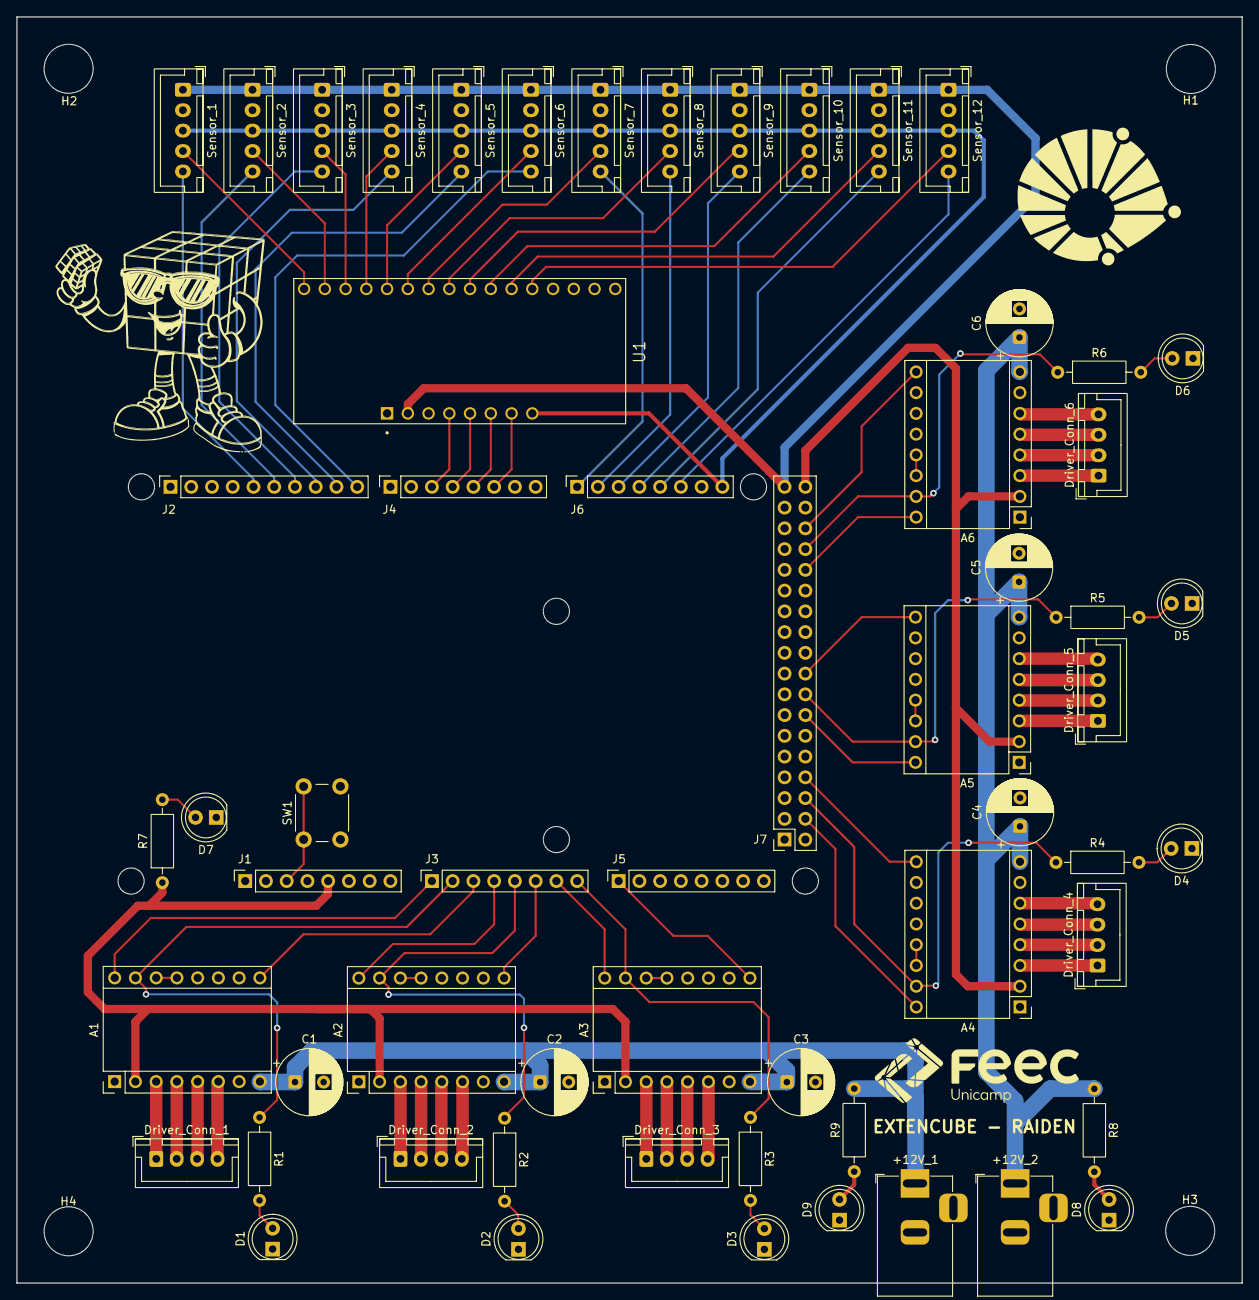
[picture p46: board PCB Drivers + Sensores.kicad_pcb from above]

Board: 2 copper layers, 150.0 x 155.0 mm, 69 parts (0 on the bottom side), 91 nets.

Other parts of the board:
MH1, MH2, MH3, MH4, MH5, MH6: MountingHole_3.2mm

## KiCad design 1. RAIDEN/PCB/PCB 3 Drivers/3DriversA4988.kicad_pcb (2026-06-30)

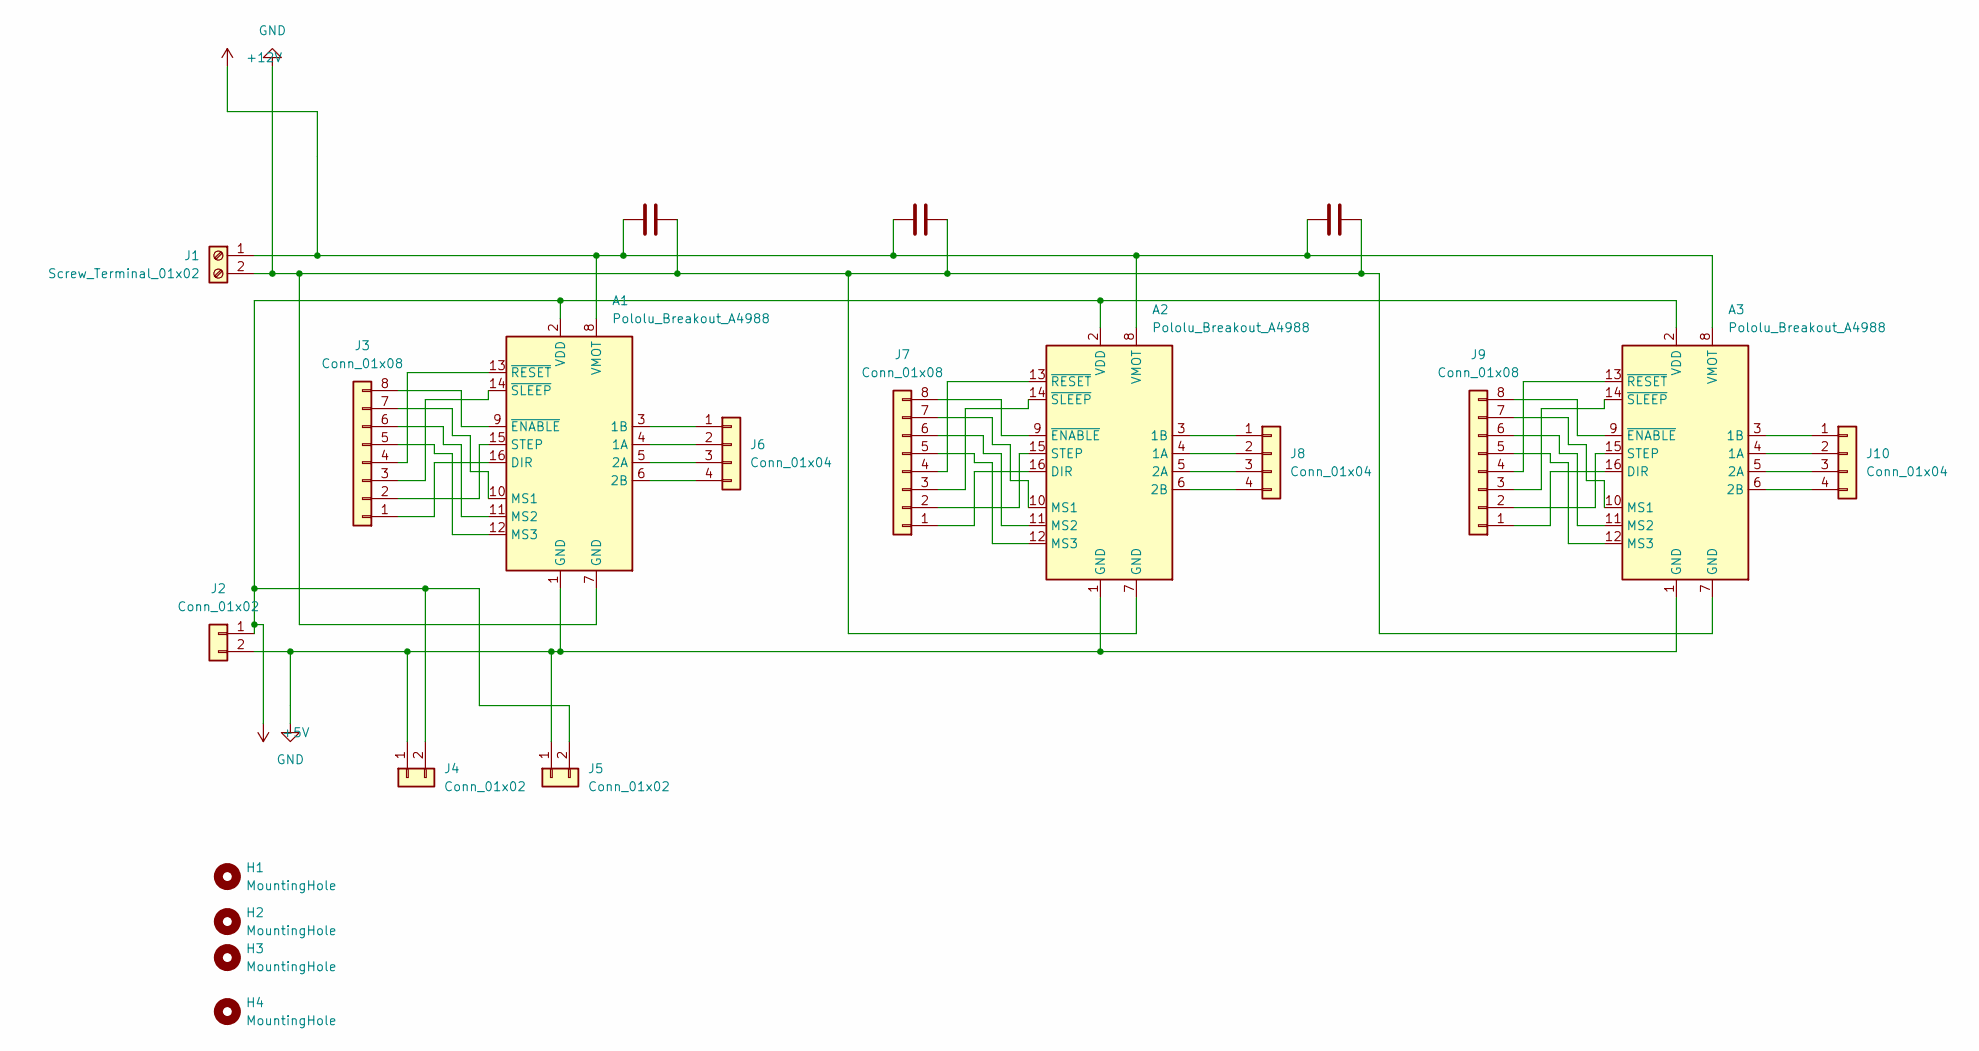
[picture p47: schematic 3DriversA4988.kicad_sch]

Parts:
A1, A2, A3: Pololu_Breakout_A4988; Pololu_Breakout-16_15.2x20.3mm
C1, C2, C3: 100uF; CP_Radial_D6.3mm_P2.50mm
H1, H2, H3, H4: MountingHole; MountingHole_2mm
J1: Screw_Terminal_01x02; TerminalBlock_RND_205-00298_1x02_P10.00mm_Horizontal
J2, J4, J5: Conn_01x02; PinSocket_1x02_P2.54mm_Vertical
J3, J7, J9: Conn_01x08; PinSocket_1x08_P2.54mm_Vertical
J6, J8, J10: Conn_01x04; PinSocket_1x04_P2.54mm_Vertical

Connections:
+5V: A1.2 (VDD), A2.2 (VDD), A3.2 (VDD), J2.1, J4.2, J5.2
+12V: A1.8 (VMOT), A2.8 (VMOT), A3.8 (VMOT), C1.2, C2.2, C3.2, J1.1
GND: A1.1 (GND), A1.7 (GND), A2.1 (GND), A2.7 (GND), A3.1 (GND), A3.7 (GND), C1.1, C2.1, C3.1, J1.2, J2.2, J4.1, J5.1
unnamed: A1.4 (1A), J6.2
unnamed: A1.3 (1B), J6.1
unnamed: A1.5 (2A), J6.3
unnamed: A1.6 (2B), J6.4
unnamed: A1.16 (DIR), J3.1
unnamed: A1.10 (MS1), J3.7
unnamed: A1.11 (MS2), J3.6
unnamed: A1.12 (MS3), J3.5
unnamed: A1.15 (STEP), J3.2
unnamed: A1.9 (~ENABLE), J3.8
unnamed: A1.13 (~RESET), J3.4
unnamed: A1.14 (~SLEEP), J3.3
unnamed: A2.4 (1A), J8.2
unnamed: A2.3 (1B), J8.1
unnamed: A2.5 (2A), J8.3
unnamed: A2.6 (2B), J8.4
unnamed: A2.16 (DIR), J7.1
unnamed: A2.10 (MS1), J7.7
unnamed: A2.11 (MS2), J7.6
unnamed: A2.12 (MS3), J7.5
unnamed: A2.15 (STEP), J7.2
unnamed: A2.9 (~ENABLE), J7.8
unnamed: A2.13 (~RESET), J7.4
unnamed: A2.14 (~SLEEP), J7.3
unnamed: A3.4 (1A), J10.2
unnamed: A3.3 (1B), J10.1
unnamed: A3.5 (2A), J10.3
unnamed: A3.6 (2B), J10.4
unnamed: A3.16 (DIR), J9.1
unnamed: A3.10 (MS1), J9.7
unnamed: A3.11 (MS2), J9.6
unnamed: A3.12 (MS3), J9.5
unnamed: A3.15 (STEP), J9.2
unnamed: A3.9 (~ENABLE), J9.8
unnamed: A3.13 (~RESET), J9.4
unnamed: A3.14 (~SLEEP), J9.3

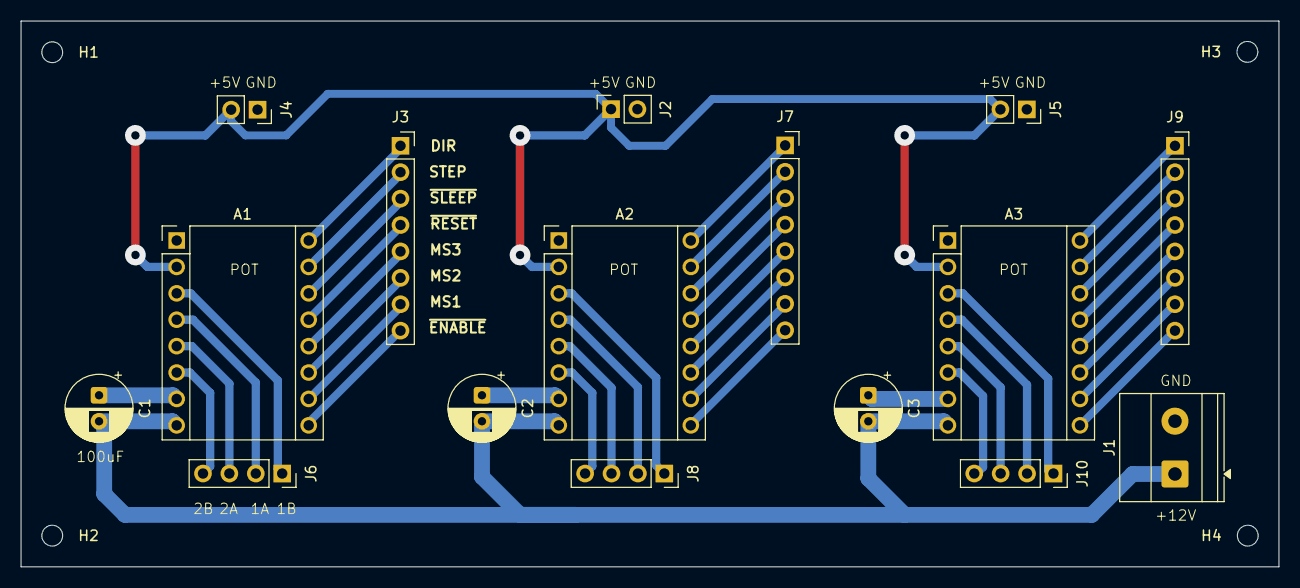
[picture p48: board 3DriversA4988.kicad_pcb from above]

Board: 2 copper layers, 121.0 x 52.5 mm, 20 parts (0 on the bottom side), 39 nets.

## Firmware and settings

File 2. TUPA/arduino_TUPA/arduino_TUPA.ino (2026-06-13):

// ================================
// DEFINIÇÃO DOS PINOS
// ================================

#define DIR_PIN_1  49   // motor U
#define STEP_PIN_1 51
#define ENABLE_PIN_1 47

#define DIR_PIN_2  39   // motor R
#define STEP_PIN_2 41
#define ENABLE_PIN_2 37

#define DIR_PIN_3  29   // motor F
#define STEP_PIN_3 31
#define ENABLE_PIN_3 27

#define DIR_PIN_4  A3   // motor D
#define STEP_PIN_4 A4
#define ENABLE_PIN_4 A5

#define DIR_PIN_5  A0   // motor L
#define STEP_PIN_5 A1
#define ENABLE_PIN_5 A2

#define DIR_PIN_6  A6   // motor B
#define STEP_PIN_6 A7
#define ENABLE_PIN_6 A8

// ================================
// CONFIG
// ================================

#define MAX_SEQ 350

// DM556 com 1600 passos/volta (microstepping configurado no driver)
// 1600 / 4 = 400 passos para 90°
// 400 * 2  = 800 passos para 180° (movimento duplo / '2)
#define PASSOS_90  400
#define PASSOS_180 800

char lineBuffer[50];
char sequencia[MAX_SEQ];

int seqLen = 0;
int DELAY_STEP = 1000;      // µs por half-step (ajustar conforme velocidade)
int DELAY_ENTRE_MOV = 10;

bool recebendo = false;

// ================================
// CONFIGURAR MOTOR
// DM556 lógica invertida: comum em +5V
//   ENABLE: HIGH = habilita, LOW = desabilita
//   DIR:    HIGH = sentido A, LOW = sentido B (invertido em relação ao padrão)
// ================================

bool configurarMotor(char m, int &dirPin, int &stepPin, int &enablePin, int &dir, int &passos) {

    switch(m) {
        // Motor U (motor 1)
        case 'A': dirPin=DIR_PIN_1; stepPin=STEP_PIN_1; enablePin=ENABLE_PIN_1; dir=HIGH; passos=PASSOS_90;  break; // U
        case 'B': dirPin=DIR_PIN_1; stepPin=STEP_PIN_1; enablePin=ENABLE_PIN_1; dir=LOW;  passos=PASSOS_90;  break; // U'
        case 'C': dirPin=DIR_PIN_1; stepPin=STEP_PIN_1; enablePin=ENABLE_PIN_1; dir=HIGH; passos=PASSOS_180; break; // U2

        // Motor R (motor 2)
        case 'D': dirPin=DIR_PIN_2; stepPin=STEP_PIN_2; enablePin=ENABLE_PIN_2; dir=HIGH; passos=PASSOS_90;  break; // R
        case 'E': dirPin=DIR_PIN_2; stepPin=STEP_PIN_2; enablePin=ENABLE_PIN_2; dir=LOW;  passos=PASSOS_90;  break; // R'
        case 'F': dirPin=DIR_PIN_2; stepPin=STEP_PIN_2; enablePin=ENABLE_PIN_2; dir=HIGH; passos=PASSOS_180; break; // R2

        // Motor F (motor 3)
        case 'G': dirPin=DIR_PIN_3; stepPin=STEP_PIN_3; enablePin=ENABLE_PIN_3; dir=HIGH; passos=PASSOS_90;  break; // F
        case 'H': dirPin=DIR_PIN_3; stepPin=STEP_PIN_3; enablePin=ENABLE_PIN_3; dir=LOW;  passos=PASSOS_90;  break; // F'
        case 'I': dirPin=DIR_PIN_3; stepPin=STEP_PIN_3; enablePin=ENABLE_PIN_3; dir=HIGH; passos=PASSOS_180; break; // F2

        // Motor D (motor 4)
        case 'J': dirPin=DIR_PIN_4; stepPin=STEP_PIN_4; enablePin=ENABLE_PIN_4; dir=HIGH; passos=PASSOS_90;  break; // D
        case 'K': dirPin=DIR_PIN_4; stepPin=STEP_PIN_4; enablePin=ENABLE_PIN_4; dir=LOW;  passos=PASSOS_90;  break; // D'
        case 'L': dirPin=DIR_PIN_4; stepPin=STEP_PIN_4; enablePin=ENABLE_PIN_4; dir=HIGH; passos=PASSOS_180; break; // D2

        // Motor L (motor 5)
        case 'M': dirPin=DIR_PIN_5; stepPin=STEP_PIN_5; enablePin=ENABLE_PIN_5; dir=HIGH; passos=PASSOS_90;  break; // L
        case 'N': dirPin=DIR_PIN_5; stepPin=STEP_PIN_5; enablePin=ENABLE_PIN_5; dir=LOW;  passos=PASSOS_90;  break; // L'
        case 'O': dirPin=DIR_PIN_5; stepPin=STEP_PIN_5; enablePin=ENABLE_PIN_5; dir=HIGH; passos=PASSOS_180; break; // L2

        // Motor B (motor 6)
        case 'P': dirPin=DIR_PIN_6; stepPin=STEP_PIN_6; enablePin=ENABLE_PIN_6; dir=HIGH; passos=PASSOS_90;  break; // B
        case 'Q': dirPin=DIR_PIN_6; stepPin=STEP_PIN_6; enablePin=ENABLE_PIN_6; dir=LOW;  passos=PASSOS_90;  break; // B'
        case 'R': dirPin=DIR_PIN_6; stepPin=STEP_PIN_6; enablePin=ENABLE_PIN_6; dir=HIGH; passos=PASSOS_180; break; // B2

        default: return false;
    }
    return true;
}

// ================================
// OPOSTOS (sem alterações)
// ================================

bool saoOpostos(char f1, char f2){

    bool U1=(f1=='A'||f1=='B'||f1=='C');
    bool D1=(f1=='J'||f1=='K'||f1=='L');
    bool F1=(f1=='G'||f1=='H'||f1=='I');
    bool B1_flag=(f1=='P'||f1=='Q'||f1=='R');
    bool R1=(f1=='D'||f1=='E'||f1=='F');
    bool L1=(f1=='M'||f1=='N'||f1=='O');

    bool U2=(f2=='A'||f2=='B'||f2=='C');
    bool D2=(f2=='J'||f2=='K'||f2=='L');
    bool F2=(f2=='G'||f2=='H'||f2=='I');
    bool B2=(f2=='P'||f2=='Q'||f2=='R');
    bool R2=(f2=='D'||f2=='E'||f2=='F');
    bool L2=(f2=='M'||f2=='N'||f2=='O');

    if((U1&&D2)||(D1&&U2)) return true;
    if((F1&&B2)||(B1_flag&&F2)) return true;
    if((R1&&L2)||(L1&&R2)) return true;

    return false;
}

// ================================
// EXECUÇÕES
// DM556: HIGH = habilita, LOW = desabilita
// ================================

void executarSimples(char m){

    int d,s,e,dir,p;
    if(!configurarMotor(m,d,s,e,dir,p)) return;

    digitalWrite(e, HIGH);   // HIGH = habilita no DM556
    digitalWrite(d, dir);

    for(int i=0;i<p;i++){
        digitalWrite(s,HIGH);
        delayMicroseconds(DELAY_STEP);
        digitalWrite(s,LOW);
        delayMicroseconds(DELAY_STEP);
    }

    digitalWrite(e, LOW);    // LOW = desabilita no DM556
    delay(DELAY_ENTRE_MOV);
}

void executarDuplo(char m1,char m2){

    int d1,s1,e1,dir1,p1;
    int d2,s2,e2,dir2,p2;

    if(!configurarMotor(m1,d1,s1,e1,dir1,p1)) return;
    if(!configurarMotor(m2,d2,s2,e2,dir2,p2)) return;

    digitalWrite(e1, HIGH);  // HIGH = habilita no DM556
    digitalWrite(e2, HIGH);

    digitalWrite(d1, dir1);
    digitalWrite(d2, dir2);

    int maxP = max(p1,p2);

    for(int i=0;i<maxP;i++){

        if(i<p1) digitalWrite(s1,HIGH);
        if(i<p2) digitalWrite(s2,HIGH);

        delayMicroseconds(DELAY_STEP);

        if(i<p1) digitalWrite(s1,LOW);
        if(i<p2) digitalWrite(s2,LOW);

        delayMicroseconds(DELAY_STEP);
    }

    digitalWrite(e1, LOW);   // LOW = desabilita no DM556
    digitalWrite(e2, LOW);

    delay(DELAY_ENTRE_MOV);
}

// ================================
// SETUP
// ================================

void setup(){

    Serial.begin(9600);

    // DM556: inicializa ENABLE em LOW (desabilitado)
    pinMode(ENABLE_PIN_1,OUTPUT); digitalWrite(ENABLE_PIN_1, LOW);
    pinMode(ENABLE_PIN_2,OUTPUT); digitalWrite(ENABLE_PIN_2, LOW);
    pinMode(ENABLE_PIN_3,OUTPUT); digitalWrite(ENABLE_PIN_3, LOW);
    pinMode(ENABLE_PIN_4,OUTPUT); digitalWrite(ENABLE_PIN_4, LOW);
    pinMode(ENABLE_PIN_5,OUTPUT); digitalWrite(ENABLE_PIN_5, LOW);
    pinMode(ENABLE_PIN_6,OUTPUT); digitalWrite(ENABLE_PIN_6, LOW);

    pinMode(DIR_PIN_1,OUTPUT); pinMode(STEP_PIN_1,OUTPUT);
    pinMode(DIR_PIN_2,OUTPUT); pinMode(STEP_PIN_2,OUTPUT);
    pinMode(DIR_PIN_3,OUTPUT); pinMode(STEP_PIN_3,OUTPUT);
    pinMode(DIR_PIN_4,OUTPUT); pinMode(STEP_PIN_4,OUTPUT);
    pinMode(DIR_PIN_5,OUTPUT); pinMode(STEP_PIN_5,OUTPUT);
    pinMode(DIR_PIN_6,OUTPUT); pinMode(STEP_PIN_6,OUTPUT);

    Serial.println("READY");
}

// ================================
// LOOP (sem alterações)
// ================================

void loop(){

    if(!Serial.available()) return;

    int len = Serial.readBytesUntil('\n', lineBuffer, sizeof(lineBuffer)-1);
    lineBuffer[len]='\0';

    if(strcmp(lineBuffer,"<START>")==0){
        recebendo = true;
        seqLen = 0;
        return;
    }

    if(strcmp(lineBuffer,"<END>")==0){

        unsigned long t0 = micros();

        for(int i=0;i<seqLen;i++){
            if(i<seqLen-1 && saoOpostos(sequencia[i],sequencia[i+1])){
                executarDuplo(sequencia[i],sequencia[i+1]);
                i++;
            }else{
                executarSimples(sequencia[i]);
            }
        }

        unsigned long t1 = micros();

        Serial.print("DONE ");
        Serial.println((t1-t0)/1000000.0);

        recebendo=false;
        return;
    }

    if(recebendo){

        if(strncmp(lineBuffer,"<SPEED:",7)==0){
            DELAY_STEP = atoi(&lineBuffer[7]);
            return;
        }

        if(strncmp(lineBuffer,"<DELAY:",7)==0){
            DELAY_ENTRE_MOV = atoi(&lineBuffer[7]);
            return;
        }

        if(seqLen < MAX_SEQ){
            sequencia[seqLen++] = lineBuffer[0];
        }
    }
}

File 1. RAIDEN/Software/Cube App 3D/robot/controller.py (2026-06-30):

import logging
import time

import pygame
import serial
import serial.tools.list_ports

logger = logging.getLogger(__name__)

DEFAULT_PORT     = "COM4"
DEFAULT_BAUDRATE = 9600
DEFAULT_SPEED    = 1000
DEFAULT_DELAY    = 0
CONNECT_WAIT_S   = 3


class RobotController:
    def __init__(self):
        self.ser = None
        self.port = DEFAULT_PORT
        self.speed = DEFAULT_SPEED
        self.delay = DEFAULT_DELAY
        self.last_solve_time = "--"
        self.last_solution = None
        self.last_move_count = "--"
        self.is_busy = False
        self.auto_connect()

    # ------------------------------------------------------------------
    # Conexão serial
    # ------------------------------------------------------------------

    def auto_connect(self):
        ports = [p.device for p in serial.tools.list_ports.comports()]
        if self.port in ports:
            self.connect(self.port)
        elif ports:
            self.connect(ports[0])
        else:
            logger.warning("Nenhuma porta serial encontrada.")

    def connect(self, port: str) -> bool:
        """
        Abre a conexão serial com o robô.
        O sleep de 3s aguarda o reset do Arduino após DTR.
        Atenção: bloqueia a thread principal — idealmente rodar em thread separada.
        """
        try:
            if self.ser:
                self.ser.close()
            ser = serial.Serial()
            ser.port = port
            ser.baudrate = DEFAULT_BAUDRATE
            ser.timeout = 0.1
            ser.setDTR(False)
            ser.open()
            time.sleep(CONNECT_WAIT_S)
            self.ser = ser
            self.port = port
            logger.info("Conectado em %s", port)
            return True
        except serial.SerialException as e:
            logger.error("Falha ao conectar em %s: %s", port, e)
            self.ser = None
            return False

    # ------------------------------------------------------------------
    # Comunicação
    # ------------------------------------------------------------------

    def check_for_done(self):
        """Verifica se o robô enviou 'DONE'. Deve ser chamado a cada frame."""
        if not self.ser or not self.is_busy:
            return
        if self.ser.in_waiting:
            try:
                line = self.ser.readline().decode().strip()
                if line.startswith("DONE"):
                    parts = line.split()
                    if len(parts) > 1:
                        self.last_solve_time = parts[1]
                    self.is_busy = False
                    pygame.event.clear()
            except Exception as e:
                logger.warning("Erro ao ler serial: %s", e)

    def send_moves(self, sequence_str: str):
        """Envia uma sequência de movimentos ao robô via serial."""
        if not self.ser or not self.ser.is_open:
            logger.warning("Tentativa de envio sem conexão serial.")
            return
        try:
            self.ser.write(b"<START>\n")
            self.ser.write(f"<SPEED:{self.speed}>\n".encode())
            self.ser.write(f"<DELAY:{self.delay}>\n".encode())
            for move in sequence_str:
                self.ser.write((move + "\n").encode())
                time.sleep(0.01)
            self.ser.write(b"<END>\n")
            self.is_busy = True
        except serial.SerialException as e:
            logger.error("Erro ao enviar movimentos: %s", e)
            self.is_busy = False

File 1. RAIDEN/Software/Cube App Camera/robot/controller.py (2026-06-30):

"""Robot serial controller — manages the Arduino connection and move dispatch."""

import logging
import time

import serial
import serial.tools.list_ports

from config import SERIAL_BAUDRATE, SERIAL_TIMEOUT, SERIAL_INIT_DELAY, MOVE_TABLE

logger = logging.getLogger(__name__)


class RobotController:
    """Handles opening, sending, and polling the serial connection to the robot."""

    def __init__(self):
        self._serial: serial.Serial | None = None
        self.is_busy = False
        self.last_elapsed: str = "--"

    # ------------------------------------------------------------------
    # Connection management
    # ------------------------------------------------------------------

    def list_ports(self) -> list[str]:
        return [p.device for p in serial.tools.list_ports.comports()]

    def connect(self, port: str) -> bool:
        """Opens the serial port without triggering Arduino reset (DTR disabled).

        Returns True on success, False on failure.
        """
        if self._serial is not None:
            return True  # already connected

        try:
            s = serial.Serial()
            s.port     = port
            s.baudrate = SERIAL_BAUDRATE
            s.timeout  = SERIAL_TIMEOUT
            s.setDTR(False)  # prevent Arduino auto-reset on connect
            s.open()
            time.sleep(SERIAL_INIT_DELAY)  # wait for firmware boot
            self._serial = s
            logger.info("Serial connected to %s", port)
            return True
        except serial.SerialException:
            logger.exception("Failed to connect to %s", port)
            self._serial = None
            return False

    def disconnect(self):
        if self._serial and self._serial.is_open:
            self._serial.close()
            logger.info("Serial disconnected")
        self._serial = None

    @property
    def is_connected(self) -> bool:
        return self._serial is not None and self._serial.is_open

    # ------------------------------------------------------------------
    # Sending moves
    # ------------------------------------------------------------------

    def send_moves(self, sequence: str, speed: int, delay: int) -> bool:
        """Sends a pre-encoded character sequence to the robot.

        *sequence* is already in robot format (single chars from MOVE_TABLE).
        Returns False if the connection is not open or the robot is busy.
        """
        if not self.is_connected or self.is_busy:
            return False
        if not sequence:
            return False

        try:
            self.is_busy = True
            s = self._serial
            s.reset_input_buffer()
            s.reset_output_buffer()
            s.write(b"<START>\n")
            s.write(f"<SPEED:{speed}>\n".encode())
            s.write(f"<DELAY:{delay}>\n".encode())
            for move in sequence:
                s.write((move + "\n").encode())
                time.sleep(0.005)
            s.write(b"<END>\n")
            logger.info("Sent %d-move sequence to robot", len(sequence))
            return True
        except serial.SerialException:
            logger.exception("Serial write failed")
            self.is_busy = False
            return False

    # ------------------------------------------------------------------
    # Polling for completion
    # ------------------------------------------------------------------

    def check_for_done(self) -> bool:
        """Non-blocking poll. Returns True if a DONE message was just received."""
        if not self.is_connected or not self._serial.in_waiting:
            return False
        try:
            line = self._serial.readline().decode(errors="replace").strip()
            if line.startswith("DONE"):
                parts = line.split()
                self.last_elapsed = parts[1] if len(parts) > 1 else "?"
                self.is_busy = False
                logger.info("Robot finished in %s s", self.last_elapsed)
                return True
        except serial.SerialException:
            logger.exception("Serial read failed")
        return False

    # ------------------------------------------------------------------
    # Move conversion helper
    # ------------------------------------------------------------------

    @staticmethod
    def notation_to_robot(notation_sequence: str) -> str:
        """Converts a space-separated Kociemba notation string to robot chars."""
        try:
            return "".join(MOVE_TABLE[m] for m in notation_sequence.split())
        except KeyError as exc:
            raise ValueError(f"Invalid move: {exc}") from exc

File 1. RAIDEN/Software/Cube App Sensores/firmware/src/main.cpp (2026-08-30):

#include <Arduino.h>
#include "motion/motion.h"
#include "sensing/sensing.h" 

static const uint32_t BAUD = 115200;   // deve casar com host/app/communication/embedded.py
static const char TERM = '*';

static char rx[400];                    // Vetor RX Obs: cabe M2OP (200–300 movimentos) + folga
static int  rxLen = 0;

static void handleCommand(char* cmd, int n) {
    if (n <= 0) { Serial.print("e0*"); return; }

    // --- Comandos de subsistema  --- //
     if (cmd[0] == 'c' && cmd[1] == '0') {           // CALIBRATE
        int rc = calibrateSolved();
        if (rc == 4) { Serial.print("e4*"); return; }
        if (rc == 5) { Serial.print("e5*"); return; }
        for (uint8_t c = 0; c < NUM_COLORS; c++) { Serial.print(globalRef[c].h, 1); Serial.print('_'); }
        for (uint8_t c = 0; c < NUM_COLORS; c++) { Serial.print(globalRef[c].s, 3); Serial.print('_'); }
        Serial.print(whiteSatThresh, 3); Serial.print('_');
        Serial.print(whiteBal[0], 0); Serial.print('_');
        Serial.print(whiteBal[1], 0); Serial.print('_');
        Serial.print(whiteBal[2], 0);
        Serial.print(TERM);
        return;
    }
    if (cmd[0] == 's' && cmd[1] == '0') {           // SCAN
        bool status[NUM_SENSORS];
        sensingScan(status);
        for (uint8_t i = 0; i < NUM_SENSORS; i++)
            Serial.print(status[i] ? '1' : '0');
        Serial.print(TERM);
        return;
    }
    if (cmd[0] == 'k' && cmd[1] == '_') {           // KOLOR: lê 1 sensor lógico
        int ns = atoi(cmd + 2);
        if (ns < 0 || ns >= NUM_SENSORS) { Serial.print("e3*"); return; }
        char col = detectColorLogical((uint8_t)ns);
        Serial.print(col); Serial.print(TERM);      // ex.: W*  (ou X* se inválida)
        return;
    }
    if (cmd[0] == 'r' && cmd[1] == '0') {           // SENSE
        int bad = senseComplete();
        if (bad > 0) { Serial.print("e6*"); return; }     // leitura incompleta
        for (uint8_t f = 0; f < 6; f++)                    // STATE: 48 chars,
            for (uint8_t p = 0; p < 8; p++)                // ordem canônica URFDLB,
                Serial.print(scramble[f][p]);              // posição 0..7 por face
        Serial.print(TERM);
        return;
    }

    // --- Config opcional (stress test de velocidade) ---
    if (cmd[0] == 'v' && cmd[1] == '_') { motionSetStepDelay(atoi(cmd + 2)); Serial.print("d*"); return; }
    if (cmd[0] == 'g' && cmd[1] == '_') { motionSetMoveGap(atoi(cmd + 2));   Serial.print("d*"); return; }

    // --- Caso geral: sequência de 1..N movimentos A–R ---
    for (int i = 0; i < n; i++)
        if (!motionIsValid(cmd[i])) { Serial.print("e1*"); return; }

    unsigned long us = motionExecuteSequence(cmd, n);
    Serial.print("d_");                 // 'd' + arg opcional com o tempo (host pode ignorar)
    Serial.print(us / 1000000.0, 3);
    Serial.print(TERM);
}

void setup() {
    Serial.begin(BAUD);
    motionInit();
    sensingInit();
    detectColorLoadDefaults(); 
    Serial.print("READY*");
}

void loop() {
    while (Serial.available()) {
        char ch = (char)Serial.read();
        if (ch == '\r' || ch == '\n') continue;
        if (ch == TERM) {
            rx[rxLen] = '\0';
            handleCommand(rx, rxLen);
            rxLen = 0;
        } else if (rxLen < (int)sizeof(rx) - 1) {
            rx[rxLen++] = ch;
        } else {
            rxLen = 0;
            Serial.print("e2*");        // overflow de linha
        }
    }
}

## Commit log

2026-06-13 código com lógica invertida para o tupã
2026-06-30 Códigos refatorados e pastas organizdas
    Se algo quebrar reverter esse comit
    [3DriversA4988-B_Cu.gbr, 3DriversA4988-B_Mask.gbr, 3DriversA4988-B_Paste.gbr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]
2026-06-30 Arquivo inutil deletado
    [PCB Tupan.kicad_pcb, PCB Tupan.kicad_sch]
2026-07-19 Arquivos de Teste Adicionados
2026-08-30 Arquivos de Demonstração dos Motores
2026-08-30 Organização das pastas
    [Cap_garra_v3.f3d, Cap_garra_v3.step, Cap_garra_v3.stl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]
2026-08-31 Código de desmontração do sensor novo
2026-09-05 PCB Sensores
    [PCB Sensores.kicad_pcb, PCB Sensores.kicad_sch]
2026-09-08 Resistor Corrijido
    [PCB Sensores.kicad_pcb, PCB Sensores.kicad_sch]
2026-09-08 PCB Sesnores final
    [PCB Sensores-B_Cu.gbr, PCB Sensores-B_Mask.gbr, PCB Sensores-B_Paste.gbr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]
